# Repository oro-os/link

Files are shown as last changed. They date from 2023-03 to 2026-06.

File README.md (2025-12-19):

<div align="center">
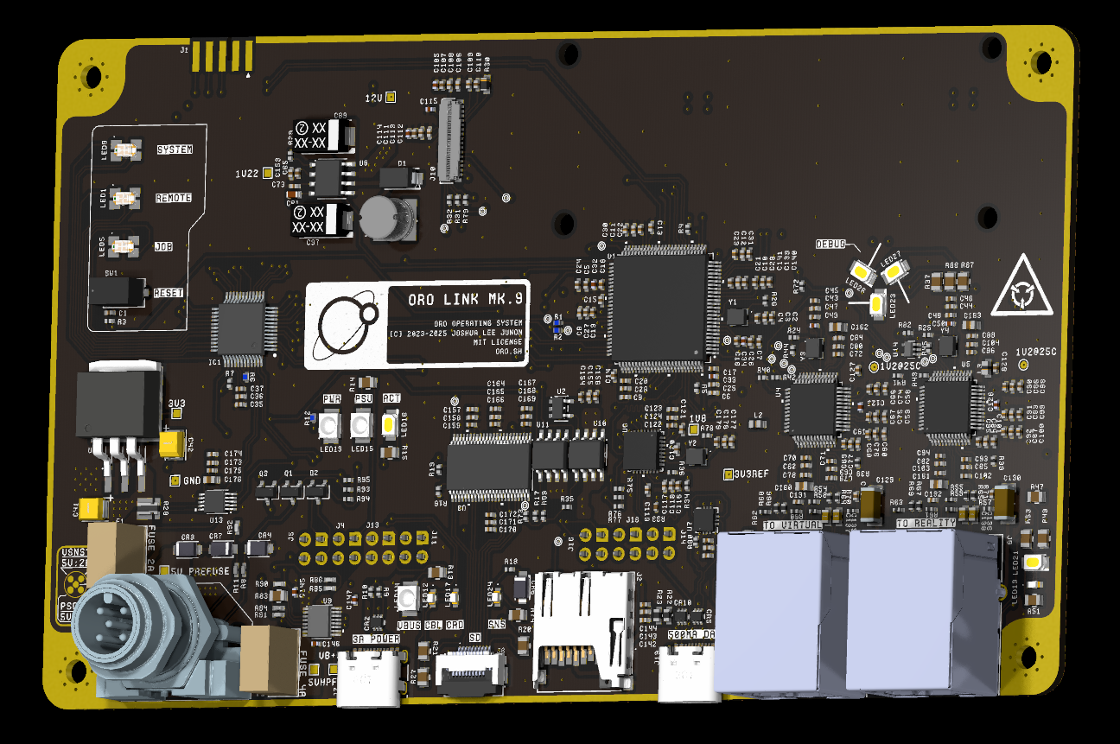
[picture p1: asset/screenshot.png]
	
</div>

# Oro Link

This is the Oro Link project, a set of custom PCBs, firmware, and server
infrastructure for the testing of the Oro Operating System via CI/CD pipelines.

The link is a physical board that interfaces with the ports and headers
of supported computers, devices, and boards, and runs firmware to obtain builds of
the Oro kernel and associated modules to send to the System Under Test (SUT)
for automated testing and reporting.

The Oro Link allows contributors to the Oro project direct access - via
pull requests - to test changes directly on real hardware
alongside emulated environments, allowing for changes to be tested
against niche or problematic hardware configurations.

## Project Layout

All PCBs are located in `pcb/`, where all of the server infrastructure and firmware for the PCBs
is located in `firmware/` since it's a workspace with some local dependencies (e.g. the protocol
spoken between the boards and the CI/CD daemon).

# License

<div align="center">
	
</div>

Part of the Oro Operating System project.

The Oro Link is released to the public, WARRANTY FREE
and provided AS IS. The Oro project and its contributors are NOT
responsible for any damages caused by the purchase, assembly, or operation
of the device, under any circumstances.

The Oro Link's PCB and associated custom footprints are released
under the [MIT License](LICENSE).

Unless otherwise specified, all Oro Link firmware (software code)
and all other materials are licensed under the same license.

Firmware dependencies are under their respective licenses.

The _Enter Command_ font used in part for text display is released CC-BY-4.0
by [Font End Dev (jeti)](https://fontenddev.com).

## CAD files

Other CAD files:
ProgrammerHousing.blend

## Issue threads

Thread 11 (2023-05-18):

Re-enable WWDG

Qix-, 2023-05-18:
The WWDG subsystem is not being initialized properly by the generated cubemx code, so the chip is going directly into reset after booting. Disable it for now and re-enable it later.

Qix-, 2023-05-18:
This is because the initialization circuit isn't waiting until the watchdog counter is within the window, thus immediately triggering a reset interrupt.

Qix-, 2023-11-23:
Going to close this. It's not been necessary, we're not operating these in realtime, and right now there's a strange bug somewhere in the netcode libs in the firmware that causes TFTP over UDP to lag the entire CPU, which would trigger the watchdog timer anyway.

Closed 2023-11-23.

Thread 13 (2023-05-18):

Fix power switch footprints

Qix-, 2023-05-18:
The power switch THT footprints (on the back top-right side of the link) are wrong; the pin columns are too close together.

Might also need to notify componentsearchengine of a flaw.

Qix-, 2023-05-30:
Nope, they were custom. My fault.

Qix-, 2023-05-30:
Welp that's frustrating. The datasheet is _very_ confusing.

The datasheet shows this:

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

We're using the 25146NAH model, which is listed as having 2.54mm pin centers. The diagram on the right clearly states "shown with 5.08mm centers", which is for the other column of models.

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

So, one might assume to make all centers 2.54mm for this particular model. That's the error on my part - the centers are indeed 2.54 between the pins in the same column, **but are always 5.08mm centered _between_ the columns**. This is only made evident by looking at the previous diagram for an unrelated model which is labelled "shown with 2.54mm spacing". Note that, again, the columnar spacing is still 5.08mm.

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

Very frustrating indeed. I've confirmed this is indeed the case with a caliper, and it's not a problem to have caught it in this revision - better than a later revision.

The next issue is that the parts aren't stocked until october, and I only have two of them. So I might just switch them out entirely and avoid APEM in the future. The programmer already has some nice switches that I believe would work from Werth, so I might just bring those over instead.

Closed 2023-05-31.

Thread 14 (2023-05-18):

Research USB D+/- resistors

Qix-, 2023-05-18:
Some designs I've seen use resistors on the D+/- lines of the USB. I'm not sure if they're necessary for this particular MCU but I should check. Right now they're direct-wired. The datasheet probably mentions them but I missed them, and no testing of the USB has been done yet to know.

Qix-, 2023-05-21:
It doesn't appear to be the case. Might be worthwhile to add R0 resistors inline though.

Qix-, 2023-05-30:
I can't find anything in the datasheet that would suggest this (although the datasheet is massive, so maybe I'm missing it). No sections regarding external components mentions them.

Closed 2023-05-30.

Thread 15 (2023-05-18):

Put pulldowns on MOSFET gate lines

Qix-, 2023-05-18:
While the MCU has built-in resistors, if the MCU is not on the board (during dev) or isn't functioning correctly, the default state should be low. Since the MOSFETS latch, we need to pull down the gate lines and drain out their current.

Closed 2023-05-21.

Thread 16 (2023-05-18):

Add debug pins on signal lines

Qix-, 2023-05-18:
At least for the next few revisions, debug pins should be put on the signal lines for various parts of the board. While soldering on the MCU pin lead wires is kind of fun and looks cool, really slows down the process and introduces a ton of surface area for error. Remove them once the board is ready for a full test.

Qix-, 2023-06-02:
I've gone back and forth on this about ten times now and decided it's not worth it given they'll only add signal integrity issues.

1. The ethernet SPI lines work, those are already tested.
2. The i2c lines for the indicator lights already work, those are already tested.
3. The SWD lines "work" (ST did not do a _great_ job implementing them) and a programmer is already designed and will be assembled at the same time as the link board. Plus, worst case, I can always solder to the Oro pad as it gives enough space.
4. The only debug lines left are the OLED SPI signals, which are NOT rated for 5v line the arduino pumps out, and I don't have any signal translators on hand (I could get some but.. why) but ARE rated for the MCU's voltages (as far as I can understand the very, very poor documentation). If this doesn't work, I'm going to resort to i2c and just... eat the framerate drop, I guess.
5. All of the power lines and signal lines have THTs associated with them already between the button and the power jack, and the power converter has been tested oodles of times at this point and is known to work.

Other than that, there are no other debug THTs that were marked for population, thus they have all been removed.

weiliddat, 2023-06-07:
> 3. The SWD lines "work" (ST did not do a _great_ job implementing them) and a programmer is already designed and will be assembled at the same time as the link board. Plus, worst case, I can always solder to the Oro pad as it gives enough space.

What’s the difference between using SWD line and using the programmer?

Closed 2023-05-30.

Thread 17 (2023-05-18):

Re-create footprint for schottky diode on 12v OLED step-up circuit

Qix-, 2023-05-18:
On the OLED's 12v step-up circuit, the schottkey footprint is really ambiguous as to where the polarity band should go when populating. I've soldered it wrong twice now, causing overcurrent in the step up IC and almost starting a small lab fire 🙃 Need to modify the silkscreen so it's clear which side the polarity band needs to go.

Closed 2023-05-31.

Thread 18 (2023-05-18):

Consider another OLED screen

Qix-, 2023-05-18:
These OLED screens are either faulty or their docs are wrong. Two tests in a row have garnered absolutely nothing - no backlighting, no response, nothing from any test, and turning on the power leads to the cable getting hot (still researching if that's normal).

Qix-, 2023-05-21:
I honestly thing it's our best bet. It's in supply, it's high resolution, it's a good shape, and it's cheap. It's white, which fits Oro's branding, and has decent documentation (for the actual display chip - the OLED itself has rather poor documentation).

Going to give it another go, but keep this open for now.

Qix-, 2023-07-02:
Just tried this with a Nucleo development board whereby the data signals are indeed the correct voltage. Nada. The ribbon is still getting insanely hot.

I think I'm going to make a breakout board for this and try to get to the bottom of whatever is causing this issue.

Qix-, 2023-07-13:
Finally found the problem with OLEDs.

Made a breakout board for the OLED port and just got it in yesterday. Soldered it all together today, hooked up one of the units and did some basic "same net" testing (idk what the real term is).

Turns out, not much connects, but a few pins - 1, 24, 26, and 30 - did. On the existing schematic, 1 and 30 were NC, and 24 and 26 were two of the bits of the data bus, which made _absolutely no sense_.

But it did. If you flip the pins upside-down, they correspond to (existing pins) 2, 6, 8 and 31. If you check the datasheet for the OLED screen, those are all of the 12v pins exactly.

So I went back and checked the datasheet for the connector itself. Port numbering looks correct. Then I check the datasheet for the OLEDs and notice something a little annoying.

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

Yep. That's the _bottom_ of the connector. I suppose it makes sense, it's just highly confusing. The ports are indeed flipped, and the two datasheets do not agree with the port numbering. I suppose lesson learned.

Will wire up the breakout board to a development Nucleo board soon just to make sure _something_ is working but as it stands this has solved the elusive OLED screen problem.

Going to close.

Closed 2023-07-13.

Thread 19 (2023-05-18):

Step down OLED logic lines to acceptable levels

Qix-, 2023-05-18:
Pending #18 as well as a MM test, step down the data lines from TTL to 2.8 or 2.4 (can't remember). Right now I _think_ they're 3v3 (again, need to test) so that might be frying the OLED data circuits.

Qix-, 2023-05-21:
This actually isn't needed. The Nano is doing SPI at 5v (or, at least, I bit-banged it at 5v at one point). Further I think there was a current leak as the ribbon was getting hot, so might be a power thing. I've tried to remedy this in b8ee6cae316a341383993e59f98217af3e48cfd9 with pulldowns in some cases instead of direct ties. We'll see if that fixes the issue.

The downside is I'll have to test using an entire board.

Closed 2023-05-21.

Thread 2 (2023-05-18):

Replace small 0.1u caps

Qix-, 2023-05-18:
They're too small and hand-solder correctly only about 60% of the time.

Qix-, 2023-05-21:
Make sure they're at lease 10v rated.

Closed 2023-05-30.

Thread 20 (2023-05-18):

Replace inline ETH resistors

Qix-, 2023-05-18:
The inline resistors between the transformer and the ethernet controller IC are also too small to reliably hand solder (perhaps successful 80% of the time). Replace them for slightly bigger packages. The packages of the resistors in the bottom right of the board (as of rev 4, 072a0d0983c60869b018b50924e15593dac61d36) by the GNDPWR mounting hole solder perfectly and are probably as small as I'm willing to work with.

Closed 2023-05-30.

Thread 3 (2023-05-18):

Replace Oro 6p VCC line with T_VCC input

Qix-, 2023-05-18:
The current VCC line on the Oro test pad is used for powering the board but

1. it's unnecessary as the board will always be in an environment where it has power, and
2. the V3MODS doesn't have enough current rating to power everything on the board anyway

So instead, we need to give back the reference voltage via the link's T_VCC line. This also reduces the BOM, which is nice.

Closed 2023-05-21.

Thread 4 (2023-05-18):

Tie programmer NRST to GND

Qix-, 2023-05-18:
The programmer will be used in Under Reset mode, thus the NRST on the link needs to be tied to GND. I don't know why, this was just the findings during test.

Closed 2023-05-19.

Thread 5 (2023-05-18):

Remove "power from link" switch on programmer module

Qix-, 2023-05-18:
Title. Given #3 the extra switch is no longer necessary.

Closed 2023-05-21.

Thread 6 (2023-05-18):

Change Oro 6p GND pin to PB2/BOOT1 pin

Qix-, 2023-05-18:
... and tie it to 3v3 on the programmer module when the flash switch is on. **Use T_VCC line instead of 5v to tie it high** and also use this to power the flash warning LED circuit instead (or, perhaps, use it to power a MOSFET and tie the whole thing low with a pull-down).

Closed 2023-05-21.

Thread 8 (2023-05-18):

Add debug pins to programmer

Qix-, 2023-05-18:
so that we can solder on a single v3mods to a programmer board and use it over and over again instead of having to rely on shoddily soldered lead wires.

Closed 2023-05-21.

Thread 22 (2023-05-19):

Reverse polarity of cyan LED

Qix-, 2023-05-19:
Right now the cyan LED is being used as link status, which is high when there is _no_ link, and low when there _is_ a link. We should invert it using a single gate inverter.

Qix-, 2023-05-19:
Actually the link LED might just be a case of needing to reverse it and connect to VCC instead of GND.  Need to re-read the datasheet to make sure that's the case. Not sure if it's current sinking it when low.

Qix-, 2023-05-19:
Yes, correct. Reversing polarity and hooking it up to VCC instead of GND will work.

Closed 2023-05-19.

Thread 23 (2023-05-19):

Move ETH line ESD IC's before transformer

Qix-, 2023-05-19:
Woops. Their breakdown voltage is 4.5v, but the lines are at 28+v. That might be why the chip itself is working fine but nothing is being transmitted. I also measured the voltage between GNDPWR and GND and indeed there were 28v. I misread the diagram...

Will test desoldering them to see if, at least, the lines work.

Qix-, 2023-05-19:
In fact, maybe it's worth simply removing them entirely. The ENC28J60 already has ESD protection built in, up to 2kv.

Closed 2023-05-19.

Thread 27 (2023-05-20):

Combine three posts on programmer

Qix-, 2023-05-20:
Right now the programmer has 6 posts - three in the oro 6p landing mount pattern, and three in an inverse configuration to mount the middle piece to the programmer. This is actually unnecessary and only removes room for the brace mounting holes, which were a bit painful to get in. The nylon m3's can instead just be daisy-chained together in the same configuration as the 6p landing mount holes to save space for the brace mounts.

Closed 2023-05-21.

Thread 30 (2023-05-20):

Re-layout power caps

Qix-, 2023-05-20:
The power caps on the voltage regulator make no sense where they're currently placed. They need to be much closer to the pins.

Closed 2023-06-02.

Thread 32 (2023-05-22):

Replace 10k resistors with smaller package

Qix-, 2023-05-22:
The current 10k's are ridiculously huge. They really need to be a bit smaller.

Closed 2023-05-30.

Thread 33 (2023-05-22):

Replace GNDPWR capacitors with smaller package

Qix-, 2023-05-22:
... if possible. They're one of the largest auxiliary components on the board at this point.

Closed 2023-05-30.

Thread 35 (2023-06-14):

Replace crimp probe receptacles with solder cup

Qix-, 2023-06-14:
On the programmer, the crimp receptacles look nice but are functionally very hard to CAD for, as after disassembly and re-assembly the metal has fatigued just enough not to have any grip anymore. Now they're sliding everywhere.

I'll trade _functionally solid_ for _I might need to get more solder cup parts_ any day.

Qix-, 2023-06-30:
Closing in lieu of a non-fancy programmer.

Closed 2023-06-30.

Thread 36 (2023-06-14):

Replace 7oz spring force probes with 4oz

Qix-, 2023-06-14:
The 7oz spring force is way too much for what is needed.

Qix-, 2023-06-30:
Closing in lieu of a non-fancy programmer.

Closed 2023-06-30.

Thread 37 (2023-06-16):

Make power terminals on VGA mount 2.54mm 2p slots

Qix-, 2023-06-16:
Right now the VGA mount's power holes were meant for just some wires but I realize now that makes no sense. Further, they're about 3mm apart which means I can't soldier on a 2p post directly. The holes are also too small, and the rings are too narrow for a good solder joint.

Better to import one of the 2p footprints and use that instead.

Closed 2023-07-02.

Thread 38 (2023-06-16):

Switch out power switch for another one

Qix-, 2023-06-16:
The mounting pads on the power switch are now correctly positioned but the copper surrounding the hole is too narrow to make a good solder joint.

Qix-, 2023-06-30:
I think I just need to replace it entirely. The switch is out of stock on Mouser and will be for a while, and I have one left.

Qix-, 2023-07-01:
This power switch is a continual pain in my ass. Further, it's not really useful given that the PSU always has a switch of its own.

Going to simply remove it.

Closed 2023-07-01.

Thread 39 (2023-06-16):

Put all component voltage sources behind MOSFETs

Qix-, 2023-06-16:
Debugging some voltage stuff is causing issues when they are all eating power at boot. Being able to programmatically turn on and off their power is going to prove useful.

Qix-, 2023-07-27:
For anyone coming across this issue in the future, this was a major mistake and the sole reason why there will be a revision 7.

Closed 2023-07-01.

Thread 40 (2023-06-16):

Get rid of programmer and landing pad, integrate V3MODS directly onto link

Qix-, 2023-06-16:
Title. The programmer is a cool idea aesthetically but isn't really helping me debug this thing. Plus, the leads between the two are so touchy that the SWD lines aren't really working well at all currently.

I also need to get *ANY* programmer + MCU working to understand how this thing needs to be wired up, because I just can't get the STM32 working with the programmer.

Bummer.

Qix-, 2023-06-30:
Update: I made a second board with just the MCU. It worked first try **at 8000KHz**, no less. The connection has been dropped **ONCE** since I started. Firmware flashes instantly. Debug LED and the PSU_ON MOSFET both worked first try.

So there was clearly an issue with the first board, either with the chip or with the programmer setup (I'm leaning toward the second).

The V3MODS are cheap. They're in stock pretty much all the time. Having them directly on the boards would be great.

Closed 2023-07-02.

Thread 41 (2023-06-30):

BOOT0 / BOOT1 pullup/pulldown are backwards

Qix-, 2023-06-30:
BOOT0 is currently pulled up and BOOT1 pulled down, which is backwards. Oops. As it stands, a standalone board would immediately and irreversibly boot into programmer mode. This is of course remedied with lead wires shorted to GND/3V3 respectively but that of course doesn't 'solve' the issue.

Closed 2023-07-01.

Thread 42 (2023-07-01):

Add flash switch

Qix-, 2023-07-01:
The flash switch will switch BOOT pins on the back to accompany the programmer. In _theory_ I could flash my own programmer to use the GPIO pins but the switches are cheap and SMT and I don't want to bit off more than I can chew with the already sort of stingy programmers.

Qix-, 2023-07-02:
Ended up just going with a few MOSFETs and a short 2p configuration

Closed 2023-07-02.

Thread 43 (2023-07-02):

Replace 3v3 regulator with one with higher amperage ratings

Qix-, 2023-07-02:
Pretty sure we're going to be bumping up against that 1A point on the voltage regulator. In fact I'm pretty sure that's why I've seen a few weird voltage characteristics during testing.

Closed 2023-07-02.

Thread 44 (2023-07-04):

Make RJ45 inverter board

Qix-, 2023-07-04:
Finally found a board-mounted RJ45 connector (not receptacle) and ordered 10 of them. Just need to build the RJ45 back panel reverse card using the existing non-magnetic jacks I have.

Qix-, 2023-07-05:
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
certainly one of the weirder parts I've made.

Closed 2023-07-05.

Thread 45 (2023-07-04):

Find heatsinks for MCU

Qix-, 2023-07-04:
Title. This thing needs a sink.

Qix-, 2024-06-02:
Not necessary anymore after switching to Embassy. Current draw is significantly lower due to clever usage of async, and thus temps have remained quite low - chip remains only slightly warm to the touch.

Closed 2024-06-02.

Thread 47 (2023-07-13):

Re-wire OLED port to match corrected numbering

Qix-, 2023-07-13:
After #18 was finally solved, I need to do some testing and - assuming the tests go OK - re-wire the OLED port to have the flipped numbering sequence.

Closed 2023-07-14.

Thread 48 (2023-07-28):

Remove MOSFETs in lieu of reset pins

Qix-, 2023-07-28:
Learned my lesson. #39 was a mistake.

Qix-, 2023-08-02:
Just the eth, oled and indicator subcircuits.

Closed 2024-06-08.

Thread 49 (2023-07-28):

Switch to W5100

Qix-, 2023-07-28:
The ENC28J60's read/write rising/falling edge mechanism is inherently incompatible with STM32s.

From [this comment](https://community.st.com/t5/stm32-mcu-products/hi-everyone-i-m-trying-to-connect-my-stm32f429i-disc1-to-lan/m-p/282696/highlight/true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):

> The ENC28J60 is an older ethernet MAC/PHY and has some issues when used with an STM32. Microchip has a newer ENC424J600 10/100 ethernet controller with a much better SPI interface. I used both many years ago. The older ENC28J60 is not easy to use and I would not recommend going forward with it since there is a far better alternative.

> One issue is read/write clock edge for the SPI clock. Writes to the ENC28J60 are on the rising edge, but read are clocked on the falling edge. You need to reconfigure the SPI clock polarity depending on transfer direction. STM32 SPI ports only read/write on the same edge. Check the timing diagrams on the ENC28J60 to see how data is read and written. If you use the wrong edge you get invalid data, as you see with 0xFF.

> Also, make sure the chip select remains on past the last bit clocked in/out. The SPI port has a flag to inform when shifting is complete. Otherwise data is lost.

Would have never guessed, to be honest. This is a huge bummer, and renders the rev6 effectively. Switching clock polarity doesn't seem to work anyway as the comment suggests.

Going to do some more research tomorrow with the standalone ENC28J60 modules + the nucleo boards just to see if that's really the case. The external ethernet jack is correctly killing the link LEDs when hard-reset but the system ethernet jack is not. This also indicates a problem with the circuit on the system ethernet, although both have been tested standalone.

Further, it's probably worth upgrading to 100 instead of staying on 10, anyway.

Qix-, 2023-07-31:
The assertion made in the comment doesn't seem to be true. Using a logic analyzer on this shows that the chip is actually sending/receiving correctly (figured out the ethernet chip clock wasn't soldered on all the way for the external ethernet, hence why I was getting garbage back from it). It appears to be reading/writing just fine.

Another lesson learned is that MCU pins pulled high via an external resistor (as is the case with many signal lines on the board) need to be configured as open drain outputs rather than push pull. I knew this conceptually but hadn't actually bothered to check the IOC config for them. This is why the chip select line wasn't doing anything, thus the ethernet chips seemed bricked.

I will put this on the backburner for now as I think 10base-t will be sufficient.

Qix-, 2023-08-05:
Upon discussing with the lead Embassy dev over Matrix it was suggested to switch to the W5500 instead. Further, it already has a fully featured driver for Embassy which will save considerable time.

Closed 2024-06-08.

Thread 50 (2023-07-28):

Investigate STLINK serial debugging

Qix-, 2023-07-28:
I can't seem to get the STLINK to pick up any sort of serial output, which is making debugging quite difficult. Need to investigate why this is the case.

Qix-, 2023-07-28:
Already on serial 7 via the VCP. Just need to use arduino's COM port viewer to see the output, weirdly enough the IDE doesn't include this functionality.

Closed 2023-07-28.

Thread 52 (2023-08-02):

Put 5VSB, RST and PWR onto photocouplers instead of MOSFET

Qix-, 2023-08-02:
Title. The 5VSB is hitting some caps on the mobo and is not properly reading Vgs on the FET. Switching to a photocoupler will probably help.

For now, bridging unconditionally is the best workaround. In theory we could also replace the N-Channel with a P-Channel assuming the G/D/S pins match up and switch the gate line to an output open drain.

Qix-, 2023-08-04:
Also, need to put the power switches on them as well. At least on this board, the RST is working but PWR is not. I just need to use proper photocouplers for those.

Further, the ATX24's PS_OK line has been replaced with a line to the SUT's PS_ON line.

Qix-, 2024-06-08:
None of this was necessary.

Closed 2024-06-08.

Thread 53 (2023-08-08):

Rev6 errata tracking

Qix-, 2023-08-08:
- [x] pins 4 and 5 of power connector (J2) must be shorted
- [ ] pin 2 of power connector (J2) must go to to SUT's PSU_ON pin (green line); PS_OK is no longer used and MCU pin must be configured as pullup input
- [x] ethernet controller chip enable MOSFETs (IC6 / IC9) omitted;  pins 2 and 3 must be shorted
- [x] indicator lights enable MOSFET (IC16) omitted; pins 2 and 3 must be shorted
- [x] OLED charge pump enable pull-up resistor (R24) omitted
- [x] OLED VCC MOSFET (IC5) omitted; pins 2 and 3 must be shorted, and pin 1 needs lead wire to pin 1 of OLED charge pump (IC4)
- [x] OLED enable MOSFET (IC3) omitted; pins 2 and 3 must be shorted
- [x] SUT power and reset MOSFETs (Q2 / Q3) must be held high for >=100ms to trigger
- [x] indicator lights current limiting resistor (R58) _should_ be replaced with 10k resistor
  - future fix should use 12-13k
- [x] USB VBUS line (PA9) needs to have a port for it to connect to the VBUS line on the MB. Might also need a common ground (even though... probably not, but can't hurt).

Qix-, 2024-06-08:
> pin 2 of power connector (J2) must go to to SUT's PSU_ON pin (green line); PS_OK is no longer used and MCU pin must be configured as pullup input

I'm not entirely sure this makes sense to me. I don't know what I was trying to convey here. Going to ignore it for now because I can't see any corresponding changes on the board itself.

Closed 2024-06-08.

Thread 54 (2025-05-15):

Link MK.8 Errata

Qix-, 2025-05-15:
## Test Progress

The subsystems I've tested so far are:

- [x] Power delivery - 5V
- [x] Power delivery - 3V3
- [x] Power delivery - 12V
- [x] Power delivery - USB VBUS (power only, left port)
- [x] Power delivery - USB VBUS (data, right port) &dagger; (**UPDATE:** Tentatively correct; will double check tomorrow)
- [x] Power monitor (I<sup>2</sup>C)
- [x] LED controller (I<sup>2</sup>C)
- [x] MicroSD card slot - uC to card
- [x] MicroSD card slot - card to peripheral
- [x] System ethernet
- [x] External ethernet ~~Will not test; problems found and are assumedly the same. Chip responds to both.~~ Will test. ~~@grouvie had the idea in discord to instead rewire an ethernet cable instead of resoldering the port. That'll let me test the external ethernet, too. Was just a sunday when I tested the system ethernet and thus couldn't buy a new cable and didn't want to destroy the few I already have.~~ That won't work; the port is mis-wired pre-magnetics, so a keystone will do nothing.
- [x] External ethernet wake on LAN &dagger;&dagger; -- **UPDATE:** Not feasibly testable given 1) incorrect logic gate and 2) missing embassy support. I believe the schematic to be correct and the normal interrupts work correctly. Will go out on a limb and say this will work with firmware updates.
- [x] USB HS via ULPI &dagger;&dagger;&dagger; -- **UPDATE:** Does not work; I think I know why. **UPDATE2:** Confirmed. Performed a hack, got it to work. See https://github.com/oro-os/link/issues/54#issuecomment-2898650823.
- [x] OLED comms (SPI) - **UPDATE:** Won't work; UltraLibrarian footprints differed from the ComponentSearchEngine footprints and I didn't catch it.
- [x] RS-232 USART comms
- [x] Auxilliary GPIO / Power pins
- [x] Microcontroller programming and debug via ST-LINK edge connector

&dagger; Requires the ULPI testing to be successful, since the MOSFET controlling power delivery is controlled by the ULPI PHY.

&dagger;&dagger; Will only be able to test the wakeup handler, as 1) ~~external ethernet will not be functional~~, and 2) the logic gate is incorrect. **UPDATE:** Will be able to test the WOL signal at least.

&dagger;&dagger;&dagger; The USB-C port used right now is poorly chosen for the board. A new one will need to be picked that is easier to work with. Therefore it's likely that just the headers will be tested.

## Major Issues

> **NOTE:** Major issues have been turned into sub-issues. See the list below this top level post.

## Minor Issues
Issues that don't require fixes or workarounds to test the board.

> **NOTE:** Minor issues have been turned into sub-issues. See the list below this top level post.

## Polish Issues
Issues involving the board's presentation, ease-of-testability, etc.

> **NOTE:** Polish issues have been turned into sub-issues. See the list below this top level post.

## Prototype Board Issues & Modifications

These are problems with the assembly of the first MK.8 board, not issues with the board itself. More for keeping track of issues when testing the board.

- SDCard sense is tied to ground due to soldering issue. Might want to investigate a less error-prone microSD slot, as that pin is very close to the grounded housing. Alternatively, do not ground chassis (though that's not really a solution). Pull-up resistor on pin 9 was removed to avoid current leak.
- "to virtual" ETH will need some replacement passives as they soldered together and broke during adjust; were removed entirely. Will not work correctly until then.
- LDO input pins had to be swapped (UltraLibrarian has the incorrect footprints)
- Ethernet jacks were both desoldered and re-wired.
- ULPI system was rigged up entirely with an external clock to test USB functionality.
- External ethernet now has a lead wire to pull reset high instead of low.
- Incorrect OLED SS resistor was removed for testing. No effect on OLED functionality.

## Checks

- [x] Make sure external Ethernet is enabled even when MCU is off for WOL (not at machine to check right now but it crossed my mind?
- [ ] Triple check the USB port power indication resistor values.

Qix-, 2025-05-21:
# USB Post-Mortem (or... Post-Op Report)

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

Right so the PHY was miswired. The documentation is super unclear. **If you're ever trying to figure out how to wire up a USB3340-EZK to an STM32 (or similar uC)** here are my findings as a first-time ULPI PHY implementer:

- `CLK` is an **input** to the MCU, always. It is a 60MHz clock.
- Typically, it's also an input to PHYs unless the PHY can generate it itself (the USB3340 can).
- The USB3340 has two options (I'll restate them here in less ambiguous terms, because the datasheet is terrible at communicating this):
  - The Pin 1 (CLKOUT) pull-up mode, which is sampled once at boot, and tells the chip that the REFCLK signal is going to receive _the same_ 60 MHz clock that the CLK line receives (and that is also routed to the MCU).
  - The REFCLK/REFSEL[2:0 pin mode, whereby REFSEL lines indicate which frequency an external clock (as in, another BOM item) will feed a signal into REFCLK. The chip uses the hard-wired frequency setting to perform clock multiplication to produce its own 60MHz output on CLKOUT (as well as using it internally) in order to be sent to the MCU.

**When in doubt, choose the REFCLK/REFSEL option** (second mode) and length match ALL ULPI lines to the MCU such that clock signal propagation delay is not a factor (all signals reach the MCU at the same time, including the clock and data lines, etc.)

My problem is that I erroneously assumed the MCU was the "clock master" since it has an elaborate system of PLL clock circuitry and that CLK was an MCU output, not an input, and wired it to REFCLK. I then pulled CLKOUT up (correctly) thinking that would tell the chip to use REFCLK as a 60MHz clock.

## The Surgery Process

I had to desolder the USB3340 from the board, sever the ground lines pulling the REFSEL pins down, as well as the CLKOUT line. I also had to sever REFCLK further down the line and expose the remaining trace that was connected to the REFCLK pin. I then re-soldered the PHY back on using a heat gun and used a few 0201 49R9 resistors to create "standoff" leads for the REFSEL lines.

A length of flexible wire was cut and one of the strands was removed to act as a bus bar, soldered across the outermost resistor terminals of the REFSEL resistors, and bent upward, and then soldered to a larger, rigid wire floating in the air and connected to a 10K resistor, which itself was soldered to a length of stripped rigid wire that acted as the 3V3 bus.

The 3V3 bus was terminated at a 3V3 test point on the other side of the board, as well as the Vin pin of an extra 24MHz clock I had (which I use to clock the MCU itself, coincidentally) - which is perfect, because 24MHz is one of the 8 different clock speeds the PHY supports, and corresponds to REFSEL[2:0] == `0b111` (hence why they all got pulled up). Otherwise I'd have needed to order a new clock just to test this. I got lucky.

The ground was soldered via a flexible wire to one of the larger analog<->digital bypass capacitors on one of the ethernet circuits in the bottom right of the board, just because it was easier than leading it back to a test point across the board and provided a bit more support for the clock to hover in mid-air.

The clock line itself was then soldered via a rigid wire bent in a sort of right-angle 'S' shape from in the air and down to the exposed REFCLK trace on the board.

I then took another strand of flexible wire and soldered it directly between pin 1 of the USB3340 (CLKOUT) and pin 26 of the STM32 (ULPI_CLK).

Finally, I sacrificed a USB 2 cable, stuck some single-pin 2.54 male headers on it, and threaded them into the THT holes for the eventual pin headers for the x86 installations (since the USB port has since been desoldered and it's a terrible model and I didn't want to flip the board _back_ over to re-solder it with all the delicate test lines basically holding on with mostly flux, a hope and a dream).

After a little bit of continuity testing to make sure nothing was shorted, I was ready to test.

I confirmed the 24MHz line was producing a reasonably stable signal via a Saleae, and then similarly confirmed the ULPI CK line was producing a 60MHz signal. They were. I booted up the firmware, and a new log messaged popped up - "USB in standby". I then plugged the makeshift USB cable into my machine and got a welcome surprise in USBDeview:

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

Highly polished MS Paint diagram of the test setup:

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

(Missing in diagram: line between CLKOUT and MCU's ULPI CLK pin 26 on the STM32F479VGT6)

More images (last three do not show the CLKOUT -> ULPI_CLK lead wire, that was done the next day):

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

Thank you for coming to my TED talk.

Closed 2025-06-12.

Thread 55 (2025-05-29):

LDO input/ground pins are backwards

Qix-, 2025-05-29:
LDO (5V->3V3) pins 1 and 3 (input and ground) are reversed. UltraLibrarian should be notified as that's where the footprint came from.

Qix-, 2025-05-29:
Fixed the schematic in 636e4ea77d1af672f0766a501f20314f9975c11c.

Closed 2025-06-02.

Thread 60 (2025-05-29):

Replace ethernet pulldowns from 82R to 49R9

Qix-, 2025-05-29:
The RX pair pulldowns in the schematic are 82R but those were from the reference schematic with the external transformer. The one with the integrated transformer still shows them as 49R9. I wouldn't think that'd make that much of a difference but it could be it.

**UPDATE:** Replaced with 49R9's. ~~Didn't help.~~ Might have helped. Will replace them anyway as they worked with the rewire and are one less BOM entry anyway.

Closed 2025-05-29.

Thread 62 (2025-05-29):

ULPI Clock lines are improperly wired

Qix-, 2025-05-29:
> **NOTE:** This was converted to an issue from the greater #54 issue, hence the strange format. See https://github.com/oro-os/link/issues/54#issuecomment-2898650823 for more information.

ULPI PHY is not wired correctly. It needs a clock with a frequency specified by the `REFSEL[2:0]` pins into the `REFCLK` line; The ULPI `CLK` line is currently wired into `REFCLK` which is nonsensical as it's an MCU input (the Stm32 docs are very confusing about this - see <https://www.st.com/resource/en/application_note/an4879-introduction-to-usb-hardware-and-pcb-guidelines-using-stm32-mcus-stmicroelectronics.pdf> page 19). `CLKOUT` is currently tied to VCC as that's what the USB3340 shows is a valid configuration but that means that the clock would have had to have come from the STM32's MCO line and a special 60MHz signal would have had to be configured - neither of which are happening currently and cannot be done as that requires a re-fab (and has downsides since that means you have to worry about trace length and signal propagation delays). The CLKOUT should instead be the ULPI `CLK` line into the stm32 and should also be length matched. I also saw a suggestion of adding 100R line resistors to the non-`CLK` lines in the event of USB failure but to be honest I'll omit those for now (maybe 0R's to start, in order to have the footprints there, if I really want to be robust).

Closed 2025-06-02.

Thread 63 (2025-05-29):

OLED connector is mirrored

Qix-, 2025-05-29:
OLED connector wiring is upside-down (well, mirrored) again. The first time it was from reading the docs wrong. This time it's because I switched out the footprint for an UltraLibrarian one that has the pins backwards. Will need to re-wire and _triple_ check the footprint this time to make sure it matches the wiring of the previous MK.7 working board. Now I understand why I made the (still stupid, but now slightly less stupid) mistake of getting the OLED connector backwards. I've learned my lesson now not to trust UltraLibrarian footprints.

Closed 2025-06-02.

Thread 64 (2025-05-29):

Test points under SD switch IC (oops, rookie mistake) - need a courtyard on the TP footprint before re-placing them.

Qix-, 2025-05-29:

Closed 2025-06-02.

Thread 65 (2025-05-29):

External ethernet wakeup interrupt polarity gate is AND. It should be XOR. Yet another rookie mistake.

Qix-, 2025-05-29:

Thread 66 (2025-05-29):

`EXTETH_~{INT}_OR_WKUP` needs a pull-up.

Qix-, 2025-05-29:

Qix-, 2025-05-30:
Just realized maybe pulling it up isn't the right approach in the RST state since I'm not sure if the XOR gate will pull it low, but at least the pad will be there and I can desolder the resistor if it doesn't work.

Closed 2025-06-02.

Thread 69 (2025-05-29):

USB impedance matching is wrong since kicad has two columns for netclasses - one for single-trace width and another for "DP width", which is for diff pairs. The impedance matched width/spacing were only populated in the single trace width column, not the DP columns, so they didn't take effect when making the USB lines.

Qix-, 2025-05-29:

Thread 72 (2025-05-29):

Ethernet clock modules fail when reflow soldered

Qix-, 2025-05-29:
Ethernet clock modules are cheap, and don't seem to indicate a solder profile. It's unconfirmed but I don't think they're rated to withstand the ~200C soldering temps. I've confirmed they're wired correctly but they have 1) confusing docs and 2) don't actually generate a clock signal, which leads me to believe they got grilled alive when I put them through the oven. Might want to switch them out with a slightly higher-end clock that has an actual solder profile in the documentation (just like the one for the microcontroller). UPDATE: I can confirm that replacing the clocks works. It's almost definitely an assembly/heat issue with the KC2520Z25.0000C1KX00. If I am to continue using them, I'll need to omit them from the initial bake and manually solder them after the fact.

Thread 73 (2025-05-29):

Find new USB-C receptacles

Qix-, 2025-05-29:
The USB-C port THT leads are not long enough to actually reach through the board, and are a huge painpoint when soldering. Might invest some time into a better port because I have no idea if these are being soldered correctly (hard to test).
- https://www.mouser.de/ProductDetail/GCT/USB4105-GF-A?qs=KUoIvG%2F9IlY%2FMLlBMpStpA%3D%3D
- https://www.mouser.de/ProductDetail/Molex/221610-0001?qs=rQFj71Wb1eUJvn%2Fa5QnTUA%3D%3D

Closed 2025-06-02.

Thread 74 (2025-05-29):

External ethernet RST line needs to be pulled up

Qix-, 2025-05-29:
Ethernet RST is pulled low, which means WoL won't work. External ethernet needs to be pulled high, system ethernet should be pulled low. The resistors will have to be moved to the main block sheet instead of the ethernet sheet. Make a note in the ethernet sheets that the "downstream" consumer of the sheet needs to include a pull up/down resistor.

Closed 2025-06-02.

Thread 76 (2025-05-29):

Text is a hair too small, silkscreen process from JLC had a hard time with it

Qix-, 2025-05-29:

Qix-, 2025-06-06:
One of the things I'm going to do differently this time is use the higher precision silkscreen process when printing.

Closed 2025-06-08.

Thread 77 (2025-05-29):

Solder mask on edges must be manually subtracted in designs

Qix-, 2025-05-29:
JLCPCB does not add a "border" to top/bottom faces when edge plating (might also be a good idea to add a keepout zone for the sides of the non-GND layers, too, just in case there's a short or something - short-testing showed they were isolated correctly though)

Closed 2025-06-07.

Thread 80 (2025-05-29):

Power pins have thermal reliefs

Qix-, 2025-05-29:
Probably fine, but I'll remove them. A little harder to solder, yes, but should be OK for just the few that are necessary.

Qix-, 2025-06-06:
This was fixed a while back.

Closed 2025-06-06.

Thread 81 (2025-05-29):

Missing labels on LEDs near power-only USB-C port.

Qix-, 2025-05-29:

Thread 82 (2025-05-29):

Power monitor alert pin should be wired to interrupt

Qix-, 2025-05-29:
We could have wired up the alert pin from the power monitor. I don't know why I didn't. There are definitely extra interrupt pins available.

Closed 2025-06-02.

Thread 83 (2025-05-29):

Maybe swap one of the back RGB lights with a few white LEDs to allow for a better "white balance" control.

Qix-, 2025-05-29:

Closed 2025-06-02.

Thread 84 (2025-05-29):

Replace power system connectors

Qix-, 2025-05-29:
Really not in love with the 60's-era green power plug. They're definitely nicer than anything I've had before, but black would be a lot nicer. Plus the cable plugs don't have a nice way either attaching a cable nor securing the cable to the board with screws (they have screws but they're seemingly not actually for securing the cable to the board) so I'm not entirely sure what the thought process there was. Plus, they're expensive for how non-practical they are. I'd love to have a proper 2p power / 2p data connector that is black, if possible.

Qix-, 2025-05-29:
[Basket_May29_1027AM.pdf](https://github.com/user-attachments/files/20512196/Basket_May29_1027AM.pdf)

Qix-, 2025-06-02:
They've been placed!

Closed 2025-06-02.

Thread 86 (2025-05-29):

Status LED labels on top left should have the same knockout width, even if the text is shorter.

Qix-, 2025-05-29:

Qix-, 2025-06-02:
Kicad can't do this, it seems, without creating manual graphics. Not going to bother.

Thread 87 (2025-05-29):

Power-only USB port should state 1.5A (since it's the 2023 model [not a year]), or the power supply switch should be switched to a 2022 (probably better, as the board is only rated for 2A and 1.5A going to the USB side of things is probably not great). The USB-C power negotiation resistors will need to be checked.

Qix-, 2025-05-29:

Qix-, 2025-06-02:
Final ratings:

- PWR+Data USB = 500mA
- PWR Only via Bus Power = 500mA (reports 3A via CC resistors but power switch will OC interrupt after 500mA)
- PWR Only via Aux +5VP line = 3A

Qix-, 2025-06-02:
Just need adequate labeling of ratings etc. now.

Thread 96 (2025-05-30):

Expose supplementary 5V lines in power cable for external VBUS powering

Qix-, 2025-05-30:
For the USB VBUS power rails on the PWR only side (that is controlled by the VBUS mosfet), in the event the current rating of the board is too low, allow for the power cable to include extra lines that can be switched on to provide a higher current +5V line.

- Requires the switch has a higher current rating
- Need to check that mixing the two won't cause problems, else I'll need two switches
- Need to use diodes to enforce the power only flows in the direction of the port, not back downstream to the power cable or the main board 5V rail.
- Might want to have jumpers for the CC resistors to indicate a higher current rating.

Should probably wait on #87 beforehand.

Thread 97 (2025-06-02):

MicroSD card slot does not have high enough current rating

Qix-, 2025-06-02:
GPIO pin currently drives Vdd but there could be currents up to 150mA under max SPI writes bursts, and the STM32 GPIO pins are rated at 25mA sourced max. Minimum is technically 20mA for microsd but that's really not enough. Need a power switch.

Closed 2025-06-02.

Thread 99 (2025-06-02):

PS_ON needs an N-FET

Qix-, 2025-06-02:
PS_ON is 5V rated. AbsMax GPIO pin voltage is Vss+4V.

Sigh. At least it can be N-FET. It's also marked as an open drain (active low) but that'll make it active high, just as a note.

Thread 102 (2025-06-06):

Reduce pin header count surrounding the RS232/TTL voltage UART

Qix-, 2025-06-06:
So I just noticed I put two pin headers for the RS232/TTL voltage UARTs which I really don't like. Only one should be connected and it should default to being off until I know which one is which and it's been explicitly configured in the firmware. Otherwise it risks either zapping the MCU or the SUT due to RS232 voltages being too high on either side.

Even worse is if someone connects the wrong one, or both at the same time. Should really invest in a proper switch there.

Qix-, 2025-06-06:
Actually, I think I might take an entirely different approach and remove the charge pump altogether, and only talk to TTL voltages.

Then I'll make a smaller adapter board that hooks directly onto the 9 pin adapter on ATX, is powered by the board via a 3V3 and GND line and then only use TX/RX. No CTS/RTS.

That'll cover the x86 case as well as the ARM/RISC cases. I just need a silkscreen on the back for the UART connections with the lightning symbol that states "NOT RS-232 COMPATIBLE".

Qix-, 2025-06-06:
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

Then here I can change these to an 8x2 and a 6x2 and place the 6.2 over the SMT parts so the pins don't overlap with the througholes/mounts as much. That's a better approach.

Closed 2025-06-06.

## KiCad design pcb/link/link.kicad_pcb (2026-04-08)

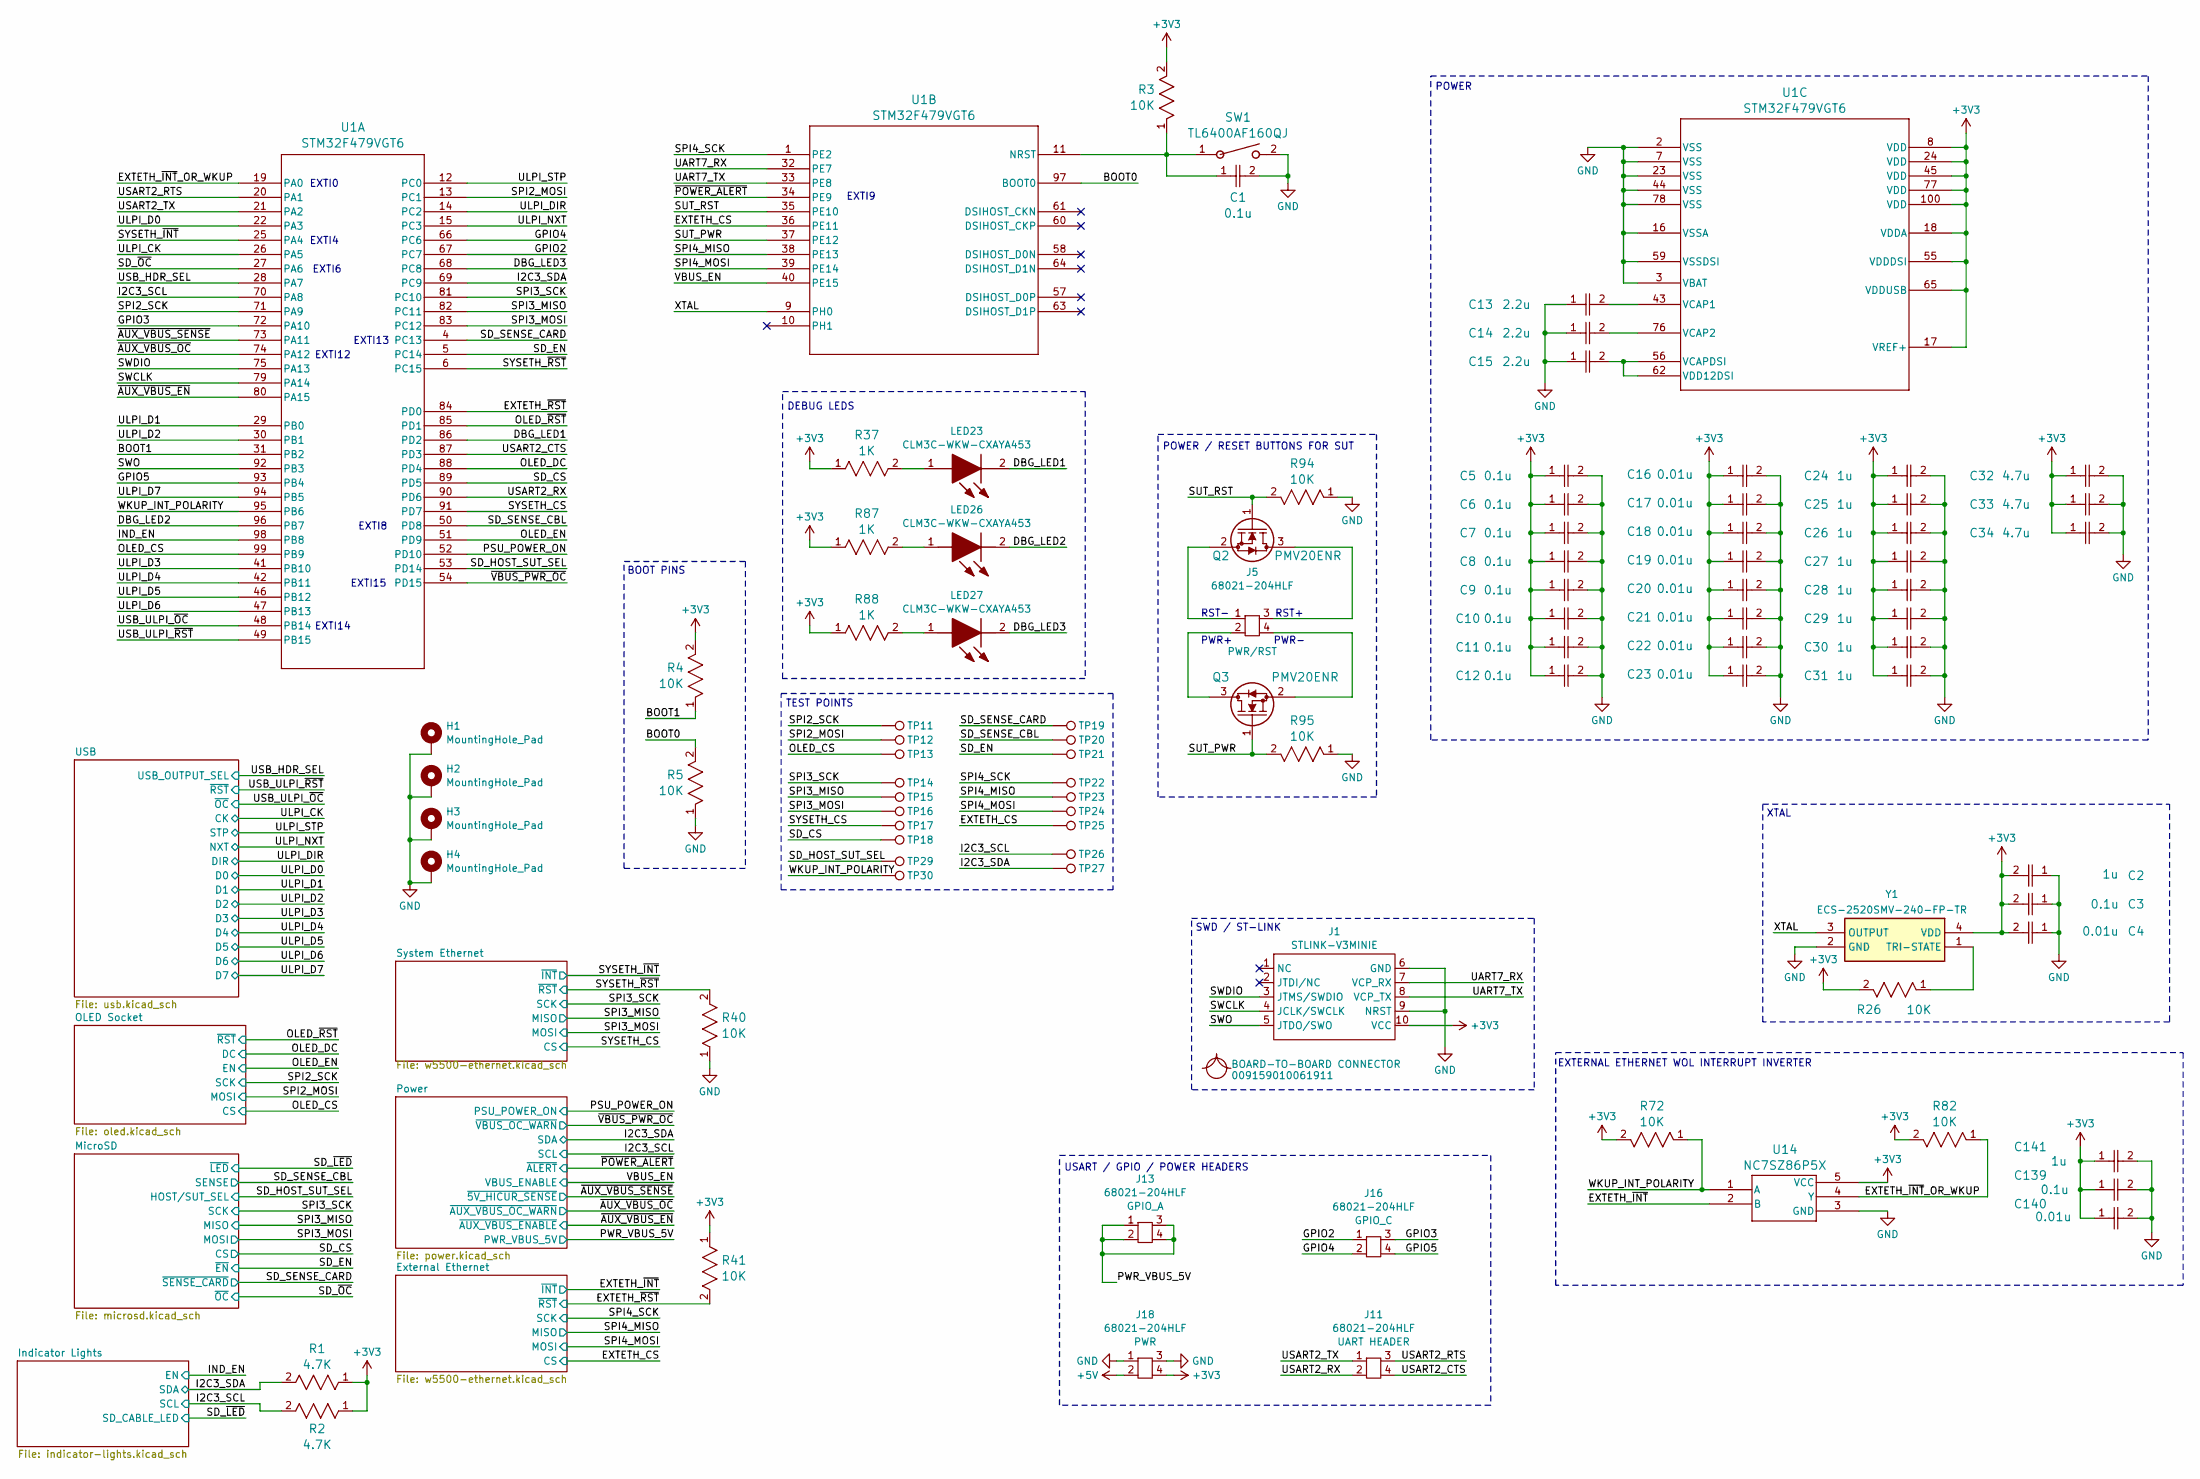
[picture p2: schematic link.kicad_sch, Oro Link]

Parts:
B1: 009159010061911; Manufacturer_Part_Number 009159010061911; Mouser Part Number 581-009159010061911
C1, C3, C5, C6, C7, C8, C9, C10, C11, C12, C139: 0.1u; CAP_MSAS1L-3_TAY; DigiKey ID 587-MSAST1L3YB5104KFNA01CT-ND
C2, C24, C25, C26, C27, C28, C29, C30, C31, C141: 1u; cap_UMK105 CG080CV-F_TAY; DigiKey ID 587-3766-1-ND
C4, C16, C17, C18, C19, C20, C21, C22, C23, C140: 0.01u; CAP_0402_N_WAL; Mouser ID 791-0402B103J160CT
C13, C14, C15: 2.2u; CAP_MK105_V_TAY; Mouser ID 963-EMK105CC6225KV-F
C32, C33, C34: 4.7u; GRM15x; Manufacturer_Part_Number GRM155C61E475ME15J; DigiKey ID 1276-1480-6-ND
H1, H2, H3, H4: MountingHole_Pad; MountingHole_3.2mm_M3_Pad_Via
J1: STLINK-V3MINIE; 009159010061911; Manufacturer_Part_Number STLINK-V3MINIE; Mouser Part Number 511-STLINK-V3MINIE
J5, J11, J13, J16, J18: 68021-204HLF; 2x2 4p 2.54 pitch; Mouser ID Number 649-68021-204HLF
LED23, LED26, LED27: CLM3C-WKW-CXAYA453; CLM3CWKWCXAYA453; Manufacturer_Part_Number CLM3C-WKW-CXAYA453; Mouser Part Number 941-CLM3CWKWCXAYA453
Q2, Q3: PMV20ENR; QNMOS1G2S3D_TO-236AB_SOT23_NEX; DigiKey ID 1727-2301-1-ND
R1, R2: 4.7K; RES_CRCW_0402_VIS-L; Mouser ID 71-CRCW04024K70FKEDH
R3, R4, R5, R26, R40, R41, R72, R82, R94, R95: 10K; STA_RMCF0402_STP; DigiKey ID RMCF0402FT10K0CT-ND
R37, R87, R88: 1K; RES_SG73P_2A_KOA; Mouser URL null
SW1: TL6400AF160QJ; SW_TL6400AF260QJ_EWI; DigiKey ID 141-TL6400AF260QJCT-ND
TP11, TP12: TestPoint_Pad_0.25mm
TP13, TP14, TP15, TP16, TP17, TP18, TP19, TP20, TP21, TP22, TP23, TP24, TP25, TP26, TP27, TP29, TP30: OLED_CS; TestPoint_Pad_0.25mm
U1: STM32F479VGT6; LQFP100_STM; Mouser ID 511-STM32F479VGT6
U14: NC7SZ86P5X; SC-88A-5_1P35X2P2_ONS; Mouser ID 512-NC7SZ86P5X
Y1: ECS-2520SMV-240-FP-TR; ECS2520SMV240FPTR; Manufacturer_Part_Number ECS-2520SMV-240-FP-TR; Mouser Part Number 520-2520SMV-240-FP-T

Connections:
+3V3: C2.2, C3.2, C4.2, C5.1, C6.1, C7.1, C8.1, C9.1, C10.1, C11.1, C12.1, C16.1, C17.1, C18.1, C19.1, C20.1, C21.1, C22.1, C23.1, C24.1, C25.1, C26.1, C27.1, C28.1, C29.1, C30.1, C31.1, C32.1, C33.1, C34.1, C139.1, C140.1, C141.1, J1.10 (VCC), J18.4, R1.1, R2.1, R3.2, R4.2, R26.2, R37.1, R41.1, R72.2, R82.2, R87.1, R88.1, U1.8 (VDD), U1.17 (VREF+), U1.18 (VDDA), U1.24 (VDD), U1.45 (VDD), U1.55 (VDDDSI), U1.65 (VDDUSB), U1.77 (VDD), U1.100 (VDD), U14.5 (VCC), Y1.4 (VDD); also elsewhere on the board
+5V: J18.2; also elsewhere on the board
/BOOT0: R5.2, U1.97 (BOOT0)
/BOOT1: R4.1, U1.31 (PB2)
/DBG_LED1: LED23.2 (K), U1.86 (PD2)
/DBG_LED2: LED26.2 (K), U1.96 (PB7)
/DBG_LED3: LED27.2 (K), U1.68 (PC8)
/EXTETH_CS: TP25.1, U1.36 (PE11); also elsewhere on the board
/EXTETH_~INT: U14.2 (B); also elsewhere on the board
/EXTETH_~INT_OR_WKUP: R82.1, U1.19 (PA0), U14.4 (Y)
/EXTETH_~RST: R41.2, U1.84 (PD0); also elsewhere on the board
/GPIO2: J16.1, U1.67 (PC7)
/GPIO3: J16.3, U1.72 (PA10)
/GPIO4: J16.2, U1.66 (PC6)
/GPIO5: J16.4, U1.93 (PB4)
/I2C3_SCL: R2.2, TP26.1, U1.70 (PA8); also elsewhere on the board
/I2C3_SDA: R1.2, TP27.1, U1.69 (PC9); also elsewhere on the board
/IND_EN: U1.98 (PB8); also elsewhere on the board
/OLED_CS: TP13.1, U1.99 (PB9); also elsewhere on the board
/OLED_DC: U1.88 (PD4); also elsewhere on the board
/OLED_EN: U1.51 (PD9); also elsewhere on the board
/OLED_~RST: U1.85 (PD1); also elsewhere on the board
/PSU_POWER_ON: U1.52 (PD10); also elsewhere on the board
/PWR_VBUS_5V: J13.1, J13.2, J13.3, J13.4; also elsewhere on the board
/SD_CS: TP18.1, U1.89 (PD5); also elsewhere on the board
/SD_EN: TP21.1, U1.5 (PC14); also elsewhere on the board
/SD_HOST_SUT_SEL: TP29.1, U1.53 (PD14); also elsewhere on the board
/SD_SENSE_CARD: TP19.1, U1.4 (PC13); also elsewhere on the board
/SD_SENSE_CBL: TP20.1, U1.50 (PD8); also elsewhere on the board
/SD_~OC: U1.27 (PA6); also elsewhere on the board
/SPI2_MOSI: TP12.1, U1.13 (PC1); also elsewhere on the board
/SPI2_SCK: TP11.1, U1.71 (PA9); also elsewhere on the board
/SPI3_MISO: TP15.1, U1.82 (PC11); also elsewhere on the board
/SPI3_MOSI: TP16.1, U1.83 (PC12); also elsewhere on the board
/SPI3_SCK: TP14.1, U1.81 (PC10); also elsewhere on the board
/SPI4_MISO: TP23.1, U1.38 (PE13); also elsewhere on the board
/SPI4_MOSI: TP24.1, U1.39 (PE14); also elsewhere on the board
/SPI4_SCK: TP22.1, U1.1 (PE2); also elsewhere on the board
/SUT_PWR: Q3.1 (G), R95.2, U1.37 (PE12)
/SUT_RST: Q2.1 (G), R94.2, U1.35 (PE10)
/SWCLK: J1.4 (JCLK/SWCLK), U1.79 (PA14)
/SWDIO: J1.3 (JTMS/SWDIO), U1.75 (PA13)
/SWO: J1.5 (JTDO/SWO), U1.92 (PB3)
/SYSETH_CS: TP17.1, U1.91 (PD7); also elsewhere on the board
/SYSETH_~INT: U1.25 (PA4); also elsewhere on the board
/SYSETH_~RST: R40.2, U1.6 (PC15); also elsewhere on the board
/UART7_RX: J1.7 (VCP_RX), U1.32 (PE7)
/UART7_TX: J1.8 (VCP_TX), U1.33 (PE8)
/ULPI_CK: U1.26 (PA5); also elsewhere on the board
/ULPI_D0: U1.22 (PA3); also elsewhere on the board
/ULPI_D1: U1.29 (PB0); also elsewhere on the board
/ULPI_D2: U1.30 (PB1); also elsewhere on the board
/ULPI_D3: U1.41 (PB10); also elsewhere on the board
/ULPI_D4: U1.42 (PB11); also elsewhere on the board
/ULPI_D5: U1.46 (PB12); also elsewhere on the board
/ULPI_D6: U1.47 (PB13); also elsewhere on the board
/ULPI_D7: U1.94 (PB5); also elsewhere on the board
/ULPI_DIR: U1.14 (PC2); also elsewhere on the board
/ULPI_NXT: U1.15 (PC3); also elsewhere on the board
/ULPI_STP: U1.12 (PC0); also elsewhere on the board
/USART2_CTS: J11.4, U1.87 (PD3)
/USART2_RTS: J11.3, U1.20 (PA1)
/USART2_RX: J11.2, U1.90 (PD6)
/USART2_TX: J11.1, U1.21 (PA2)
/USB_HDR_SEL: U1.28 (PA7); also elsewhere on the board
/USB_ULPI_~OC: U1.48 (PB14); also elsewhere on the board
/USB_ULPI_~RST: U1.49 (PB15); also elsewhere on the board
/VBUS_EN: U1.40 (PE15); also elsewhere on the board
/WKUP_INT_POLARITY: R72.1, TP30.1, U1.95 (PB6), U14.1 (A)
/XTAL: U1.9 (PH0), Y1.3 (OUTPUT)
/~AUX_VBUS_EN: U1.80 (PA15); also elsewhere on the board
/~AUX_VBUS_OC: U1.74 (PA12); also elsewhere on the board
/~AUX_VBUS_SENSE: U1.73 (PA11); also elsewhere on the board
/~POWER_ALERT: U1.34 (PE9); also elsewhere on the board
/~VBUS_PWR_OC: U1.54 (PD15); also elsewhere on the board
GND: C1.2, C2.1, C3.1, C4.1, C5.2, C6.2, C7.2, C8.2, C9.2, C10.2, C11.2, C12.2, C13.1, C14.1, C15.1, C16.2, C17.2, C18.2, C19.2, C20.2, C21.2, C22.2, C23.2, C24.2, C25.2, C26.2, C27.2, C28.2, C29.2, C30.2, C31.2, C32.2, C33.2, C34.2, C139.2, C140.2, C141.2, H1.1, H2.1, H3.1, H4.1, J1.6 (GND), J1.9 (NRST), J18.1, J18.3, R5.1, R40.1, R94.1, R95.1, SW1.2, U1.2 (VSS), U1.3 (VBAT), U1.7 (VSS), U1.16 (VSSA), U1.23 (VSS), U1.44 (VSS), U1.59 (VSSDSI), U1.78 (VSS), U14.3 (GND), Y1.2 (GND); also elsewhere on the board
unnamed: LED23.1 (A), R37.2
unnamed: LED26.1 (A), R87.2
unnamed: LED27.1 (A), R88.2
unnamed: J5.3, Q2.3 (D)
unnamed: J5.1, Q2.2 (S)
unnamed: J5.2, Q3.3 (D)
unnamed: J5.4, Q3.2 (S)
unnamed: C1.1, R3.1, SW1.1, U1.11 (NRST)
unnamed: C13.2, U1.43 (VCAP1)
unnamed: C14.2, U1.76 (VCAP2)
unnamed: C15.2, U1.56 (VCAPDSI), U1.62 (VDD12DSI)
unnamed: R26.1, Y1.1 (TRI-STATE)

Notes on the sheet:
BOOT PINS
PWR-
POWER
EXTI12
EXTI15
EXTERNAL ETHERNET WOL INTERRUPT INVERTER
USART / GPIO / POWER HEADERS
RST-
EXTI8
TEST POINTS
EXTI4
XTAL
EXTI13
DEBUG LEDS
EXTI14
POWER / RESET BUTTONS FOR SUT
PWR+
RST+
EXTI9
EXTI6
SWD / ST-LINK
EXTI0

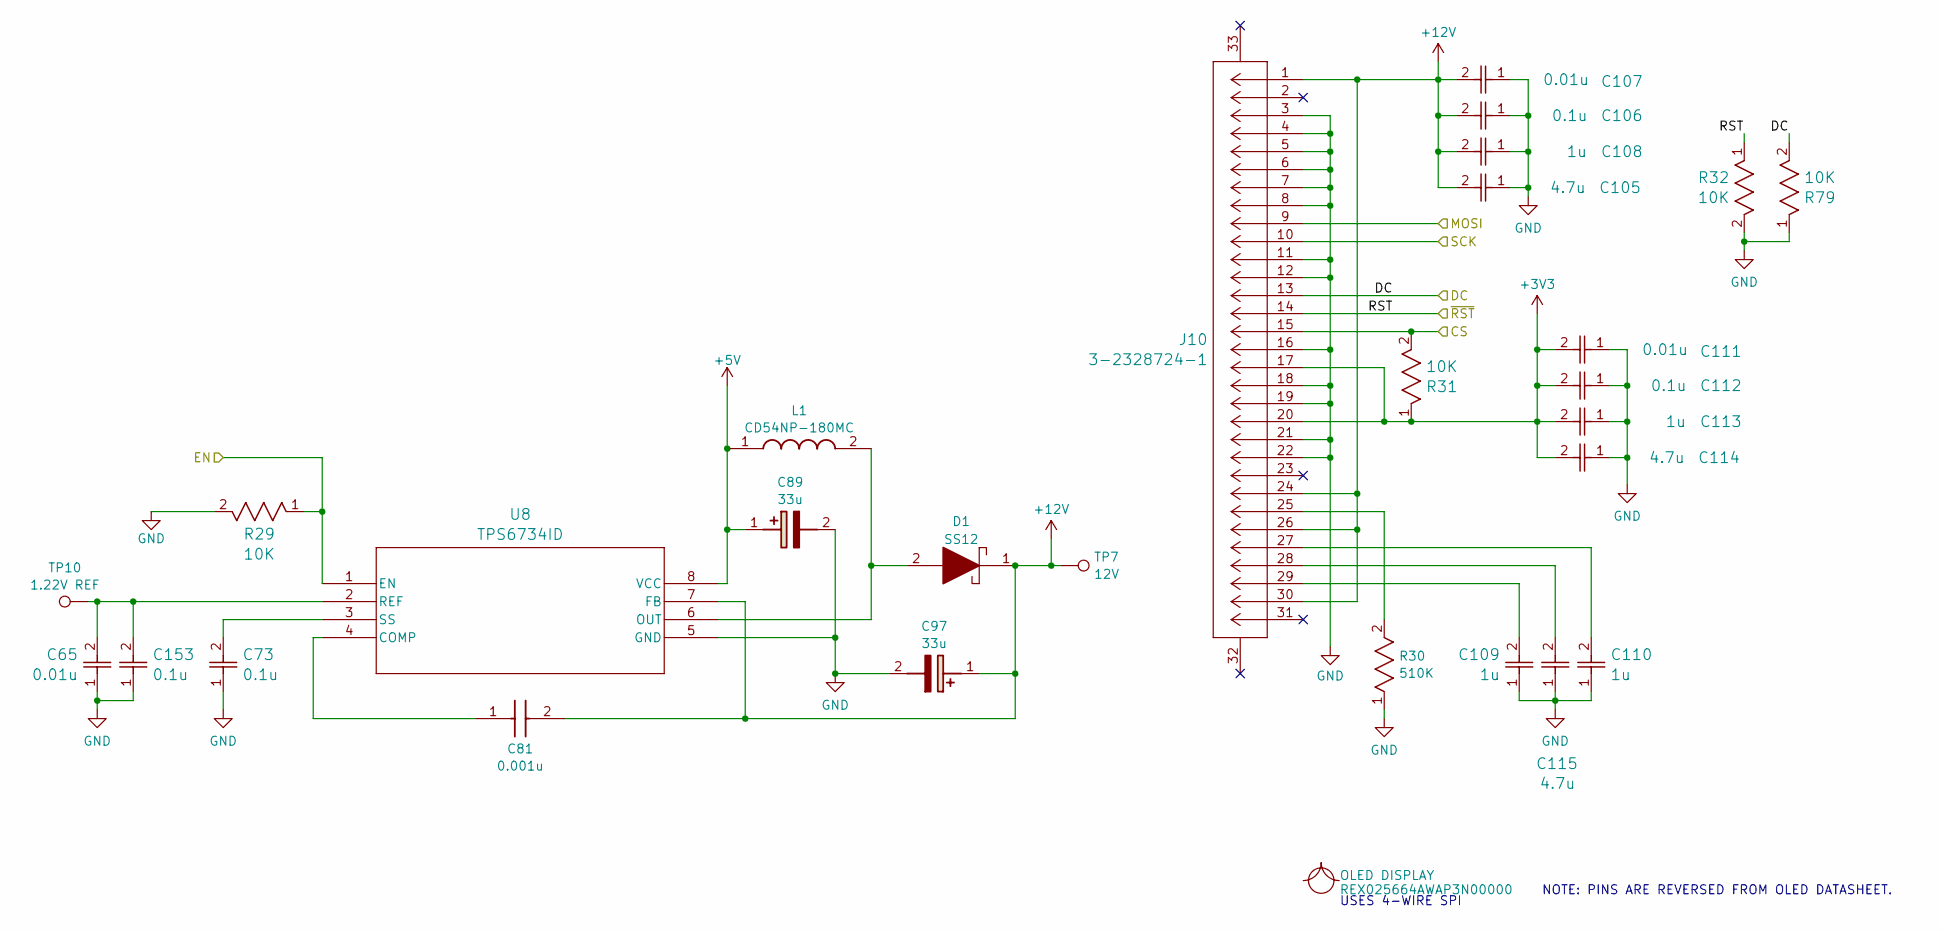
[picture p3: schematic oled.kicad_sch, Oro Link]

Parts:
B3: REX025664AWAP3N00000; Manufacturer_Part_Number REX025664AWAP3N00000; Mouser Part Number 668-REX025664AWAP3N
C65, C107, C111: 0.01u; CAP_0402_N_WAL; Mouser ID 791-0402B103J160CT
C73, C106, C112, C153: 0.1u; CAP_MSAS1L-3_TAY; DigiKey ID 587-MSAST1L3YB5104KFNA01CT-ND
C81: 0.001u; CAPC1608X80N; Manufacturer_Part_Number C1608X5R1H102K080AA; Mouser Part Number 810-C1608X5R1H102K08
C89, C97: 33u; CAPPM7343X310N; Manufacturer_Part_Number 293D336X0020D2TE3; Mouser Part Number 74-293D336X0020D2TE3
C105, C114, C115: 4.7u; GRM15x; Manufacturer_Part_Number GRM155C61E475ME15J; DigiKey ID 1276-1480-6-ND
C108, C109, C110, C113: 1u; cap_UMK105 CG080CV-F_TAY; DigiKey ID 587-3766-1-ND
D1: SS12; DIOM5027X244N; Manufacturer_Part_Number 821-SS12; Mouser Part Number 821-SS12
J10: 3-2328724-1; CONN_3-2328724-1_TEC; Mouser ID 571-3-2328724-1
L1: CD54NP-180MC; CD54NP180MC; Manufacturer_Part_Number CD54NP-180MC; Mouser Part Number 851-CD54NP-180MC
R29, R31, R32, R79: 10K; STA_RMCF0402_STP; DigiKey ID RMCF0402FT10K0CT-ND
R30: 510K; RESC1608X55N; Manufacturer_Part_Number CR0603-JW-514ELF; Mouser Part Number 652-CR0603JW-514ELF
TP7: 12V; TestPoint_Pad_1.0x1.0mm
TP10: 1.22V REF; TestPoint_Pad_1.0x1.0mm
U8: TPS6734ID; D8_TEX; Mouser ID 595-TPS6734ID

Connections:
+3V3: C111.2, C112.2, C113.2, C114.2, J10.17, J10.20, R31.1; also elsewhere on the board
+5V: C89.1 (+), L1.1, U8.8 (VCC); also elsewhere on the board
+12V: C81.2, C97.1 (+), C105.2, C106.2, C107.2, C108.2, D1.1, J10.1, J10.24, J10.26, J10.30, TP7.1, U8.7 (FB)
/OLED_CS: J10.15, R31.2; also elsewhere on the board
/OLED_DC: J10.13, R79.2; also elsewhere on the board
/OLED_EN: R29.1, U8.1 (EN); also elsewhere on the board
/OLED_~RST: J10.14, R32.1; also elsewhere on the board
/SPI2_MOSI: J10.9; also elsewhere on the board
/SPI2_SCK: J10.10; also elsewhere on the board
GND: C65.1, C73.1, C89.2 (-), C97.2 (-), C105.1, C106.1, C107.1, C108.1, C109.1, C110.1, C111.1, C112.1, C113.1, C114.1, C115.1, C153.1, J10.3, J10.4, J10.5, J10.6, J10.7, J10.8, J10.11, J10.12, J10.16, J10.18, J10.19, J10.21, J10.22, R29.2, R30.1, R32.2, R79.1, U8.5 (GND); also elsewhere on the board
unnamed: C109.2, J10.29
unnamed: C110.2, J10.27
unnamed: C115.2, J10.28
unnamed: J10.25, R30.2
unnamed: C81.1, U8.4 (COMP)
unnamed: D1.2, L1.2, U8.6 (OUT)
unnamed: C65.2, C153.2, TP10.1, U8.2 (REF)
unnamed: C73.2, U8.3 (SS)

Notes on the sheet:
NOTE: PINS ARE REVERSED FROM OLED DATASHEET.
USES 4-WIRE SPI

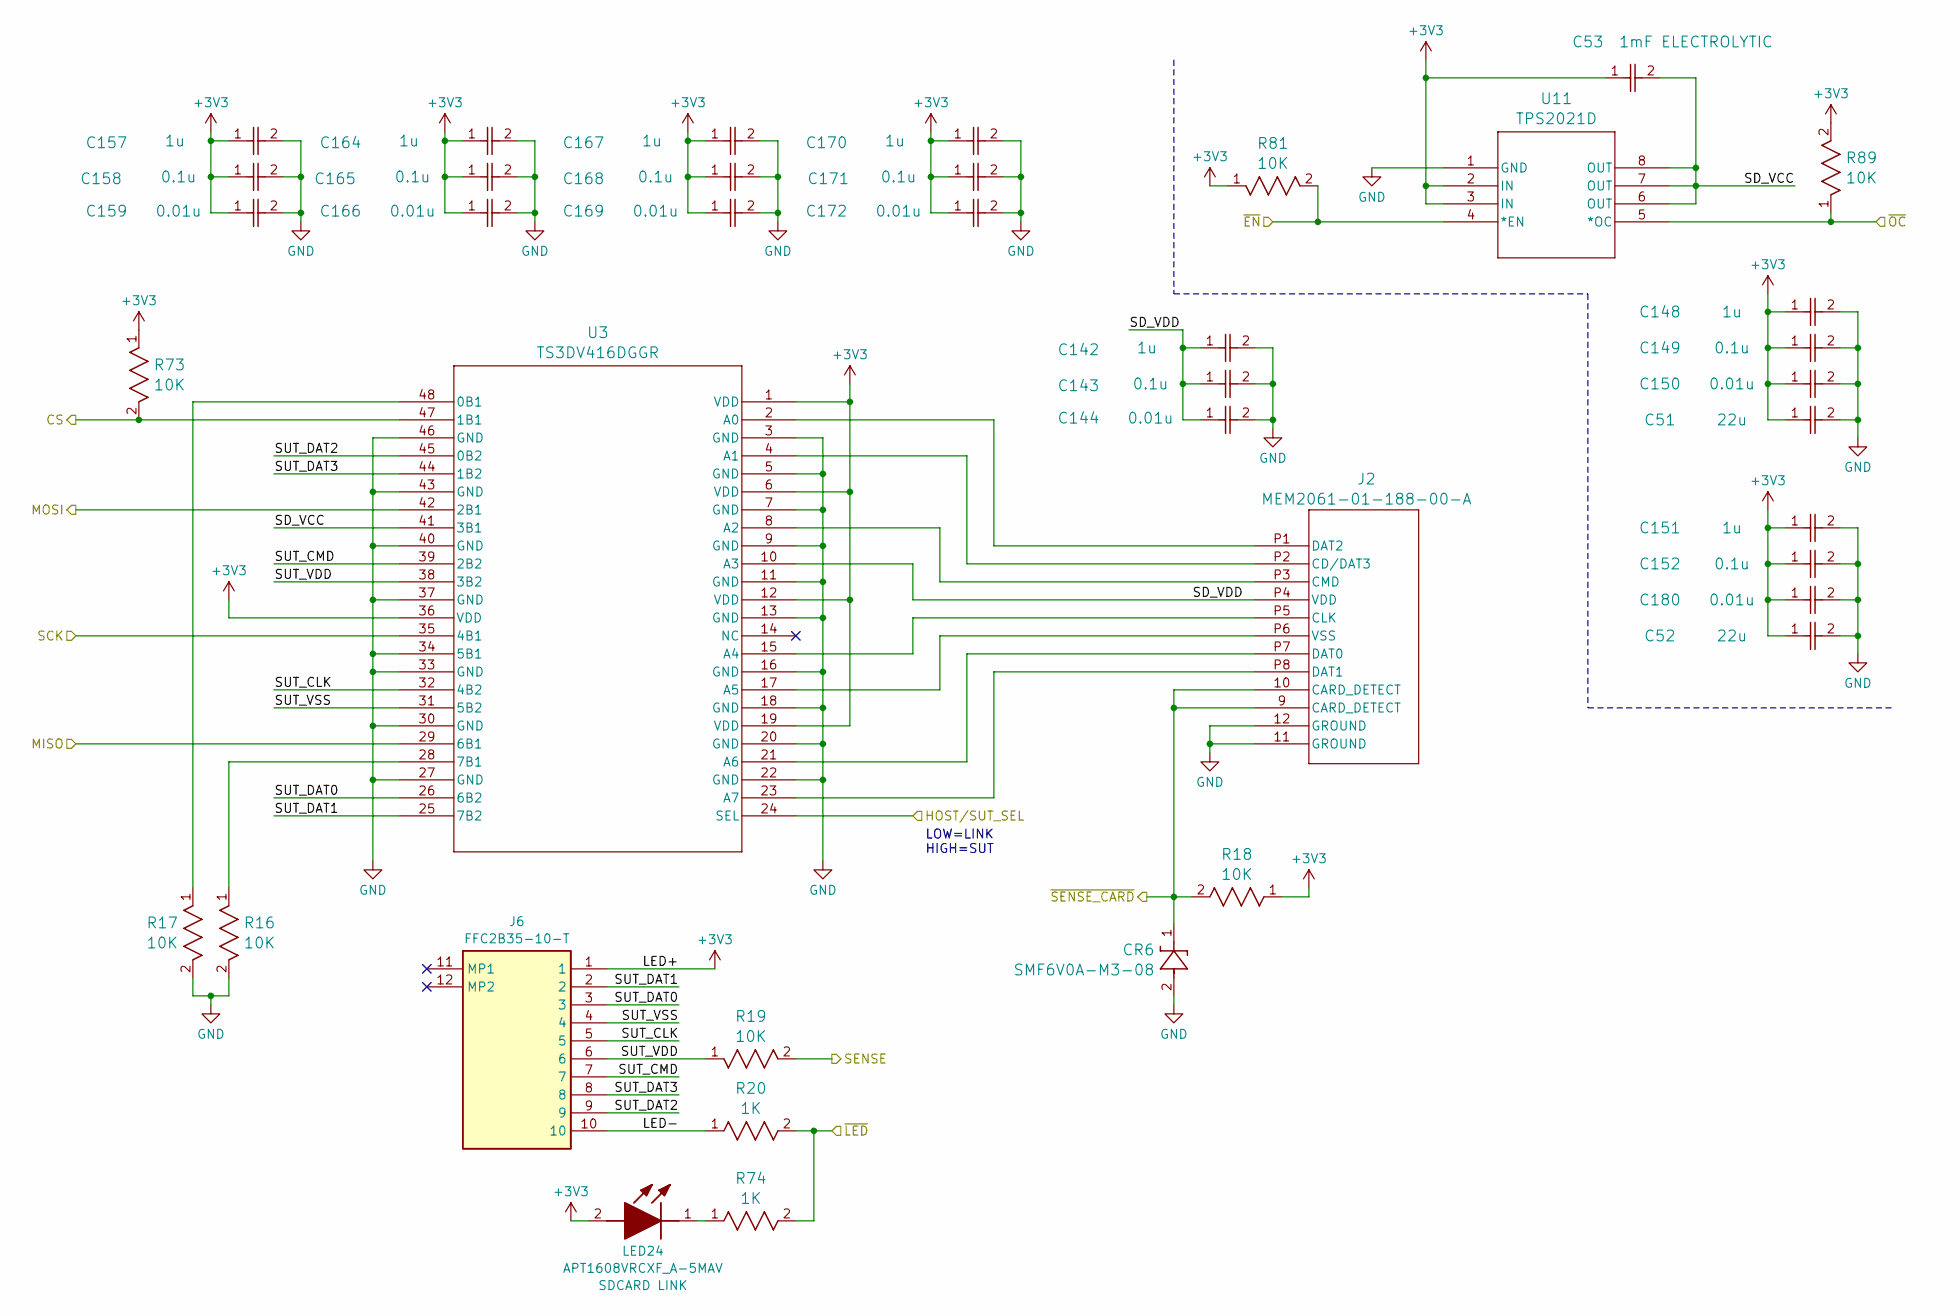
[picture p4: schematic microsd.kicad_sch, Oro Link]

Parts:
C51, C52: 22u; CAP_CM05_K_KAV; Mouser URL null
C53: 1mF ELECTROLYTIC; CAP_99614E3_VIS; Mouser ID 594-MAL215099614E3
C142, C148, C151, C157, C164, C167, C170: 1u; cap_UMK105 CG080CV-F_TAY; DigiKey ID 587-3766-1-ND
C143, C149, C152, C158, C165, C168, C171: 0.1u; CAP_MSAS1L-3_TAY; DigiKey ID 587-MSAST1L3YB5104KFNA01CT-ND
C144, C150, C159, C166, C169, C172, C180: 0.01u; CAP_0402_N_WAL; Mouser ID 791-0402B103J160CT
CR6: SMF6V0A-M3-08; ZDO_SMF_DO-219AB_VIS; Mouser ID 78-SMF6V0A-M3-08
J2: MEM2061-01-188-00-A; MEM2061-01-188-00-A_GCT; Mouser ID 640-MEM20610118800A
J6: FFC2B35-10-T; FFC2B3510T; Manufacturer_Part_Number FFC2B35-10-T; Mouser Part Number 640-FFC2B35-10-T
LED24: APT1608VRCXF_A-5MAV; APT1608VRCXFA5MAV; Manufacturer_Part_Number APT1608VRCXF/A-5MAV; Mouser Part Number 604-APT1608VRCXF5MAV
R16, R17, R18, R19, R73, R81, R89: 10K; STA_RMCF0402_STP; DigiKey ID RMCF0402FT10K0CT-ND
R20, R74: 1K; RES_SG73P_2A_KOA; Mouser URL null
U3: TS3DV416DGGR; DGG48; DigiKey ID 296-21175-1-ND
U11: TPS2021D; D8; Mouser ID 595-TPS2021D

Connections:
+3V3: C51.1, C52.1, C53.1, C148.1, C149.1, C150.1, C151.1, C152.1, C157.1, C158.1, C159.1, C164.1, C165.1, C166.1, C167.1, C168.1, C169.1, C170.1, C171.1, C172.1, C180.1, J6.1, LED24.2 (A), R18.1, R73.1, R81.1, R89.2, U3.1 (VDD), U3.6 (VDD), U3.12 (VDD), U3.19 (VDD), U3.36 (VDD), U11.2 (IN), U11.3 (IN); also elsewhere on the board
/MicroSD/LED-: J6.10, R20.1
/MicroSD/SD_VCC: C53.2, U3.41 (3B1), U11.6 (OUT), U11.7 (OUT), U11.8 (OUT)
/MicroSD/SD_VDD: C142.1, C143.1, C144.1, J2.P4 (VDD), U3.10 (A3)
/MicroSD/SUT_CLK: J6.5, U3.32 (4B2)
/MicroSD/SUT_CMD: J6.7, U3.39 (2B2)
/MicroSD/SUT_DAT0: J6.3, U3.26 (6B2)
/MicroSD/SUT_DAT1: J6.2, U3.25 (7B2)
/MicroSD/SUT_DAT2: J6.9, U3.45 (0B2)
/MicroSD/SUT_DAT3: J6.8, U3.44 (1B2)
/MicroSD/SUT_VDD: J6.6, R19.1, U3.38 (3B2)
/MicroSD/SUT_VSS: J6.4, U3.31 (5B2)
/SD_CS: R73.2, U3.47 (1B1); also elsewhere on the board
/SD_EN: R81.2, U11.4 (*EN); also elsewhere on the board
/SD_HOST_SUT_SEL: U3.24 (SEL); also elsewhere on the board
/SD_SENSE_CARD: CR6.1, J2.9 (CARD_DETECT), J2.10 (CARD_DETECT), R18.2; also elsewhere on the board
/SD_SENSE_CBL: R19.2; also elsewhere on the board
/SD_~LED: R20.2, R74.2; also elsewhere on the board
/SD_~OC: R89.1, U11.5 (*OC); also elsewhere on the board
/SPI3_MISO: U3.29 (6B1); also elsewhere on the board
/SPI3_MOSI: U3.42 (2B1); also elsewhere on the board
/SPI3_SCK: U3.35 (4B1); also elsewhere on the board
GND: C51.2, C52.2, C142.2, C143.2, C144.2, C148.2, C149.2, C150.2, C151.2, C152.2, C157.2, C158.2, C159.2, C164.2, C165.2, C166.2, C167.2, C168.2, C169.2, C170.2, C171.2, C172.2, C180.2, CR6.2, J2.11 (GROUND), J2.12 (GROUND), R16.2, R17.2, U3.3 (GND), U3.5 (GND), U3.7 (GND), U3.9 (GND), U3.11 (GND), U3.13 (GND), U3.16 (GND), U3.18 (GND), U3.20 (GND), U3.22 (GND), U3.27 (GND), U3.30 (GND), U3.33 (GND), U3.34 (5B1), U3.37 (GND), U3.40 (GND), U3.43 (GND), U3.46 (GND), U11.1 (GND); also elsewhere on the board
unnamed: J2.P2 (CD/DAT3), U3.4 (A1)
unnamed: J2.P5 (CLK), U3.15 (A4)
unnamed: J2.P3 (CMD), U3.8 (A2)
unnamed: J2.P7 (DAT0), U3.21 (A6)
unnamed: J2.P8 (DAT1), U3.23 (A7)
unnamed: J2.P1 (DAT2), U3.2 (A0)
unnamed: J2.P6 (VSS), U3.17 (A5)
unnamed: LED24.1 (K), R74.1
unnamed: R17.1, U3.48 (0B1)
unnamed: R16.1, U3.28 (7B1)

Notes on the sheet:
LOW=LINK HIGH=SUT

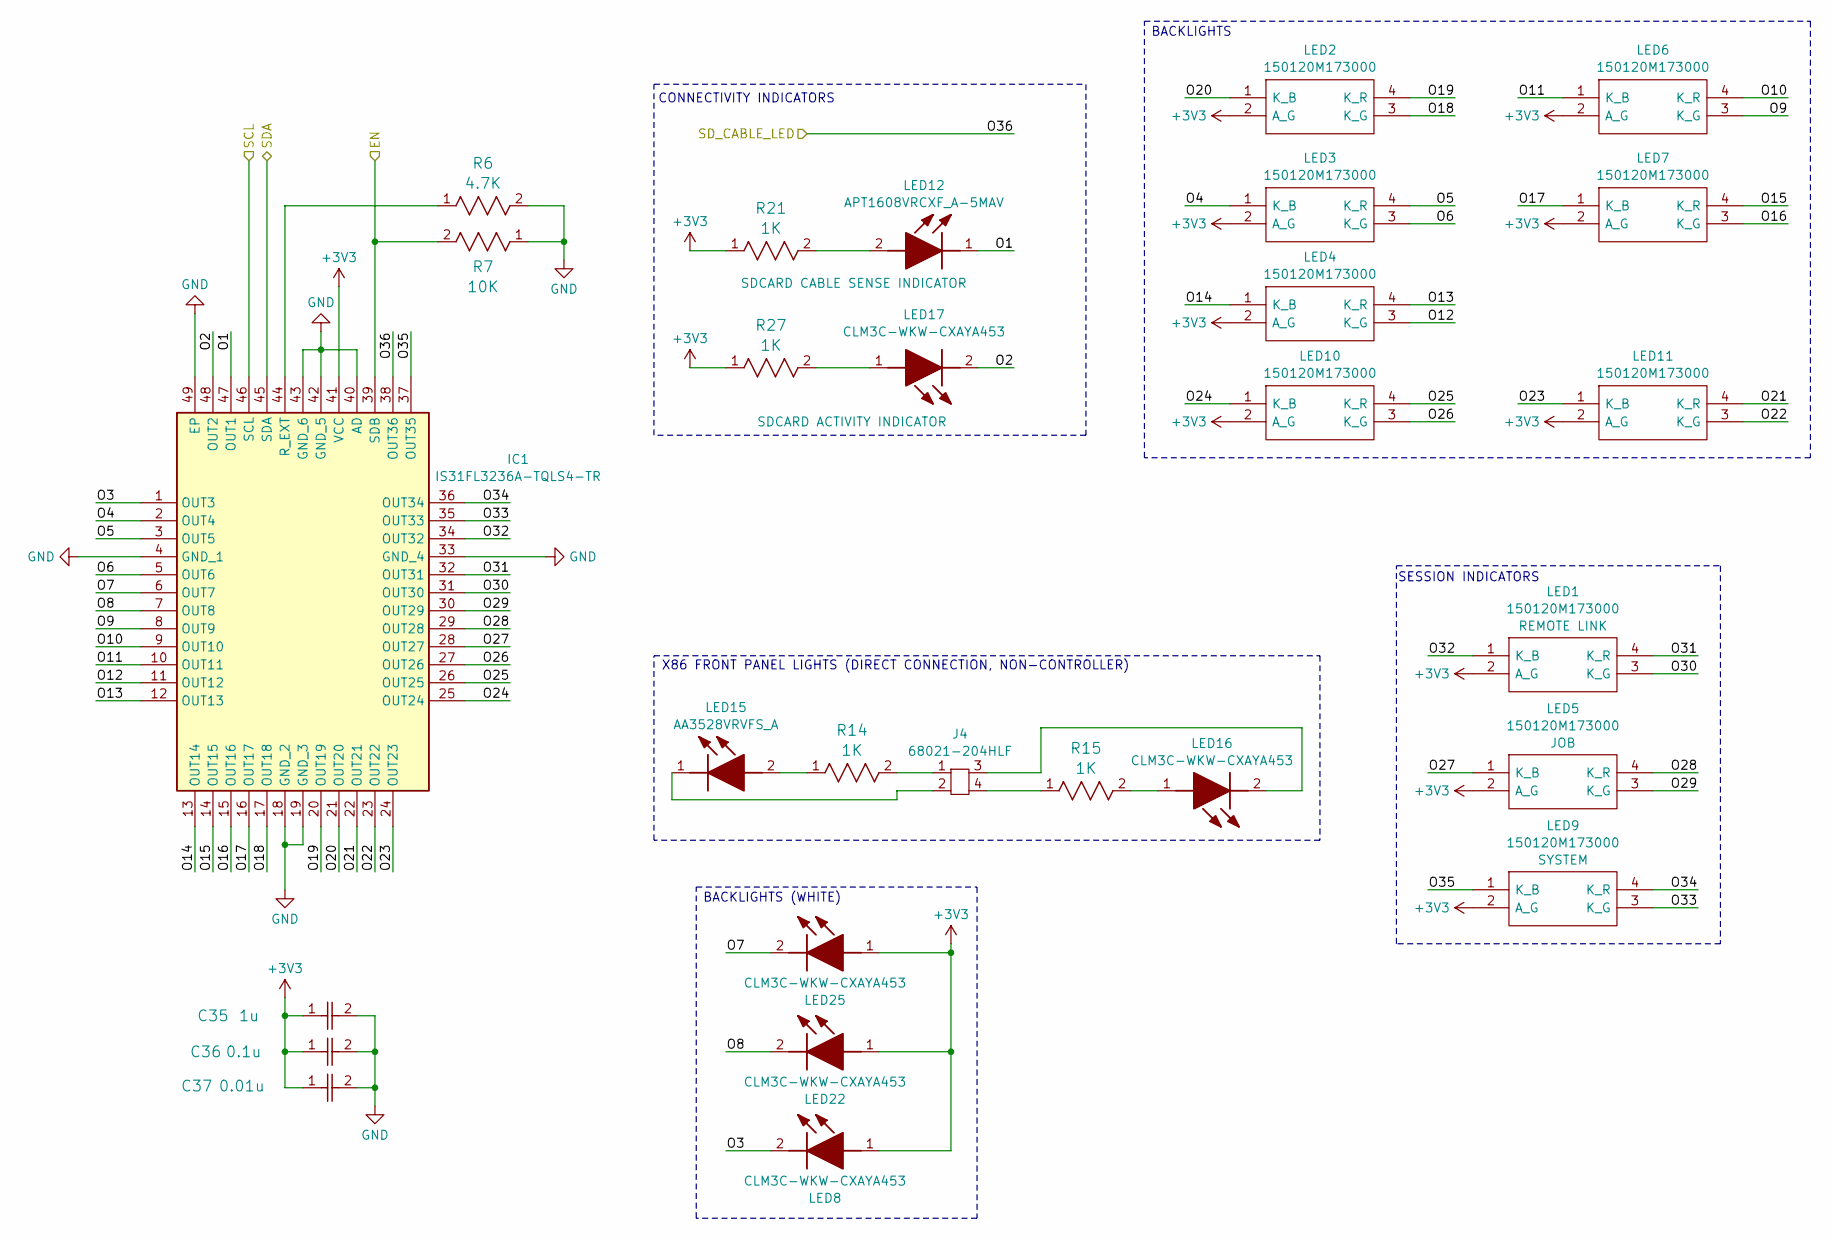
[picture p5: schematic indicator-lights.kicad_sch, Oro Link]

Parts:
C35: 1u; cap_UMK105 CG080CV-F_TAY; DigiKey ID 587-3766-1-ND
C36: 0.1u; CAP_MSAS1L-3_TAY; DigiKey ID 587-MSAST1L3YB5104KFNA01CT-ND
C37: 0.01u; CAP_0402_N_WAL; Mouser ID 791-0402B103J160CT
IC1: IS31FL3236A-TQLS4-TR; QFP50P900X900X120-49N; Manufacturer_Part_Number IS31FL3236A-TQLS4-TR; Mouser Part Number 870-I31FL3236ATQLS4T
J4: 68021-204HLF; 2x2 4p 2.54 pitch; Mouser ID Number 649-68021-204HLF
LED1, LED2, LED3, LED4, LED5, LED6, LED7, LED9, LED10, LED11: 150120M173000; Manufacturer_Part_Number 150120M173000; Mouser Part Number 710-150120M173000
LED8, LED16, LED17, LED22, LED25: CLM3C-WKW-CXAYA453; CLM3CWKWCXAYA453; Manufacturer_Part_Number CLM3C-WKW-CXAYA453; Mouser Part Number 941-CLM3CWKWCXAYA453
LED12: APT1608VRCXF_A-5MAV; APT1608VRCXFA5MAV; Manufacturer_Part_Number APT1608VRCXF/A-5MAV; Mouser Part Number 604-APT1608VRCXF5MAV
LED15: AA3528VRVFS_A; AA3528VRVFSA; Manufacturer_Part_Number AA3528VRVFS/A; Mouser Part Number 604-AA3528VRVFS/A
R6: 4.7K; RES_CRCW_0402_VIS-L; Mouser ID 71-CRCW04024K70FKEDH
R7: 10K; STA_RMCF0402_STP; DigiKey ID RMCF0402FT10K0CT-ND
R14, R15, R21, R27: 1K; RES_SG73P_2A_KOA; Mouser URL null

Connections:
+3V3: C35.1, C36.1, C37.1, IC1.41 (VCC), LED1.2 (A_G), LED2.2 (A_G), LED3.2 (A_G), LED4.2 (A_G), LED5.2 (A_G), LED6.2 (A_G), LED7.2 (A_G), LED8.1 (A), LED9.2 (A_G), LED10.2 (A_G), LED11.2 (A_G), LED22.1 (A), LED25.1 (A), R21.1, R27.1; also elsewhere on the board
/I2C3_SCL: IC1.46 (SCL); also elsewhere on the board
/I2C3_SDA: IC1.45 (SDA); also elsewhere on the board
/IND_EN: IC1.39 (SDB), R7.2; also elsewhere on the board
/Indicator Lights/O1: IC1.47 (OUT1), LED12.1 (K)
/Indicator Lights/O3: IC1.1 (OUT3), LED8.2 (K)
/Indicator Lights/O4: IC1.2 (OUT4), LED3.1 (K_B)
/Indicator Lights/O5: IC1.3 (OUT5), LED3.4 (K_R)
/Indicator Lights/O6: IC1.5 (OUT6), LED3.3 (K_G)
/Indicator Lights/O7: IC1.6 (OUT7), LED25.2 (K)
/Indicator Lights/O8: IC1.7 (OUT8), LED22.2 (K)
/Indicator Lights/O9: IC1.8 (OUT9), LED6.3 (K_G)
/Indicator Lights/O10: IC1.9 (OUT10), LED6.4 (K_R)
/Indicator Lights/O11: IC1.10 (OUT11), LED6.1 (K_B)
/Indicator Lights/O12: IC1.11 (OUT12), LED4.3 (K_G)
/Indicator Lights/O13: IC1.12 (OUT13), LED4.4 (K_R)
/Indicator Lights/O14: IC1.13 (OUT14), LED4.1 (K_B)
/Indicator Lights/O15: IC1.14 (OUT15), LED7.4 (K_R)
/Indicator Lights/O16: IC1.15 (OUT16), LED7.3 (K_G)
/Indicator Lights/O17: IC1.16 (OUT17), LED7.1 (K_B)
/Indicator Lights/O18: IC1.17 (OUT18), LED2.3 (K_G)
/Indicator Lights/O19: IC1.20 (OUT19), LED2.4 (K_R)
/Indicator Lights/O20: IC1.21 (OUT20), LED2.1 (K_B)
/Indicator Lights/O21: IC1.22 (OUT21), LED11.4 (K_R)
/Indicator Lights/O22: IC1.23 (OUT22), LED11.3 (K_G)
/Indicator Lights/O23: IC1.24 (OUT23), LED11.1 (K_B)
/Indicator Lights/O24: IC1.25 (OUT24), LED10.1 (K_B)
/Indicator Lights/O25: IC1.26 (OUT25), LED10.4 (K_R)
/Indicator Lights/O26: IC1.27 (OUT26), LED10.3 (K_G)
/Indicator Lights/O27: IC1.28 (OUT27), LED5.1 (K_B)
/Indicator Lights/O28: IC1.29 (OUT28), LED5.4 (K_R)
/Indicator Lights/O29: IC1.30 (OUT29), LED5.3 (K_G)
/Indicator Lights/O30: IC1.31 (OUT30), LED1.3 (K_G)
/Indicator Lights/O31: IC1.32 (OUT31), LED1.4 (K_R)
/Indicator Lights/O32: IC1.34 (OUT32), LED1.1 (K_B)
/Indicator Lights/O33: IC1.35 (OUT33), LED9.3 (K_G)
/Indicator Lights/O34: IC1.36 (OUT34), LED9.4 (K_R)
/Indicator Lights/O35: IC1.37 (OUT35), LED9.1 (K_B)
/SD_~LED: IC1.38 (OUT36); also elsewhere on the board
GND: C35.2, C36.2, C37.2, IC1.4 (GND_1), IC1.18 (GND_2), IC1.19 (GND_3), IC1.33 (GND_4), IC1.40 (AD), IC1.42 (GND_5), IC1.43 (GND_6), IC1.49 (EP), R6.2, R7.1; also elsewhere on the board
unnamed: IC1.44 (R_EXT), R6.1
unnamed: J4.1, R14.2
unnamed: J4.4, R15.1
unnamed: LED12.2 (A), R21.2
unnamed: LED15.2 (A), R14.1
unnamed: J4.2, LED15.1 (K)
unnamed: LED16.1 (A), R15.2
unnamed: J4.3, LED16.2 (K)

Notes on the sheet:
X86 FRONT PANEL LIGHTS (DIRECT CONNECTION, NON-CONTROLLER)
BACKLIGHTS
BACKLIGHTS (WHITE)
SESSION INDICATORS
CONNECTIVITY INDICATORS

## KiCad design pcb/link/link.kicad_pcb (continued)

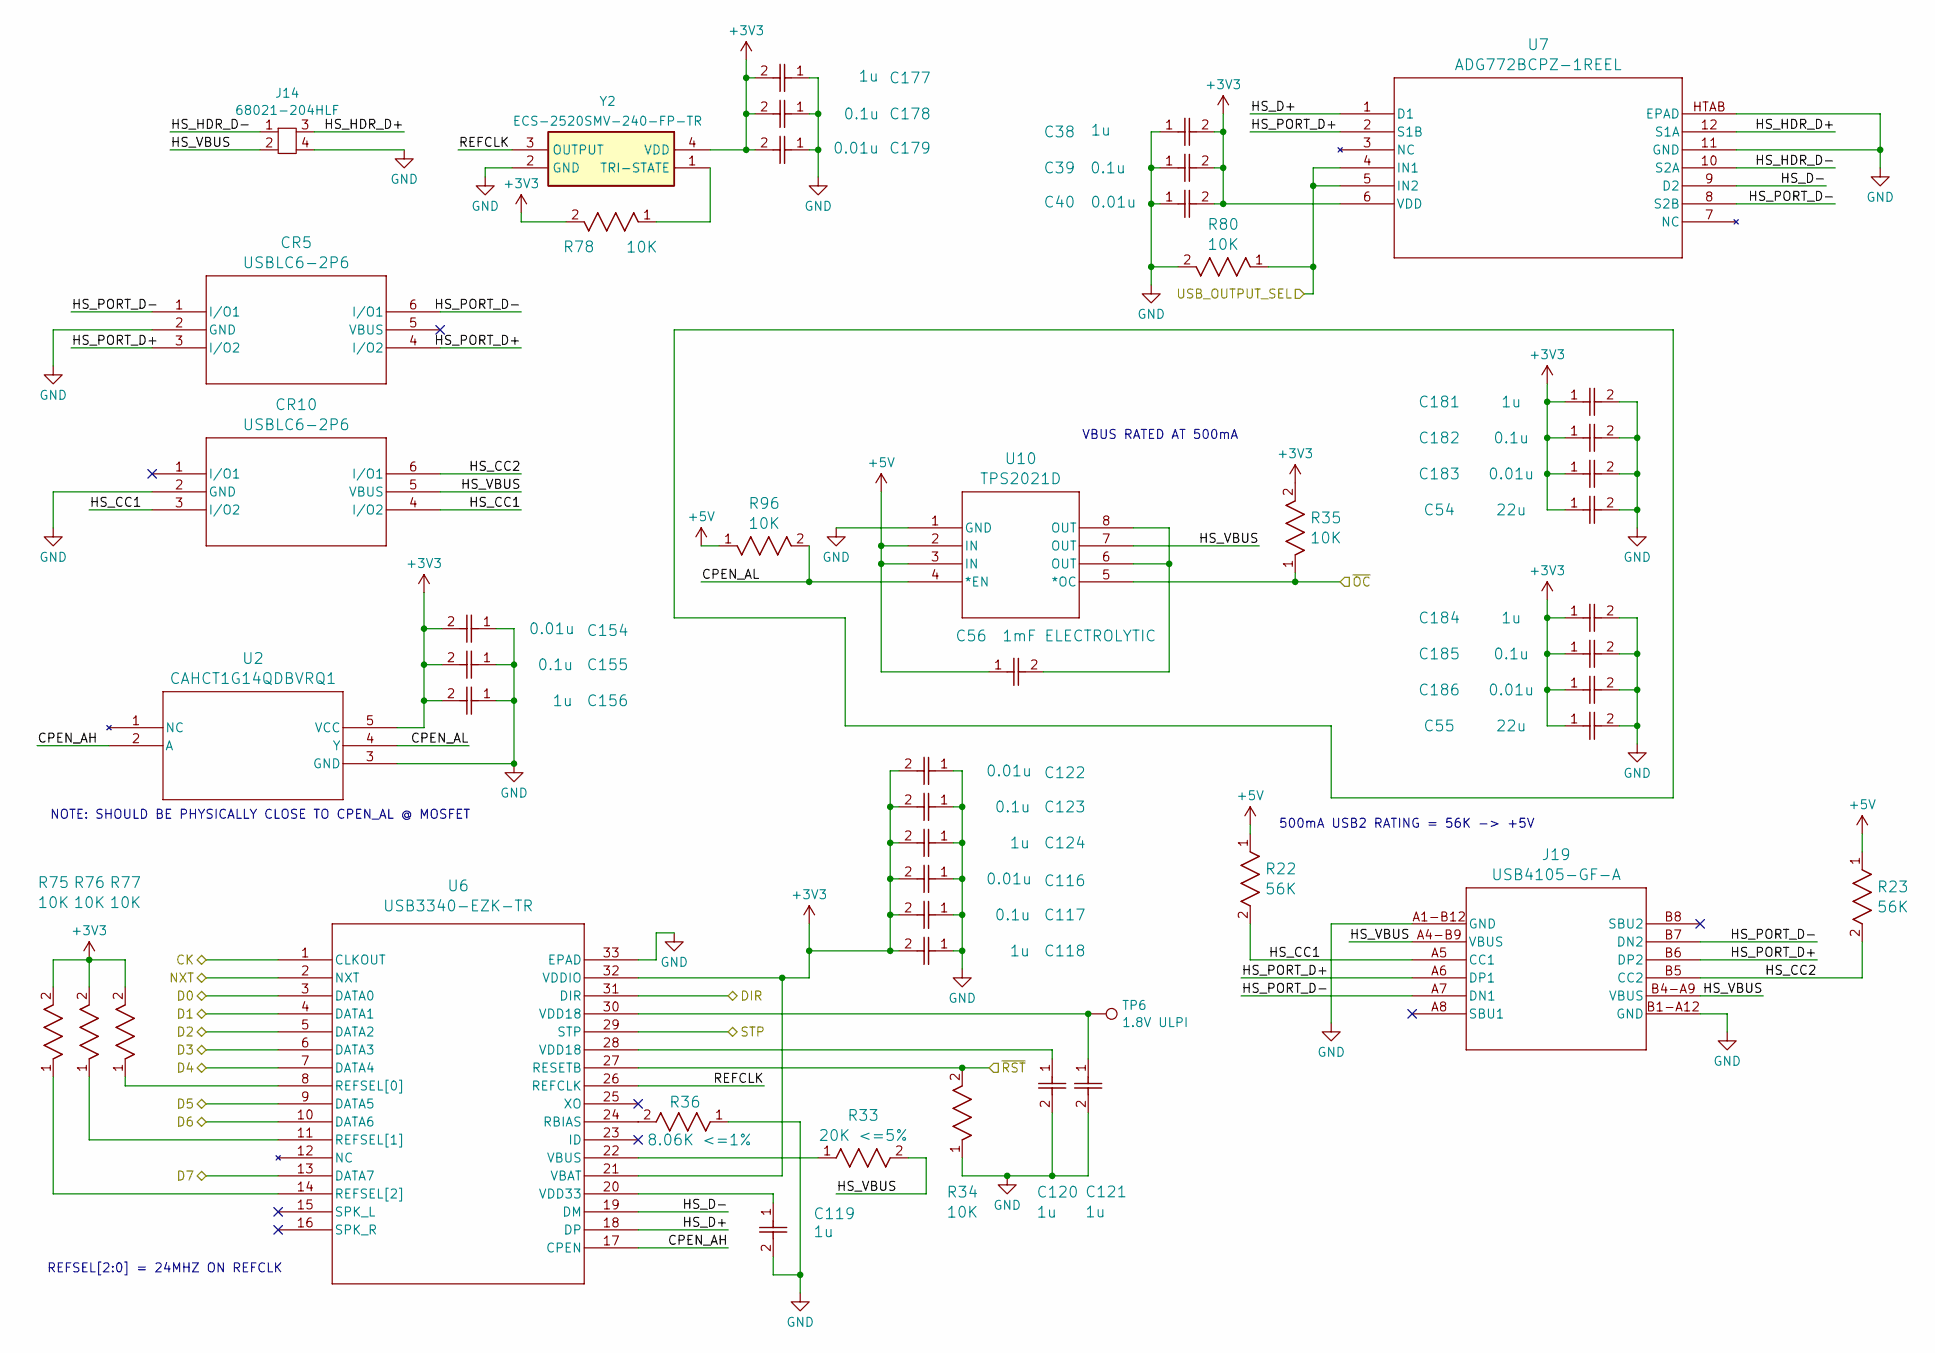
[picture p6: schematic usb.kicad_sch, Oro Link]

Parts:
C38, C118, C119, C120, C121, C124, C156, C177, C181, C184: 1u; cap_UMK105 CG080CV-F_TAY; DigiKey ID 587-3766-1-ND
C39, C117, C123, C155, C178, C182, C185: 0.1u; CAP_MSAS1L-3_TAY; DigiKey ID 587-MSAST1L3YB5104KFNA01CT-ND
C40, C116, C122, C154, C179, C183, C186: 0.01u; CAP_0402_N_WAL; Mouser ID 791-0402B103J160CT
C54, C55: 22u; CAP_CM05_K_KAV; Mouser URL null
C56: 1mF ELECTROLYTIC; CAP_99614E3_VIS; Mouser ID 594-MAL215099614E3
CR5, CR10: USBLC6-2P6; SOT-666_STM; Mouser ID 511-USBLC6-2P6
J14: 68021-204HLF; 2x2 4p 2.54 pitch; Mouser ID Number 649-68021-204HLF
J19: USB4105-GF-A; USB4105_GCT; DigiKey ID 2073-USB4105-GF-ACT-ND
R22, R23: 56K; RC0603N_PAN; DigiKey ID P56KGCT-ND
R33: 20K <=5%; MCS0402_VIS; Mouser ID 594-MCS04020C2002FE0
R34, R35, R75, R76, R77, R78, R80, R96: 10K; STA_RMCF0402_STP; DigiKey ID RMCF0402FT10K0CT-ND
R36: 8.06K <=1%; RES0402_CPF_TYCO_TYC; Mouser ID 667-ERA-2AEB8061X
TP6: 1.8V ULPI; TestPoint_Pad_1.0x1.0mm
U2: CAHCT1G14QDBVRQ1; SOT-23-5_DBV_TEX; DigiKey ID 296-CAHCT1G14QDBVRQ1CT-ND
U6: USB3340-EZK-TR; QFN32_5X5MC_MCH; Mouser ID 886-USB3340-EZK-TR
U7: ADG772BCPZ-1REEL; CP_12_1_ADI; DigiKey ID 505-ADG772BCPZ-1REELCT-ND
U10: TPS2021D; D8; Mouser ID 595-TPS2021D
Y2: ECS-2520SMV-240-FP-TR; ECS2520SMV240FPTR; Manufacturer_Part_Number ECS-2520SMV-240-FP-TR; Mouser Part Number 520-2520SMV-240-FP-T

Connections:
+3V3: C38.2, C39.2, C40.2, C54.1, C55.1, C116.2, C117.2, C118.2, C122.2, C123.2, C124.2, C154.2, C155.2, C156.2, C177.2, C178.2, C179.2, C181.1, C182.1, C183.1, C184.1, C185.1, C186.1, R35.2, R75.2, R76.2, R77.2, R78.2, U2.5 (VCC), U6.21 (VBAT), U6.32 (VDDIO), U7.6 (VDD), Y2.4 (VDD); also elsewhere on the board
+5V: C56.1, R22.1, R23.1, R96.1, U10.2 (IN), U10.3 (IN); also elsewhere on the board
/ULPI_CK: U6.1 (CLKOUT); also elsewhere on the board
/ULPI_D0: U6.3 (DATA0); also elsewhere on the board
/ULPI_D1: U6.4 (DATA1); also elsewhere on the board
/ULPI_D2: U6.5 (DATA2); also elsewhere on the board
/ULPI_D3: U6.6 (DATA3); also elsewhere on the board
/ULPI_D4: U6.7 (DATA4); also elsewhere on the board
/ULPI_D5: U6.9 (DATA5); also elsewhere on the board
/ULPI_D6: U6.10 (DATA6); also elsewhere on the board
/ULPI_D7: U6.13 (DATA7); also elsewhere on the board
/ULPI_DIR: U6.31 (DIR); also elsewhere on the board
/ULPI_NXT: U6.2 (NXT); also elsewhere on the board
/ULPI_STP: U6.29 (STP); also elsewhere on the board
/USB/CPEN_AH: U2.2 (A), U6.17 (CPEN)
/USB/CPEN_AL: R96.2, U2.4 (Y), U10.4 (*EN)
/USB/HS_CC1: CR10.3 (I/O2), CR10.4 (I/O2), J19.A5 (CC1), R22.2
/USB/HS_CC2: CR10.6 (I/O1), J19.B5 (CC2), R23.2
/USB/HS_D+: U6.18 (DP), U7.1 (D1)
/USB/HS_D-: U6.19 (DM), U7.9 (D2)
/USB/HS_HDR_D+: J14.3, U7.12 (S1A)
/USB/HS_HDR_D-: J14.1, U7.10 (S2A)
/USB/HS_PORT_D+: CR5.3 (I/O2), CR5.4 (I/O2), J19.A6 (DP1), J19.B6 (DP2), U7.2 (S1B)
/USB/HS_PORT_D-: CR5.1 (I/O1), CR5.6 (I/O1), J19.A7 (DN1), J19.B7 (DN2), U7.8 (S2B)
/USB/REFCLK: U6.26 (REFCLK), Y2.3 (OUTPUT)
/USB_HDR_SEL: R80.1, U7.4 (IN1), U7.5 (IN2); also elsewhere on the board
/USB_ULPI_~OC: R35.1, U10.5 (*OC); also elsewhere on the board
/USB_ULPI_~RST: R34.2, U6.27 (RESETB); also elsewhere on the board
GND: C38.1, C39.1, C40.1, C54.2, C55.2, C116.1, C117.1, C118.1, C119.2, C120.2, C121.2, C122.1, C123.1, C124.1, C154.1, C155.1, C156.1, C177.1, C178.1, C179.1, C181.2, C182.2, C183.2, C184.2, C185.2, C186.2, CR5.2 (GND), CR10.2 (GND), J14.4, J19.A1-B12 (GND), J19.B1-A12 (GND), R34.1, R36.1, R80.2, U2.3 (GND), U6.33 (EPAD), U7.11 (GND), U7.HTAB (EPAD), U10.1 (GND), Y2.2 (GND); also elsewhere on the board
unnamed: C120.1, U6.28 (VDD18)
unnamed: C121.1, TP6.1, U6.30 (VDD18)
unnamed: R36.2, U6.24 (RBIAS)
unnamed: R77.1, U6.8 (REFSEL[0])
unnamed: R76.1, U6.11 (REFSEL[1])
unnamed: R75.1, U6.14 (REFSEL[2])
unnamed: R33.1, U6.22 (VBUS)
unnamed: C119.1, U6.20 (VDD33)
unnamed: R78.1, Y2.1 (TRI-STATE)

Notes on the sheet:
500mA USB2 RATING = 56K -> +5V
NOTE: SHOULD BE PHYSICALLY CLOSE TO CPEN_AL @ MOSFET
REFSEL[2:0] = 24MHZ ON REFCLK
VBUS RATED AT 500mA

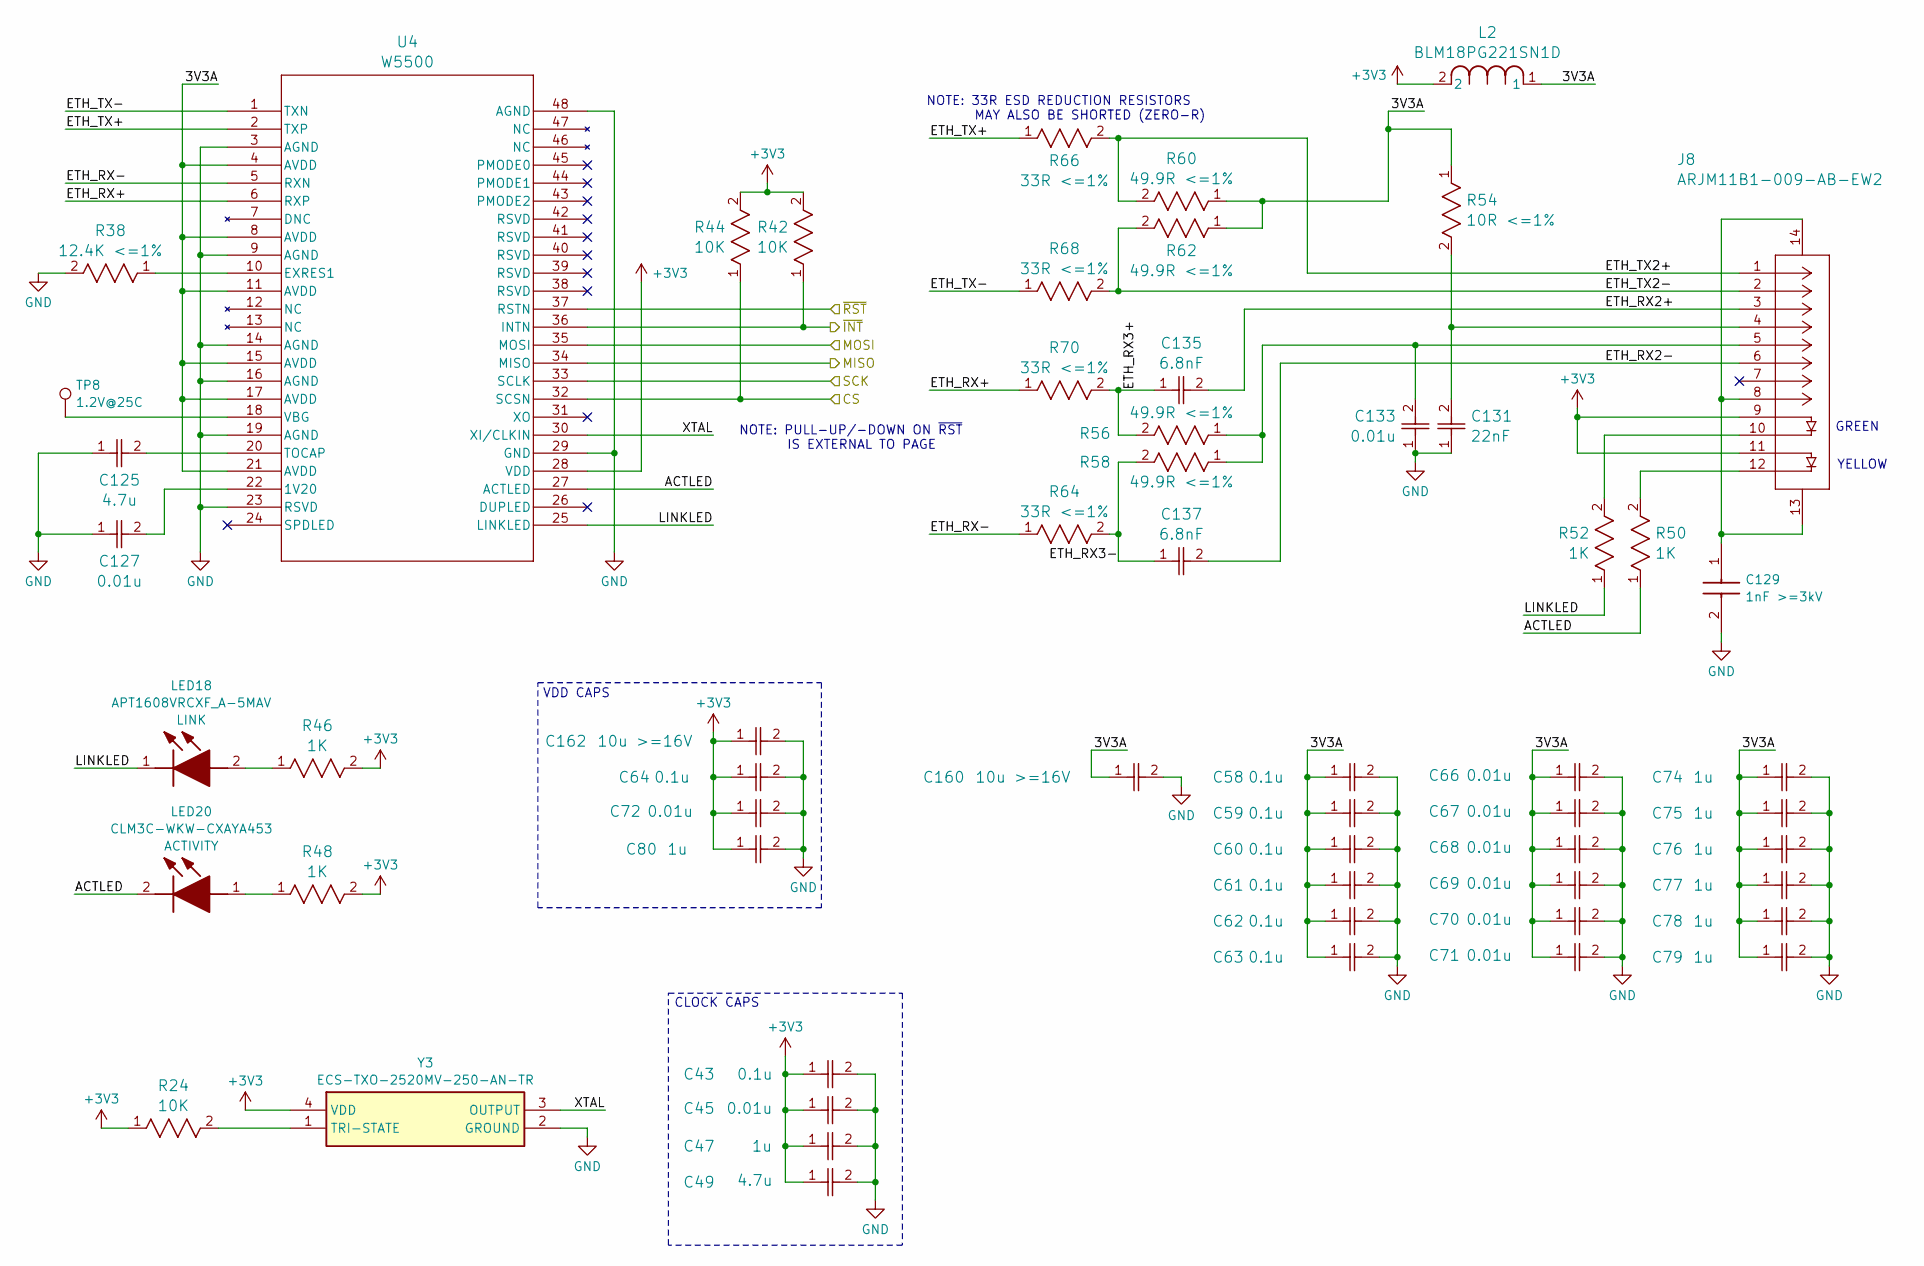
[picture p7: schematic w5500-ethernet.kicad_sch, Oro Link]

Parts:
C43, C58, C59, C60, C61, C62, C63, C64: 0.1u; CAP_MSAS1L-3_TAY; DigiKey ID 587-MSAST1L3YB5104KFNA01CT-ND
C45, C66, C67, C68, C69, C70, C71, C72, C127, C133: 0.01u; CAP_0402_N_WAL; Mouser ID 791-0402B103J160CT
C47, C74, C75, C76, C77, C78, C79, C80: 1u; cap_UMK105 CG080CV-F_TAY; DigiKey ID 587-3766-1-ND
C49, C125: 4.7u; GRM15x; Manufacturer_Part_Number GRM155C61E475ME15J; DigiKey ID 1276-1480-6-ND
C129: 1nF >=3kV; CAPC4620X220N; Manufacturer_Part_Number 885342210004; Mouser Part Number 710-885342210004
C131: 22nF; CAP_CC0402_YAG; Mouser URL null
C135, C137: 6.8nF; CAPC17595_87N_KEM; Mouser URL null
C160, C162: 10u >=16V; CAP_GRM18_1p8X1p1X1p1_MUR; Mouser ID 81-GRM188R61E106MA3D
J8: ARJM11B1-009-AB-EW2; CONN12_ARJM11B1-009-AB-EW2_ABR; Mouser ID 815-RJM11B1009ABEW2
L2: BLM18PG221SN1D; IND_BLM18_0603_MUR; DigiKey ID 490-5221-1-ND
LED18: APT1608VRCXF_A-5MAV; APT1608VRCXFA5MAV; Manufacturer_Part_Number APT1608VRCXF/A-5MAV; Mouser Part Number 604-APT1608VRCXF5MAV
LED20: CLM3C-WKW-CXAYA453; CLM3CWKWCXAYA453; Manufacturer_Part_Number CLM3C-WKW-CXAYA453; Mouser Part Number 941-CLM3CWKWCXAYA453
R24, R42, R44: 10K; STA_RMCF0402_STP; DigiKey ID RMCF0402FT10K0CT-ND
R38: 12.4K <=1%; RES_CRCW_0402; Mouser ID 71-CRCW0402-12.4K-E3
R46, R48, R50, R52: 1K; RES_SG73P_2A_KOA; Mouser URL null
R54: 10R <=1%; RC0402N_PAN; Mouser ID 667-ERA-2AKD100X
R56, R58, R60, R62: 49.9R <=1%; RC0402N_YAG; Mouser URL null
R64, R66, R68, R70: 33R <=1%; RES_0510_SUS; DigiKey ID RR05R33DCT-ND
TP8: 1.2V@25C; TestPoint_Pad_D1.0mm
U4: W5500; 48LQFP_W5500_WIZ; Mouser ID 950-W5500
Y3: ECS-TXO-2520MV-250-AN-TR; ECSTXO2520MV250ANTR; Manufacturer_Part_Number ECS-TXO-2520MV-250-AN-TR; Mouser Part Number 520-TXO2520MV250ANTR

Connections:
+3V3: C43.1, C45.1, C47.1, C49.1, C64.1, C72.1, C80.1, C162.1, J8.9, J8.11, L2.2, R24.1, R42.2, R44.2, R46.2, R48.2, U4.28 (VDD), Y3.4 (VDD); also elsewhere on the board
/SPI3_MISO: U4.34 (MISO); also elsewhere on the board
/SPI3_MOSI: U4.35 (MOSI); also elsewhere on the board
/SPI3_SCK: U4.33 (SCLK); also elsewhere on the board
/SYSETH_CS: R44.1, U4.32 (SCSN); also elsewhere on the board
/SYSETH_~INT: R42.1, U4.36 (INTN); also elsewhere on the board
/SYSETH_~RST: U4.37 (RSTN); also elsewhere on the board
/System Ethernet/3V3A: C58.1, C59.1, C60.1, C61.1, C62.1, C63.1, C66.1, C67.1, C68.1, C69.1, C70.1, C71.1, C74.1, C75.1, C76.1, C77.1, C78.1, C79.1, C160.1, L2.1, R54.1, R60.1, R62.1, U4.4 (AVDD), U4.8 (AVDD), U4.11 (AVDD), U4.15 (AVDD), U4.17 (AVDD), U4.21 (AVDD)
/System Ethernet/ACTLED: LED20.2 (K), R50.1, U4.27 (ACTLED)
/System Ethernet/ETH_RX2+: C135.2, J8.3
/System Ethernet/ETH_RX2-: C137.2, J8.6
/System Ethernet/ETH_RX3+: C135.1, R56.2, R70.2
/System Ethernet/ETH_RX3-: C137.1, R58.2, R64.2
/System Ethernet/ETH_RX+: R70.1, U4.6 (RXP)
/System Ethernet/ETH_RX-: R64.1, U4.5 (RXN)
/System Ethernet/ETH_TX2+: J8.1, R60.2, R66.2
/System Ethernet/ETH_TX2-: J8.2, R62.2, R68.2
/System Ethernet/ETH_TX+: R66.1, U4.2 (TXP)
/System Ethernet/ETH_TX-: R68.1, U4.1 (TXN)
/System Ethernet/LINKLED: LED18.1 (K), R52.1, U4.25 (LINKLED)
/System Ethernet/XTAL: U4.30 (XI/CLKIN), Y3.3 (OUTPUT)
GND: C43.2, C45.2, C47.2, C49.2, C58.2, C59.2, C60.2, C61.2, C62.2, C63.2, C64.2, C66.2, C67.2, C68.2, C69.2, C70.2, C71.2, C72.2, C74.2, C75.2, C76.2, C77.2, C78.2, C79.2, C80.2, C125.1, C127.1, C129.2, C131.1, C133.1, C160.2, C162.2, R38.2, U4.3 (AGND), U4.9 (AGND), U4.14 (AGND), U4.16 (AGND), U4.19 (AGND), U4.23 (RSVD), U4.29 (GND), U4.48 (AGND), Y3.2 (GROUND); also elsewhere on the board
unnamed: C129.1, J8.8, J8.13, J8.14
unnamed: C131.2, J8.4, R54.2
unnamed: C133.2, J8.5, R56.1, R58.1
unnamed: J8.10, R52.2
unnamed: J8.12, R50.2
unnamed: LED18.2 (A), R46.1
unnamed: LED20.1 (A), R48.1
unnamed: C127.2, U4.22 (1V20)
unnamed: R38.1, U4.10 (EXRES1)
unnamed: C125.2, U4.20 (TOCAP)
unnamed: TP8.1, U4.18 (VBG)
unnamed: R24.2, Y3.1 (TRI-STATE)

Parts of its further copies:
C44, C82, C83, C84, C85, C86, C87, C88: 0.1u; CAP_MSAS1L-3_TAY; DigiKey ID 587-MSAST1L3YB5104KFNA01CT-ND
C46, C90, C91, C92, C93, C94, C95, C96, C128, C134: 0.01u; CAP_0402_N_WAL; Mouser ID 791-0402B103J160CT
C48, C98, C99, C100, C101, C102, C103, C104: 1u; cap_UMK105 CG080CV-F_TAY; DigiKey ID 587-3766-1-ND
C50, C126: 4.7u; GRM15x; Manufacturer_Part_Number GRM155C61E475ME15J; DigiKey ID 1276-1480-6-ND
C130: 1nF >=3kV; CAPC4620X220N; Manufacturer_Part_Number 885342210004; Mouser Part Number 710-885342210004
C132: 22nF; CAP_CC0402_YAG; Mouser URL null
C136, C138: 6.8nF; CAPC17595_87N_KEM; Mouser URL null
C161, C163: 10u >=16V; CAP_GRM18_1p8X1p1X1p1_MUR; Mouser ID 81-GRM188R61E106MA3D
J9: ARJM11B1-009-AB-EW2; CONN12_ARJM11B1-009-AB-EW2_ABR; Mouser ID 815-RJM11B1009ABEW2
L3: BLM18PG221SN1D; IND_BLM18_0603_MUR; DigiKey ID 490-5221-1-ND
LED19: APT1608VRCXF_A-5MAV; APT1608VRCXFA5MAV; Manufacturer_Part_Number APT1608VRCXF/A-5MAV; Mouser Part Number 604-APT1608VRCXF5MAV
LED21: CLM3C-WKW-CXAYA453; CLM3CWKWCXAYA453; Manufacturer_Part_Number CLM3C-WKW-CXAYA453; Mouser Part Number 941-CLM3CWKWCXAYA453
R25, R43, R45: 10K; STA_RMCF0402_STP; DigiKey ID RMCF0402FT10K0CT-ND
R39: 12.4K <=1%; RES_CRCW_0402; Mouser ID 71-CRCW0402-12.4K-E3
R47, R49, R51, R53: 1K; RES_SG73P_2A_KOA; Mouser URL null
R55: 10R <=1%; RC0402N_PAN; Mouser ID 667-ERA-2AKD100X
R57, R59, R61, R63: 49.9R <=1%; RC0402N_YAG; Mouser URL null
R65, R67, R69, R71: 33R <=1%; RES_0510_SUS; DigiKey ID RR05R33DCT-ND
TP9: 1.2V@25C; TestPoint_Pad_D1.0mm
U5: W5500; 48LQFP_W5500_WIZ; Mouser ID 950-W5500
Y4: ECS-TXO-2520MV-250-AN-TR; ECSTXO2520MV250ANTR; Manufacturer_Part_Number ECS-TXO-2520MV-250-AN-TR; Mouser Part Number 520-TXO2520MV250ANTR

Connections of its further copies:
+3V3: C44.1, C46.1, C48.1, C50.1, C88.1, C96.1, C104.1, C163.1, J9.9, J9.11, L3.2, R25.1, R43.2, R45.2, R47.2, R49.2, U5.28 (VDD), Y4.4 (VDD); also elsewhere on the board
/EXTETH_CS: R45.1, U5.32 (SCSN); also elsewhere on the board
/EXTETH_~INT: R43.1, U5.36 (INTN); also elsewhere on the board
/EXTETH_~RST: U5.37 (RSTN); also elsewhere on the board
/External Ethernet/3V3A: C82.1, C83.1, C84.1, C85.1, C86.1, C87.1, C90.1, C91.1, C92.1, C93.1, C94.1, C95.1, C98.1, C99.1, C100.1, C101.1, C102.1, C103.1, C161.1, L3.1, R55.1, R61.1, R63.1, U5.4 (AVDD), U5.8 (AVDD), U5.11 (AVDD), U5.15 (AVDD), U5.17 (AVDD), U5.21 (AVDD)
/External Ethernet/ACTLED: LED21.2 (K), R51.1, U5.27 (ACTLED)
/External Ethernet/ETH_RX2+: C136.2, J9.3
/External Ethernet/ETH_RX2-: C138.2, J9.6
/External Ethernet/ETH_RX3+: C136.1, R57.2, R71.2
/External Ethernet/ETH_RX3-: C138.1, R59.2, R65.2
/External Ethernet/ETH_RX+: R71.1, U5.6 (RXP)
/External Ethernet/ETH_RX-: R65.1, U5.5 (RXN)
/External Ethernet/ETH_TX2+: J9.1, R61.2, R67.2
/External Ethernet/ETH_TX2-: J9.2, R63.2, R69.2
/External Ethernet/ETH_TX+: R67.1, U5.2 (TXP)
/External Ethernet/ETH_TX-: R69.1, U5.1 (TXN)
/External Ethernet/LINKLED: LED19.1 (K), R53.1, U5.25 (LINKLED)
/External Ethernet/XTAL: U5.30 (XI/CLKIN), Y4.3 (OUTPUT)
/SPI4_MISO: U5.34 (MISO); also elsewhere on the board
/SPI4_MOSI: U5.35 (MOSI); also elsewhere on the board
/SPI4_SCK: U5.33 (SCLK); also elsewhere on the board
GND: C44.2, C46.2, C48.2, C50.2, C82.2, C83.2, C84.2, C85.2, C86.2, C87.2, C88.2, C90.2, C91.2, C92.2, C93.2, C94.2, C95.2, C96.2, C98.2, C99.2, C100.2, C101.2, C102.2, C103.2, C104.2, C126.1, C128.1, C130.2, C132.1, C134.1, C161.2, C163.2, R39.2, U5.3 (AGND), U5.9 (AGND), U5.14 (AGND), U5.16 (AGND), U5.19 (AGND), U5.23 (RSVD), U5.29 (GND), U5.48 (AGND), Y4.2 (GROUND); also elsewhere on the board
unnamed: C130.1, J9.8, J9.13, J9.14
unnamed: C132.2, J9.4, R55.2
unnamed: C134.2, J9.5, R57.1, R59.1
unnamed: J9.10, R53.2
unnamed: J9.12, R51.2
unnamed: LED19.2 (A), R47.1
unnamed: LED21.1 (A), R49.1
unnamed: C128.2, U5.22 (1V20)
unnamed: R39.1, U5.10 (EXRES1)
unnamed: C126.2, U5.20 (TOCAP)
unnamed: TP9.1, U5.18 (VBG)
unnamed: R25.2, Y4.1 (TRI-STATE)

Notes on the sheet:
YELLOW
VDD CAPS
NOTE: 33R ESD REDUCTION RESISTORS MAY ALSO BE SHORTED (ZERO-R)
NOTE: PULL-UP/-DOWN ON ~{RST} IS EXTERNAL TO PAGE
GREEN
CLOCK CAPS

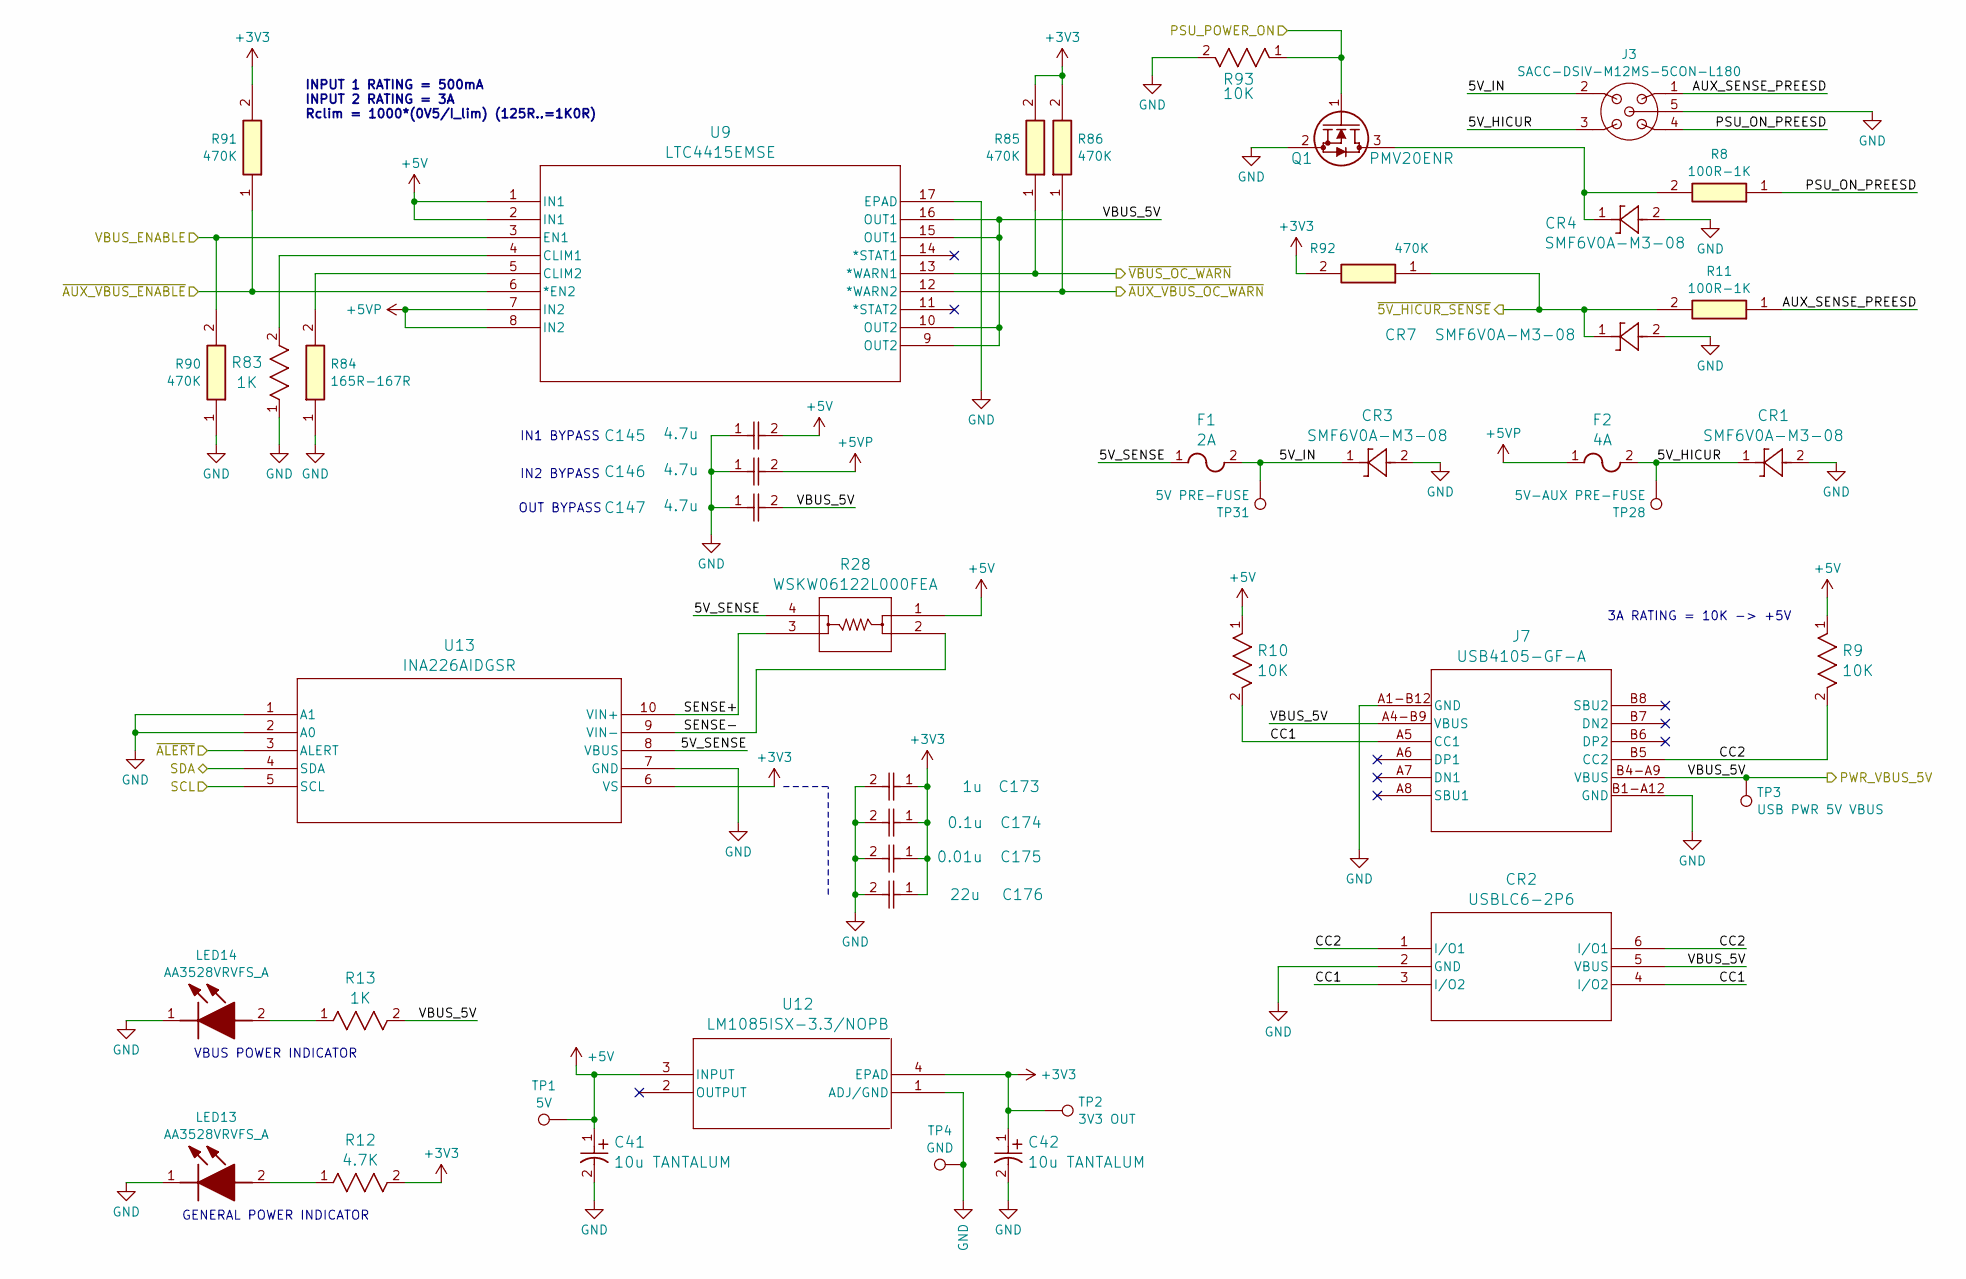
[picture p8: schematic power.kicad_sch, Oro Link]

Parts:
C41, C42: 10u TANTALUM; CAPMP3.7X2.8_2.1N_KEM; Mouser ID 80-T491B106M020
C145, C146, C147: 4.7u; GRM15x; Manufacturer_Part_Number GRM155C61E475ME15J; DigiKey ID 1276-1480-6-ND
C173: 1u; cap_UMK105 CG080CV-F_TAY; DigiKey ID 587-3766-1-ND
C174: 0.1u; CAP_MSAS1L-3_TAY; DigiKey ID 587-MSAST1L3YB5104KFNA01CT-ND
C175: 0.01u; CAP_0402_N_WAL; Mouser ID 791-0402B103J160CT
C176: 22u; CAP_CL10_SAM; DigiKey ID 1276-7076-1-ND
CR1, CR3, CR4, CR7: SMF6V0A-M3-08; ZDO_SMF_DO-219AB_VIS; Mouser ID 78-SMF6V0A-M3-08
CR2: USBLC6-2P6; SOT-666_STM; Mouser ID 511-USBLC6-2P6
F1: 2A; 0697_BEL; Mouser ID 530-0697H2000-02
F2: 4A; 0697_BEL; Mouser ID 530-0697H4000-01
J3: SACC-DSIV-M12MS-5CON-L180; Mouser ID 651-1694211
J7: USB4105-GF-A; USB4105_GCT; DigiKey ID 2073-USB4105-GF-ACT-ND
LED13, LED14: AA3528VRVFS_A; AA3528VRVFSA; Manufacturer_Part_Number AA3528VRVFS/A; Mouser Part Number 604-AA3528VRVFS/A
Q1: PMV20ENR; QNMOS1G2S3D_TO-236AB_SOT23_NEX; DigiKey ID 1727-2301-1-ND
R8, R11: 100R-1K; RESC1005X40N; Manufacturer_Part_Number CR0402-FX-1650GLF; Mouser Part Number 652-CR0402-FX1650GLF
R9, R10, R93: 10K; STA_RMCF0402_STP; DigiKey ID RMCF0402FT10K0CT-ND
R12: 4.7K; RES_CRCW_0402_VIS-L; Mouser ID 71-CRCW04024K70FKEDH
R13, R83: 1K; RES_SG73P_2A_KOA; Mouser URL null
R28: WSKW06122L000FEA; WSKW0612_VIS; Mouser ID 71-WSKW06122L000FEA
R84: 165R-167R; RESC1005X40N; Manufacturer_Part_Number CR0402-FX-1650GLF; Mouser Part Number 652-CR0402-FX1650GLF
R85, R86, R90, R91, R92: 470K; CRCW0402470KFKED; Manufacturer_Part_Number CRCW0402470KFKED; Mouser Part Number 71-CRCW0402470KFKED
TP1: 5V; TestPoint_Pad_1.0x1.0mm
TP2: 3V3 OUT; TestPoint_Pad_1.0x1.0mm
TP3: USB PWR 5V VBUS; TestPoint_Pad_1.0x1.0mm
TP4: GND; TestPoint_Pad_1.0x1.0mm
TP28: 5V-AUX PRE-FUSE; TestPoint_Pad_1.0x1.0mm
TP31: 5V PRE-FUSE; TestPoint_Pad_1.0x1.0mm
U9: LTC4415EMSE; MSOP-16_MSE_LIT; DigiKey ID LTC4415EMSE#TRPBFCT-ND
U12: LM1085ISX-3.3/NOPB; KTT3; DigiKey ID LM1085ISX-3.3/NOPBCT-ND
U13: INA226AIDGSR; DGS10; Mouser ID 595-INA226AIDGSR

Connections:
+3V3: C42.1, C173.1, C174.1, C175.1, C176.1, R12.2, R85.2, R86.2, R91.2, R92.2, TP2.1, U12.4 (EPAD), U13.6 (VS); also elsewhere on the board
+5V: C41.1, C145.2, R9.1, R10.1, R28.1, TP1.1, U9.1 (IN1), U9.2 (IN1), U12.3 (INPUT); also elsewhere on the board
+5VP: C146.2, F2.1, U9.7 (IN2), U9.8 (IN2)
/I2C3_SCL: U13.5 (SCL); also elsewhere on the board
/I2C3_SDA: U13.4 (SDA); also elsewhere on the board
/PSU_POWER_ON: Q1.1 (G), R93.1; also elsewhere on the board
/PWR_VBUS_5V: C147.2, CR2.5 (VBUS), J7.A4-B9 (VBUS), J7.B4-A9 (VBUS), R13.2, TP3.1, U9.9 (OUT2), U9.10 (OUT2), U9.15 (OUT1), U9.16 (OUT1); also elsewhere on the board
/Power/5V_HICUR: CR1.1, F2.2, J3.3, TP28.1
/Power/5V_IN: CR3.1, F1.2, J3.2, TP31.1
/Power/5V_SENSE: F1.1, R28.4, U13.8 (VBUS)
/Power/AUX_SENSE_PREESD: J3.1, R11.1
/Power/CC1: CR2.3 (I/O2), CR2.4 (I/O2), J7.A5 (CC1), R10.2
/Power/CC2: CR2.1 (I/O1), CR2.6 (I/O1), J7.B5 (CC2), R9.2
/Power/PSU_ON_PREESD: J3.4, R8.1
/Power/SENSE+: R28.3, U13.10 (VIN+)
/Power/SENSE-: R28.2, U13.9 (VIN-)
/VBUS_EN: R90.2, U9.3 (EN1); also elsewhere on the board
/~AUX_VBUS_EN: R91.1, U9.6 (*EN2); also elsewhere on the board
/~AUX_VBUS_OC: R86.1, U9.12 (*WARN2); also elsewhere on the board
/~AUX_VBUS_SENSE: CR7.1, R11.2, R92.1; also elsewhere on the board
/~POWER_ALERT: U13.3 (ALERT); also elsewhere on the board
/~VBUS_PWR_OC: R85.1, U9.13 (*WARN1); also elsewhere on the board
GND: C41.2, C42.2, C145.1, C146.1, C147.1, C173.2, C174.2, C175.2, C176.2, CR1.2, CR2.2 (GND), CR3.2, CR4.2, CR7.2, J3.5, J7.A1-B12 (GND), J7.B1-A12 (GND), LED13.1 (K), LED14.1 (K), Q1.2 (S), R83.1, R84.1, R90.1, R93.2, TP4.1, U9.17 (EPAD), U12.1 (ADJ/GND), U13.1 (A1), U13.2 (A0), U13.7 (GND); also elsewhere on the board
unnamed: LED13.2 (A), R12.1
unnamed: LED14.2 (A), R13.1
unnamed: CR4.1, Q1.3 (D), R8.2
unnamed: R83.2, U9.4 (CLIM1)
unnamed: R84.2, U9.5 (CLIM2)

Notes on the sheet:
3A RATING = 10K -> +5V
VBUS POWER INDICATOR
IN2 BYPASS
IN1 BYPASS
INPUT 1 RATING = 500mA INPUT 2 RATING = 3A Rclim = 1000*(0V5/I_lim) (125R..=1K0R)
GENERAL POWER INDICATOR
OUT BYPASS

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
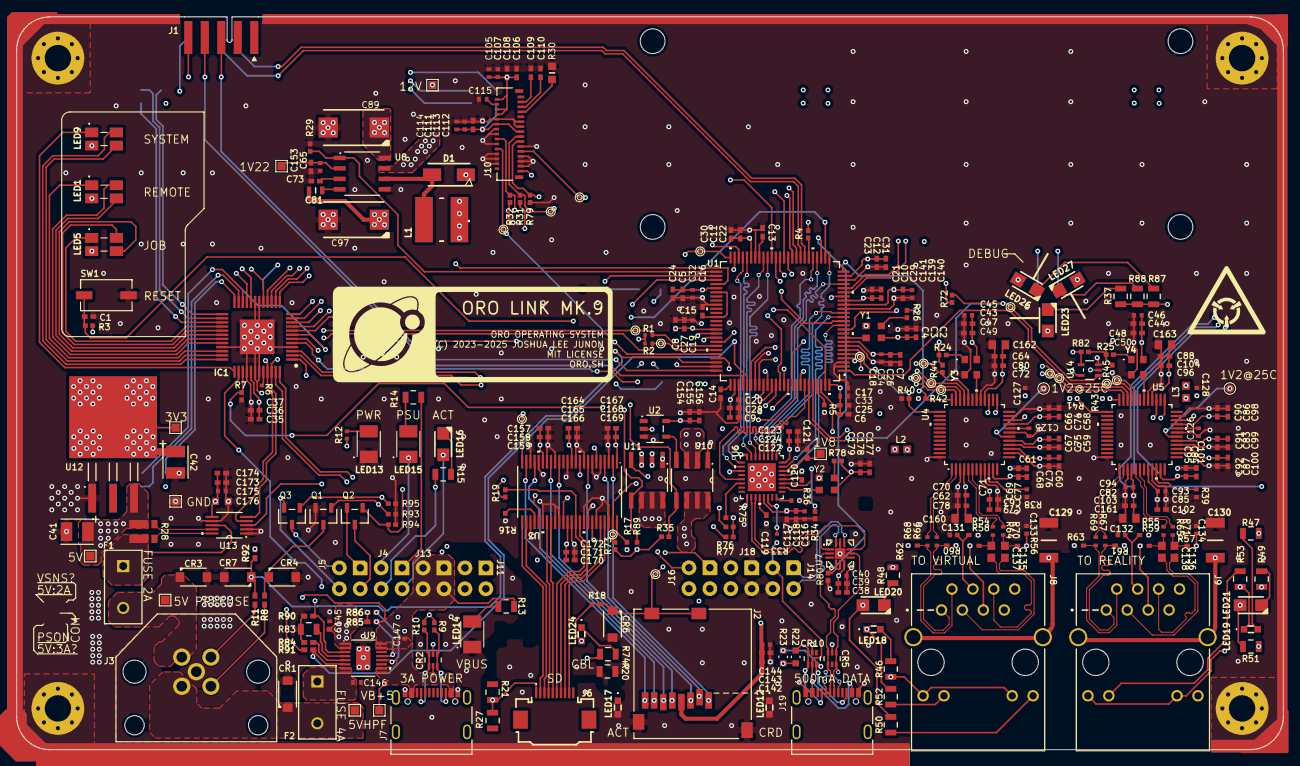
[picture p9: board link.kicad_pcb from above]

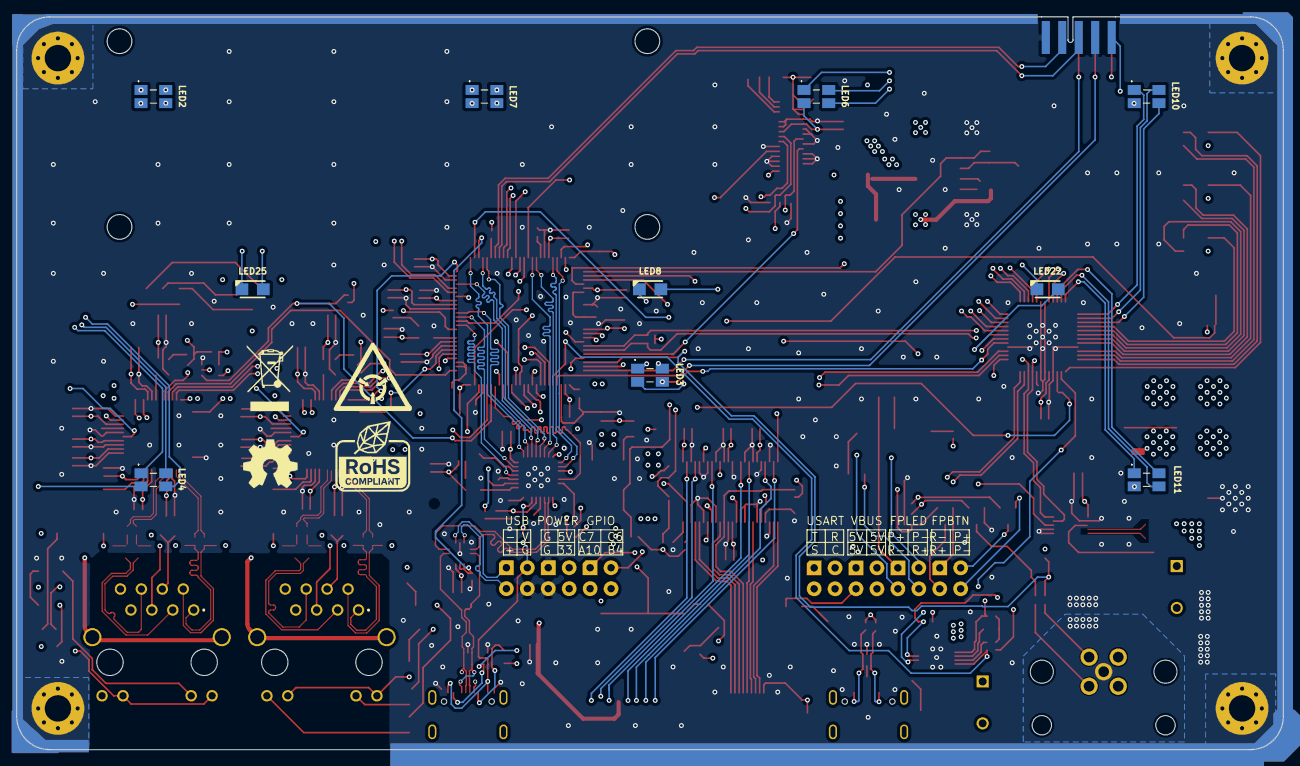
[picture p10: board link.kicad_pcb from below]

Board: 8 copper layers, 153.7 x 88.9 mm, 375 parts (17 on the bottom side), 251 nets.

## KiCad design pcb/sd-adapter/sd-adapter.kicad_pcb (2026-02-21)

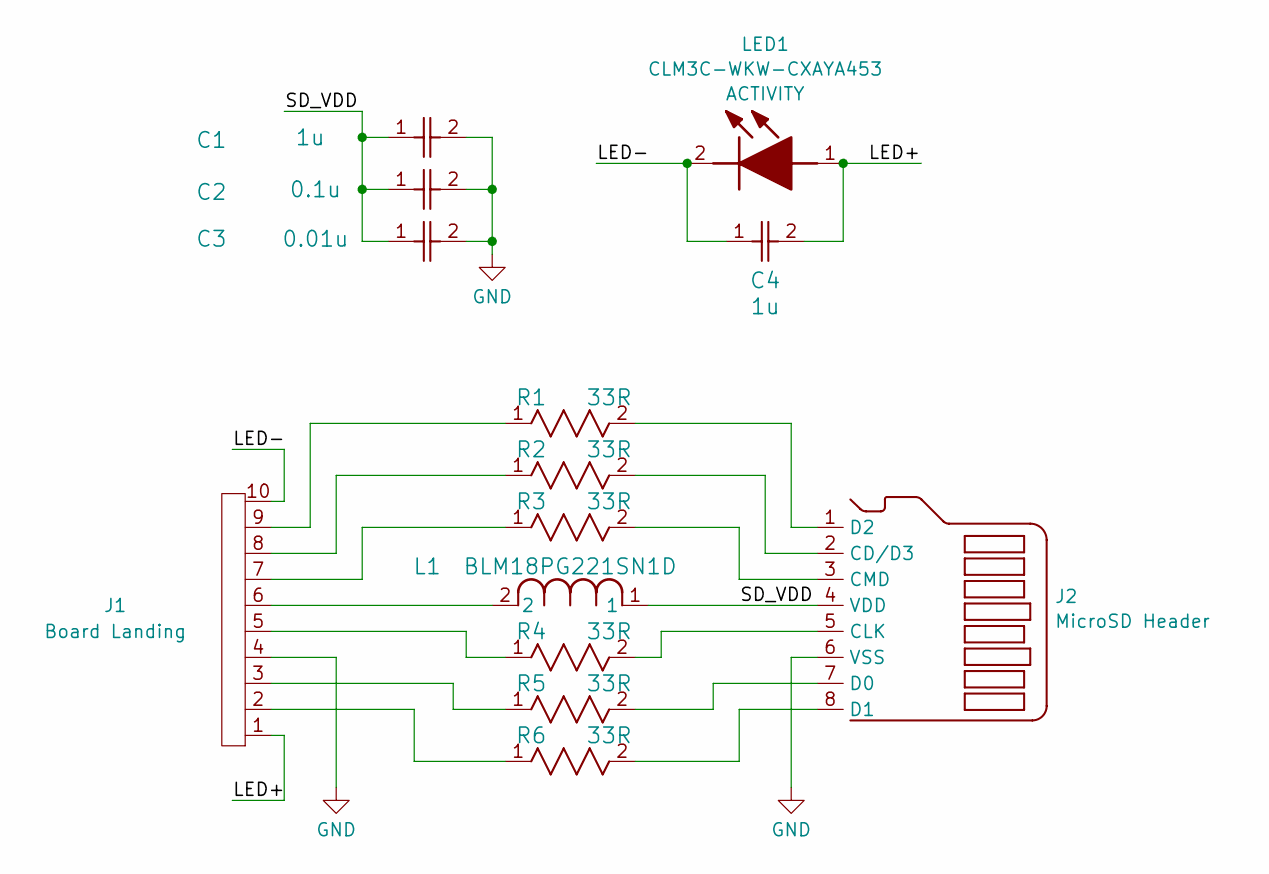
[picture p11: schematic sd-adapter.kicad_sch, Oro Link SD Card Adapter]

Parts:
C1, C4: 1u; cap_UMK105 CG080CV-F_TAY; DigiKey ID 587-3766-1-ND
C2: 0.1u; CAP_MSAS1L-3_TAY; DigiKey ID 587-MSAST1L3YB5104KFNA01CT-ND
C3: 0.01u; CAP_0402_N_WAL; Mouser ID 791-0402B103J160CT
J1: Board Landing; OroSDCardCouplingPadBoardSide
J2: MicroSD Header; SDCardOutlinePadsTop
L1: BLM18PG221SN1D; IND_BLM18_0603_MUR; DigiKey ID 490-5221-1-ND
LED1: CLM3C-WKW-CXAYA453; CLM3CWKWCXAYA453; Manufacturer_Part_Number CLM3C-WKW-CXAYA453; Mouser Part Number 941-CLM3CWKWCXAYA453
R1, R2, R3, R4, R5, R6: 33R; RES_0510_SUS; DigiKey ID RR05R33DCT-ND

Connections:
/LED+: C4.2, J1.1, LED1.1 (A); also elsewhere on the board
/LED-: C4.1, J1.10, LED1.2 (K); also elsewhere on the board
/SD_VDD: C1.1, C2.1, C3.1, J2.4 (VDD), L1.1
GND: C1.2, C2.2, C3.2, J1.4, J2.6 (VSS)
unnamed: J1.2, R6.1
unnamed: J1.3, R5.1
unnamed: J1.5, R4.1
unnamed: J1.6, L1.2
unnamed: J1.7, R3.1
unnamed: J1.8, R2.1
unnamed: J1.9, R1.1
unnamed: J2.2 (CD/D3), R2.2
unnamed: J2.5 (CLK), R4.2
unnamed: J2.3 (CMD), R3.2
unnamed: J2.7 (D0), R5.2
unnamed: J2.8 (D1), R6.2
unnamed: J2.1 (D2), R1.2

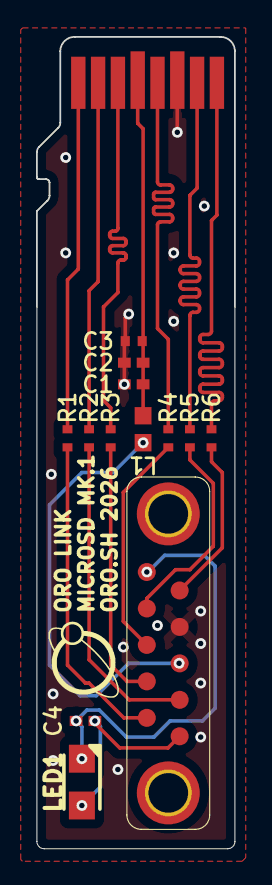
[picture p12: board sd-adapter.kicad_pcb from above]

Board: 2 copper layers, 11.0 x 45.1 mm, 15 parts (1 on the bottom side), 17 nets.

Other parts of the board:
LED2: CLM3C-WKW-CXAYA453; CLM3CWKWCXAYA453

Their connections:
/LED+: LED2.1 (A); also elsewhere on the board
/LED-: LED2.2 (K); also elsewhere on the board

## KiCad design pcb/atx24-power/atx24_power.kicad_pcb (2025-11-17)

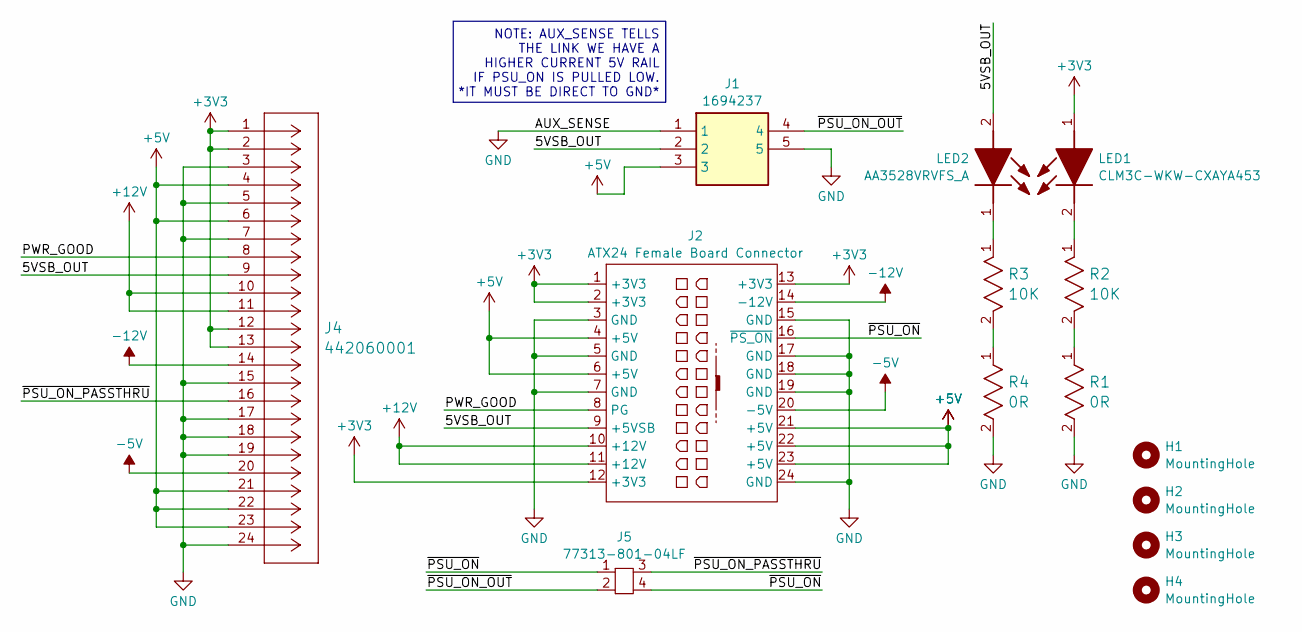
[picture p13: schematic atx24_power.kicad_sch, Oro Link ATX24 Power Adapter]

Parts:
H1, H2, H3, H4: MountingHole; MountingHole_3.2mm_M3
J1: 1694237; Manufacturer_Part_Number 1694237; Mouser Part Number 651-1694237
J2: ATX24 Female Board Connector; ATX24_Female_Board_Connector
J4: 442060001; CONN_SDA-44206-001_24_BP_MOL; Mouser ID 538-44206-0001
J5: 77313-801-04LF; 2x2 4p 2.54 pitch straight; Mouser ID Number 649-77313-801-04LF
LED1: CLM3C-WKW-CXAYA453; CLM3CWKWCXAYA453; Manufacturer_Part_Number CLM3C-WKW-CXAYA453; Mouser Part Number 941-CLM3CWKWCXAYA453
LED2: AA3528VRVFS_A; AA3528VRVFSA; Manufacturer_Part_Number AA3528VRVFS/A; Mouser Part Number 604-AA3528VRVFS/A
R1, R4: 0R; RES_RK73Z1E_KOA; DigiKey ID 2019-RK73Z1ETTPCT-ND
R2, R3: 10K; STA_RMCF0402_STP; DigiKey ID RMCF0402FT10K0CT-ND

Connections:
+3V3: J2.1 (+3V3), J2.2 (+3V3), J2.12 (+3V3), J2.13 (+3V3), J4.1, J4.2, J4.12, J4.13, LED1.1 (A)
+5V: J1.3, J2.4 (+5V), J2.6 (+5V), J2.21 (+5V), J2.22 (+5V), J2.23 (+5V), J4.4, J4.6, J4.21, J4.22, J4.23
+12V: J2.10 (+12V), J2.11 (+12V), J4.10, J4.11
-5V: J2.20 (-5V), J4.20
-12V: J2.14 (-12V), J4.14
/5VSB_OUT: J1.2, J2.9 (+5VSB), J4.9, LED2.2 (A)
/PWR_GOOD: J2.8 (PG), J4.8
/~PSU_ON_OUT: J1.4, J5.2
/~PSU_ON_PASSTHRU: J4.16, J5.3
/~PSU_ON: J2.16 (~PS_ON), J5.1, J5.4
GND: J1.1, J1.5, J2.3 (GND), J2.5 (GND), J2.7 (GND), J2.15 (GND), J2.17 (GND), J2.18 (GND), J2.19 (GND), J2.24 (GND), J4.3, J4.5, J4.7, J4.15, J4.17, J4.18, J4.19, J4.24, R1.2, R4.2
unnamed: LED1.2 (K), R2.1
unnamed: LED2.1 (K), R3.1
unnamed: R1.1, R2.2
unnamed: R3.2, R4.1

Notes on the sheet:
NOTE: AUX_SENSE TELLS THE LINK WE HAVE A HIGHER CURRENT 5V RAIL IF PSU_ON IS PULLED LOW. *IT MUST BE DIRECT TO GND*


Board: 2 copper layers, 88.5 x 39.5 mm, 14 parts (1 on the bottom side), 15 nets.

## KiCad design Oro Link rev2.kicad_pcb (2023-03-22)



Board: 4 copper layers, 148 parts (18 on the bottom side), 148 nets.

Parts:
C1, C5, C6, C7, C8, C9, C10, C11, C13, C29, C30, C32, C33, C34, C35, C36, C38, C39, C41, C42, C43, C44, C45, C51: 0.1u; CAPC0402X22N
C2, C20: 4.7u; CAPC2012X135N
C3, C4, C12: 2.2u; CAPC1608X90N
C14, C18, C19, C21, C52: 1u; CAPC1608X90N
C15, C16, C17, C28, C37: 10u; CAPC2012X135N
C22: 4,7u; CAPC2012X135N
C23: 0.01u; CAPC2012X75N
C24: 0.047u; C1608_Commercial_Tight
C25: 0.001u; C1608_Commercial_Tight
C26, C27: 33u; CAPPM7343X310N
C31, C40: 1nF 5kV; CAPC5664X270N
C46, C47, C48, C49, C50: 0.1u; CAPAE430X610N
D1: SS12; DIOM5227X250N
D2, D3, D4, D5, D6, D7, D8, D9, D14, D15: ESDS302DBVR; SOT95P280X145-5N
D10: RFU02VSM8STR; SODFL2514X80N
D11, D13: RCLAMP3552T.TNT; RCLAMP3552TTNT
D12: P6SMB15A-Q; DIOM5436X244N
D16: SMDA05C-8.TBT; SOIC127P600X175-14N
FB1: CD54NP-180MC; CD54NP180MC
FB2, FB3: BLM18BB600SZ1D; BLM18EG121SH1D
H1, H2, H3, H4, H5, H6: MountingHole_Pad; MountingHole_3.2mm_M3_Pad_Via
IC1: STM32F479VGT6; QFP50P1600X1600X160-100N
IC2: TPS73733DCQ; SOT127P706X180-6N
IC3: TPS6734IDR; SOIC127P600X175-8N
IC4, IC5: ENC28J60-I_SO; SOIC127P1030X265-28N
IC6: SN75C3232EPWR; SOP65P640X120-16N
IC7: IS31FL3218-GRLS2; SOIC127P1036X265-24N
J1: DF63-5P-3.96DS; DF635P396DS
J2, J9: 67996-110HLF; HDRV10W67P254_2X5_1270X483X858P
J3: 3-2328724-1; 323287241
J4, J5: SS-60300-103; SS60300103
J6: OroConn6p; OroConn6p_WithMounts
J7, J8: 10129378-902003BLF; HDRV2W67P0X254_1X2_508X241X1082P
LED1, LED2: AA3528VRVFS/A; AA3528VRVFSA
LED3: CLM3C-WKW-CXAYA453; CLM3CWKWCXAYA453
LED4, LED5, LED6: 150120M173000
Q1, Q2, Q3: PMV20ENR; SOT95P230X110-3N
R1, R2: 4.7k; RESC1005X40N
R3, R5, R8, R9, R10, R11, R12, R24, R37: 10k; RESC5025X65N
R4, R6, R7: 1k; RESC2012X60N
R13, R25: 2.32k, <=1%; ERJP06__0805_
R14, R15, R16, R17, R26, R27, R28, R29: RC1210FR-0749R9L; RESC0603X26N
R18, R19, R20, R21, R30, R31, R32, R33: 75R; RESC1005X40N
R22, R23, R34, R35: 470R; RESC2012X60N
R36: 3.3k; RESC1608X55N
S1: TL6400AF160QJ
S2: MSS225004
S3: 206-124; 206124
S4: 206-125; 206125
T1, T2: PT61017XPEL; SOIC127P930X570-16N
X1: 7P-26.000MBP-T
Y1, Y2: 25MHz; ASE24576MHZLCT

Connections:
+3V3: C2.1, C5.2, C6.2, C7.2, C8.2, C9.2, C10.2, C11.2, C12.1, C13.2, C14.2, C17.2, C21.2, C32.1, C35.1, C36.1, C41.1, C44.1, C45.1, C49.1, C51.1, C52.2, FB2.1, FB3.1, IC1.3 (VBAT), IC1.8 (VDD_1), IC1.17 (VREF+), IC1.18 (VDDA), IC1.24 (VDD_2), IC1.45 (VDD_3), IC1.55 (VDDDSI), IC1.56 (VCAPDSI), IC1.62 (VDD12DSI), IC1.65 (VDDUSB), IC1.77 (VDD_4), IC1.100 (VDD_5), IC2.2 (OUT), IC4.15 (VDDTX), IC4.19 (VDDRX), IC4.20 (VDDPLL), IC4.25 (VDDOSC), IC4.28 (VDD), IC5.15 (VDDTX), IC5.19 (VDDRX), IC5.20 (VDDPLL), IC5.25 (VDDOSC), IC5.28 (VDD), IC6.16 (VCC), IC7.3 (VCC), J3.12, J3.15, LED1.2, LED4.2 (A_G), LED5.2 (A_G), LED6.2 (A_G), R1.1, R2.1, R3.1, R9.2, R37.1, X1.6 (VCC), Y1.4 (VDD), Y2.4 (VDD)
+5V: C15.1, C26.1, D10.1, FB1.1, IC2.1 (IN), IC3.8 (VCC), J1.4, R5.1, R11.2, S2.1
/COM Bus Header/C1+: C46.1, IC6.1 (C1+)
/COM Bus Header/C1-: C46.2, IC6.3 (C1-)
/COM Bus Header/C2+: C47.1, IC6.4 (C2+)
/COM Bus Header/C2-: C47.2, IC6.5 (C2-)
/COM Bus Header/D_CTS: S3.9, S3.12, S4.C2, S4.C3
/COM Bus Header/D_RTS: S3.10, S3.11, S4.D2, S4.D3
/COM Bus Header/D_RX: S3.14, S3.15, S4.B2, S4.B3
/COM Bus Header/D_TX: S3.13, S3.16, S4.A2, S4.A3
/COM Bus Header/P2: D16.2 (I/O_1), J9.2, S4.B1
/COM Bus Header/P3: D16.13 (I/O_8), J9.3, S4.A1, S4.B4
/COM Bus Header/P4: D16.3 (I/O_2), J9.4, S4.D4
/COM Bus Header/P5: D16.12 (I/O_7), J9.5, S4.A4, S4.E1
/COM Bus Header/P6: D16.5 (I/O_3), J9.6, S4.C4
/COM Bus Header/P7: D16.10 (I/O_6), J9.7, S4.D1
/COM Bus Header/P8: D16.6 (I/O_4), J9.8, S4.C1
/COM Bus Header/P9: D16.9 (I/O_5), J9.9, S4.E4
/COM Bus Header/UART_CTS: IC1.87 (PD3), IC6.9 (ROUT2)
/COM Bus Header/UART_RTS: IC1.20 (PA1), IC6.10 (DIN2)
/COM Bus Header/UART_RX: IC1.22 (PA3), IC6.12 (ROUT1)
/COM Bus Header/UART_TX: IC1.21 (PA2), IC6.11 (DIN1)
/COM Bus Header/V+: C48.1, IC6.2 (V+)
/COM Bus Header/V-: C50.2, IC6.6 (V-)
/External Ethernet/CT_45: D8.4 (I/O1), D8.5 (I/O2), J5.4, J5.5, R32.1
/External Ethernet/CT_78: D9.4 (I/O1), D9.5 (I/O2), J5.7, J5.8, R33.1
/External Ethernet/GLED+: IC5.27 (LEDA), R34.2
/External Ethernet/RX+: D7.5 (I/O2), J5.3, T2.11 (RX+)
/External Ethernet/RX-: D7.4 (I/O1), J5.6, T2.9 (RX-)
/External Ethernet/SCK: IC1.41 (PB10), IC5.8 (SCK)
/External Ethernet/SDI: IC1.15 (PC3), IC5.7 (SI)
/External Ethernet/SDO: IC1.14 (PC2), IC5.6 (SO)
/External Ethernet/TPIN+: IC5.13 (TPIN+), R28.1, T2.6 (RD+)
/External Ethernet/TPIN-: IC5.12 (TPIN-), R29.1, T2.8 (RD-)
/External Ethernet/TPOUT+: IC5.17 (TPOUT+), R26.1, T2.1 (TD+)
/External Ethernet/TPOUT-: IC5.16 (TPOUT-), R27.1, T2.3 (TD-)
/External Ethernet/TX+: D6.4 (I/O1), J5.1, T2.16 (TX+)
/External Ethernet/TX-: D6.5 (I/O2), J5.2, T2.14 (TX-)
/External Ethernet/YLED+: IC5.26 (LEDB), R35.2
/External Ethernet/~INT: IC1.99 (PB9), IC5.4 (~INT)
/External Ethernet/~RST: IC1.4 (PC13), IC5.10 (~RESET)
/Front Panel Client/HDD+: J2.6, R7.1
/Front Panel Client/HDD-: J2.8, LED3.2
/Front Panel Client/PLED+: J2.1, R6.2
/Front Panel Client/PLED-: J2.3, LED2.1
/Front Panel Client/PWR+: J2.5, Q2.3
/Front Panel Client/PWR-: J2.7, Q2.2
/Front Panel Client/PWR_ON: IC1.50 (PD8), Q2.1
/Front Panel Client/RESET: IC1.49 (PB15), Q3.1
/Front Panel Client/RST+: J2.2, Q3.3
/Front Panel Client/RST-: J2.4, Q3.2
/Indicator Lights/O7: IC7.13 (O7), LED6.3 (K_G)
/Indicator Lights/O8: IC7.14 (O8), LED6.4 (K_R)
/Indicator Lights/O9: IC7.15 (O9), LED6.1 (K_B)
/Indicator Lights/O10: IC7.16 (O10), LED5.3 (K_G)
/Indicator Lights/O11: IC7.17 (O11), LED5.4 (K_R)
/Indicator Lights/O12: IC7.18 (O12), LED5.1 (K_B)
/Indicator Lights/O13: IC7.19 (O13), LED4.3 (K_G)
/Indicator Lights/O14: IC7.20 (O14), LED4.4 (K_R)
/Indicator Lights/O15: IC7.21 (O15), LED4.1 (K_B)
/Indicator Lights/SCL: IC1.95 (PB6), IC7.6 (SCL), R1.2
/Indicator Lights/SDA: IC1.96 (PB7), IC7.5 (SDA), R2.2
/Microcontroller/DBGUART_RX: D14.4 (I/O1), IC1.32 (PE7), J7.1
/Microcontroller/DBGUART_TX: D14.5 (I/O2), IC1.33 (PE8), J7.2
/Microcontroller/SYSETH_MISO: IC1.27 (PA6), IC4.6 (SO)
/Microcontroller/SYSETH_SCK: IC1.26 (PA5), IC4.8 (SCK)
/Microcontroller/SYSTEH_MOSI: IC1.28 (PA7), IC4.7 (SI)
/Microcontroller/SYSTEH_~INT: IC1.30 (PB1), IC4.4 (~INT)
/Microcontroller/SYSTEH_~RST: IC1.29 (PB0), IC4.10 (~RESET)
/Microcontroller/USB_D+: D15.5 (I/O2), IC1.74 (PA12), J8.2
/Microcontroller/USB_D-: D15.4 (I/O1), IC1.73 (PA11), J8.1
/Microcontroller/VCAP1: C3.1, IC1.43 (VCAP1)
/Microcontroller/VCAP2: C4.1, IC1.76 (VCAP2)
/OLED Socket/+12V: C20.1, C25.2, C27.1, D1.1, IC3.7 (FB), J3.2, J3.6, J3.8, J3.31
/OLED Socket/EXTCAP: C18.2, J3.3
/OLED Socket/EXTCAP2: C22.2, J3.4
/OLED Socket/EXTCAP3: C19.2, J3.5
/OLED Socket/SCK: IC1.81 (PC10), J3.22
/OLED Socket/SDI: IC1.90 (PD6), J3.23
/OLED Socket/~RST: IC1.89 (PD5), J3.18
/Power Supply/5VSB: J1.5, S2.2
/Power Supply/PSU_ON: J1.3, S2.4
/Power Supply/PW_OK: IC1.48 (PB14), J1.2
/Power Supply/PW_ON: IC1.47 (PB13), Q1.1
/SWD Pad/FLASH: D13.2, IC1.97 (BOOT0), J6.3, R3.2
/SWD Pad/SWCLK: D11.2, IC1.79 (PA14), J6.5
/SWD Pad/SWDIO: D11.1, IC1.75 (PA13), J6.6
/SWD Pad/SWO: D13.1, IC1.92 (PB3), J6.4
/SWD Pad/VCC: D10.2, D12.1, J6.1
/System Ethernet/CT_45: D4.4 (I/O1), D4.5 (I/O2), J4.4, J4.5, R20.1
/System Ethernet/CT_78: D5.4 (I/O1), D5.5 (I/O2), J4.7, J4.8, R21.1
/System Ethernet/GLED+: IC4.27 (LEDA), R22.2
/System Ethernet/RX+: D3.5 (I/O2), J4.3, T1.11 (RX+)
/System Ethernet/RX-: D3.4 (I/O1), J4.6, T1.9 (RX-)
/System Ethernet/TPIN+: IC4.13 (TPIN+), R16.1, T1.6 (RD+)
/System Ethernet/TPIN-: IC4.12 (TPIN-), R17.1, T1.8 (RD-)
/System Ethernet/TPOUT+: IC4.17 (TPOUT+), R14.1, T1.1 (TD+)
/System Ethernet/TPOUT-: IC4.16 (TPOUT-), R15.1, T1.3 (TD-)
/System Ethernet/TX+: D2.4 (I/O1), J4.1, T1.16 (TX+)
/System Ethernet/TX-: D2.5 (I/O2), J4.2, T1.14 (TX-)
/System Ethernet/YLED+: IC4.26 (LEDB), R23.2
GND: C1.2, C2.2, C3.2, C4.2, C5.1, C6.1, C7.1, C8.1, C9.1, C10.1, C11.1, C12.2, C13.1, C14.1, C15.2, C16.1, C17.1, C18.1, C19.1, C20.2, C21.1, C22.1, C23.1, C24.1, C26.2, C27.2, C28.1, C29.2, C30.2, C32.2, C35.2, C36.2, C37.1, C38.2, C39.2, C41.2, C44.2, C45.2, C48.2, C49.2, C50.1, C51.2, C52.1, H6.1, IC1.2 (VSS_1), IC1.7 (VSS_2), IC1.16 (VSSA), IC1.23 (VSS_3), IC1.44 (VSS_4), IC1.59 (VSSDSI), IC1.78 (VSS_5), IC2.3 (GND_1), IC2.6 (GND_2), IC3.5 (GND), IC4.2 (VSS), IC4.11 (VSSRX), IC4.18 (VSSTX), IC4.21 (VSSPLL), IC4.22 (VSSOSC), IC5.2 (VSS), IC5.11 (VSSRX), IC5.18 (VSSTX), IC5.21 (VSSPLL), IC5.22 (VSSOSC), IC6.15 (GND), IC7.4 (GND), J1.1, J3.10, J3.11, J4.10 (ANODE_YELLOW/CATHODE_GREEN_1), J4.11 (ANODE_GREEN/CATHODE_YELLOW_2), J5.10 (ANODE_YELLOW/CATHODE_GREEN_1), J5.11 (ANODE_GREEN/CATHODE_YELLOW_2), J6.2, Q1.2, R8.1, R10.1, R12.1, R13.2, R24.1, R25.2, R36.1, S1.1 (COM), S4.E2, S4.E3, X1.1 (GND/AFC), X1.3 (GND), Y1.2 (GND/CASE), Y2.2 (GND/CASE)
GNDPWR: C31.1, C40.1, D2.2 (GND), D3.2 (GND), D4.2 (GND), D5.2 (GND), D6.2 (GND), D7.2 (GND), D8.2 (GND), D9.2 (GND), D11.3, D12.2, D13.3, D14.2 (GND), D15.2 (GND), D16.1 (GND_1), D16.7 (GND_2), D16.8 (GND_3), D16.14 (GND_4), H1.1, H2.1, H3.1, H4.1, H5.1, J1.MH1, J1.MH2, J4.MH1, J4.MH2, J5.MH1, J5.MH2, S2.MH1, S2.MH2, S2.MH3, S2.MH4
unnamed: C29.1, R16.2, R17.2
unnamed: C31.2, R18.2, R19.2, R20.2, R21.2
unnamed: C38.1, R28.2, R29.2
unnamed: C40.2, R30.2, R31.2, R32.2, R33.2
unnamed: C1.1, IC1.11 (NRST), S1.2 (NO)
unnamed: IC1.37 (PE12), R4.1
unnamed: IC1.9 (PH0), X1.4 (CLK)
unnamed: IC2.5 (EN), R5.2
unnamed: C16.2, IC2.4 (NR/FB)
unnamed: C25.1, IC3.4 (COMP)
unnamed: IC3.1 (EN), R11.1
unnamed: D1.2, FB1.2, IC3.6 (OUT)
unnamed: C23.2, IC3.2 (REF)
unnamed: C24.2, IC3.3 (SS)
unnamed: IC4.23 (OSC1), Y1.3 (OUTPUT)
unnamed: IC4.14 (RBIAS), R13.1
unnamed: C28.2, IC4.1 (VCAP)
unnamed: IC4.9 (~CS), R12.2
unnamed: IC5.23 (OSC1), Y2.3 (OUTPUT)
unnamed: IC5.14 (RBIAS), R25.1
unnamed: C37.2, IC5.1 (VCAP)
unnamed: IC5.9 (~CS), R24.2
unnamed: IC6.14 (DOUT1), S3.1, S3.2
unnamed: IC6.7 (DOUT2), S3.7, S3.8
unnamed: IC6.13 (RIN1), S3.3, S3.4
unnamed: IC6.8 (RIN2), S3.5, S3.6
unnamed: IC7.2 (R_EXT), R36.2
unnamed: IC7.24 (~SDB), R37.2
unnamed: J3.13, R9.1
unnamed: J3.14, J3.16, J3.20, J3.24, J3.26, J3.28, R10.2
unnamed: J3.17, J3.19, J3.21, J3.25, J3.27, J3.29, R8.2
unnamed: J4.9 (ANODE_GREEN/CATHODE_YELLOW_1), R22.1
unnamed: J4.12 (ANODE_YELLOW/CATHODE_GREEN_2), R23.1
unnamed: J5.9 (ANODE_GREEN/CATHODE_YELLOW_1), R34.1
unnamed: J5.12 (ANODE_YELLOW/CATHODE_GREEN_2), R35.1
unnamed: LED1.1, R4.2
unnamed: LED2.2, R6.1
unnamed: LED3.1, R7.2
unnamed: Q1.3, S2.5
unnamed: C30.1, FB2.2, R14.2, R15.2, T1.2 (CT_1)
unnamed: R18.1, T1.10 (CT_3)
unnamed: R19.1, T1.15 (CT_4)
unnamed: C39.1, FB3.2, R26.2, R27.2, T2.2 (CT_1)
unnamed: R30.1, T2.10 (CT_3)
unnamed: R31.1, T2.15 (CT_4)

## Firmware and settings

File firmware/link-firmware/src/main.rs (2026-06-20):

#![no_std]
#![no_main]
#![feature(never_type)]
#![feature(adt_const_params)]
#![feature(unsafe_cell_access)]

pub(crate) mod atomic;
pub(crate) mod channel;
pub(crate) mod color;
pub(crate) mod crc32;
// pub(crate) mod flash;
pub(crate) mod font;
pub(crate) mod nvram;
pub(crate) mod rand;
pub(crate) mod redis;
pub(crate) mod service;
pub(crate) mod unique_id;
pub(crate) mod vars;
pub(crate) mod version;
pub(crate) mod wol;

use core::{cell::UnsafeCell, net::Ipv4Addr};

use defmt_rtt as _;
use embassy_embedded_hal::shared_bus::asynch::spi::SpiDevice;
use embassy_executor::Spawner;
use embassy_stm32::{
	Config, bind_interrupts, dma,
	exti::{self, ExtiInput},
	gpio::{Input, Level, Output, OutputOpenDrain, Pull, Speed},
	i2c, interrupt,
	mode::{Async, Blocking},
	peripherals, rcc, rng, spi,
	time::Hertz,
	usart, usb,
};
use embassy_sync::{blocking_mutex::raw::NoopRawMutex, mutex::Mutex, once_lock::OnceLock};
use embassy_time::{Delay, Duration, Timer};
use embedded_hal_bus::spi::ExclusiveDevice;
use panic_probe as _;
use static_cell::StaticCell;

use crate::nvram::{LastBootFailure, Volatile, VolatileLastBootFailure};

bind_interrupts!(struct Irqs {
	OTG_HS => usb::InterruptHandler<peripherals::USB_OTG_HS>;
	USART2 => usart::InterruptHandler<peripherals::USART2>;
	UART7 => usart::InterruptHandler<peripherals::UART7>;
	HASH_RNG => rng::InterruptHandler<peripherals::RNG>;
	DMA1_STREAM0 => dma::InterruptHandler<peripherals::DMA1_CH0>;
	DMA1_STREAM1 => dma::InterruptHandler<peripherals::DMA1_CH1>;
	DMA1_STREAM3 => dma::InterruptHandler<peripherals::DMA1_CH3>;
	DMA1_STREAM4 => dma::InterruptHandler<peripherals::DMA1_CH4>;
	DMA1_STREAM5 => dma::InterruptHandler<peripherals::DMA1_CH5>;
	DMA1_STREAM6 => dma::InterruptHandler<peripherals::DMA1_CH6>;
	DMA1_STREAM7 => dma::InterruptHandler<peripherals::DMA1_CH7>;
	DMA2_STREAM0 => dma::InterruptHandler<peripherals::DMA2_CH0>;
	DMA2_STREAM1 => dma::InterruptHandler<peripherals::DMA2_CH1>;
	EXTI15_10 => exti::InterruptHandler<interrupt::typelevel::EXTI15_10>;
	EXTI9_5 => exti::InterruptHandler<interrupt::typelevel::EXTI9_5>;
	EXTI4 => exti::InterruptHandler<interrupt::typelevel::EXTI4>;
	EXTI0 => exti::InterruptHandler<interrupt::typelevel::EXTI0>;
});

#[embassy_executor::main]
pub async fn main(spawner: Spawner) -> ! {
	// Initialize the chip's clock
	let mut config = Config::default();
	config.rcc.ls.rtc = rcc::RtcClockSource::Lsi;
	config.rcc.hse = Some(rcc::Hse {
		freq: Hertz::mhz(24),
		mode: rcc::HseMode::Oscillator,
	});
	config.rcc.pll_src = rcc::PllSource::Hse;
	config.rcc.ahb_pre = rcc::AHBPrescaler::Div1;
	config.rcc.sys = rcc::Sysclk::Pll1P;
	config.rcc.pll = Some(rcc::Pll {
		prediv: rcc::PllPreDiv::Div24,
		mul:    rcc::PllMul::Mul360,
		divp:   Some(rcc::PllPDiv::Div2),
		divq:   Some(rcc::PllQDiv::Div2),
		divr:   None,
	});
	config.rcc.pllsai = Some(rcc::Pll {
		prediv: rcc::PllPreDiv::Div24,
		mul:    rcc::PllMul::Mul192,
		divp:   None,
		divq:   Some(rcc::PllQDiv::Div4),
		divr:   None,
	});

	let mut clock_mux = rcc::mux::ClockMux::default();
	clock_mux.clk48sel = rcc::mux::Clk48sel::Pllsai1Q;
	config.rcc.mux = clock_mux;

	config.rcc.apb1_pre = rcc::APBPrescaler::Div4;
	config.rcc.apb2_pre = rcc::APBPrescaler::Div2;

	config.enable_debug_during_sleep = true;

	let p = embassy_stm32::init(config);

	defmt::info!("initializing oro link...");
	Timer::after(Duration::from_millis(100)).await;

	// MUST BE FIRST: initialize RNG
	// Nvram and a few other things require this. Must be before anything else.
	let rng_gen = rng::Rng::new(p.RNG, Irqs);
	self::rand::init_rng(rng_gen);

	// MUST BE SECOND: Initialize pflash subsystem
	// defmt::debug!("initializing flash");
	// flash::init_pflash(p.FLASH);

	// Check for reset sequence
	defmt::debug!("initializing nvram");
	let nv_ram = nvram::init();
	defmt::debug!("nvram contents: {:?}", nv_ram);

	if nv_ram.reboot.in_progress.read() {
		nv_ram
			.reboot
			.fast_count
			.write(nv_ram.reboot.fast_count.read() + 1);

		defmt::warn!(
			"detected reboot in progress from nvram; fast_reboot_count={}",
			nv_ram.reboot.fast_count.read()
		);
	}

	defmt::debug!(
		"current fast reboot count: {}",
		nv_ram.reboot.fast_count.read()
	);

	let last_boot_failure = nv_ram.failure.take_and_reset();
	match last_boot_failure {
		nvram::LastBootFailure::None => defmt::info!("last boot failure: {:?}", last_boot_failure),
		other => defmt::error!("last boot failure: {:?}", other),
	}
	crate::vars::STAT_LAST_BOOT_FAILURE
		.set(last_boot_failure.into())
		.await;

	// let pflash = match flash::read_pflash() {
	// 	Ok(pflash) => pflash,
	// 	Err(e) => {
	// 		defmt::warn!("failed to read pflash; reinitializing: {:?}", e);
	// 		// SAFETY: We're initializing it.
	// 		unsafe { flash::write_pflash(flash::Pflash::default()) }
	// 			.expect("failed to write/read-back default pflash")
	// 	}
	//};

	// let mut pflash = pflash.into_latest();
	// defmt::debug!("pflash contents: {:?}", pflash);

	if nv_ram.reboot.fast_count.read() >= 10 {
		nv_ram.reset();

		defmt::warn!(
			"detected {} fast reboots; starting Oro Link in initialization mode",
			nv_ram.reboot.fast_count
		);

		// pflash.initialized = false;

		// if let Err(err) = unsafe { flash::write_pflash(pflash) } {
		// 	defmt::error!(
		// 		"failed to reset pflash during fast reboot recovery; system is NOT reset: {:?}",
		// 		err
		// 	);
		//}

		defmt::warn!("Oro Link reset complete; rebooting system");

		// SAFETY: We're resetting the system.
		unsafe { self::reset() }
	}

	// let initialized = if pflash.initialized {
	// 	defmt::info!("system is initialized");
	// 	true
	//} else {
	// 	defmt::warn!("system is uninitialized; performing first-time setup");
	// 	nv_ram.reset();
	// 	false
	//};
	let initialized = true;

	crate::vars::STAT_INITIALIZED.set(initialized).await;
	crate::vars::STAT_VERSION_MAJOR
		.set(crate::version::VERSION_MAJOR as i64)
		.await;
	crate::vars::STAT_VERSION_MINOR
		.set(crate::version::VERSION_MINOR as i64)
		.await;
	crate::vars::STAT_VERSION_PATCH
		.set(crate::version::VERSION_PATCH as i64)
		.await;

	// This gets cleared on a successful boot later
	nv_ram.reboot.in_progress.write(true);

	// Begin initialization
	let debug_led1 = OutputOpenDrain::new(p.PD2, Level::High, Speed::Low);
	let debug_led2 = OutputOpenDrain::new(p.PB7, Level::High, Speed::Low);
	let debug_led3 = OutputOpenDrain::new(p.PC8, Level::High, Speed::Low);

	let ind_en = Output::new(p.PB8, Level::Low, Speed::Low);

	static I2C: StaticCell<Mutex<NoopRawMutex, i2c::I2c<'static, Blocking, i2c::mode::Master>>> =
		StaticCell::new();
	let i2c = I2C.init(Mutex::<NoopRawMutex, _>::new(i2c::I2c::new_blocking(
		p.I2C3,
		p.PA8,
		p.PC9,
		{
			let mut config = i2c::Config::default();
			config.scl_pullup = false;
			config.sda_pullup = false;
			config.timeout = Duration::from_millis(10);
			config.frequency = Hertz(400_000);
			config
		},
	)));

	let _usart = usart::Uart::new_with_rtscts(
		p.USART2,
		p.PD6,
		p.PA2,
		p.PA1,
		p.PD3,
		p.DMA1_CH6,
		p.DMA1_CH5,
		Irqs,
		{
			let mut config = usart::Config::default();
			config.baudrate = 115_200;
			config
		},
	)
	.unwrap();

	let usb_output_selector = Output::new(p.PA7, Level::High, Speed::Low);
	let ulpi_oc = ExtiInput::new(p.PB14, p.EXTI14, Pull::None, Irqs);
	let ulpi_rst = Output::new(p.PB15, Level::Low, Speed::Low);
	static EP_OUT_BUFFER: StaticCell<[u8; 256]> = StaticCell::new();
	let ep_out_buffer = EP_OUT_BUFFER.init([0; 256]);
	let ulpi = usb::Driver::new_hs_ulpi(
		p.USB_OTG_HS,
		Irqs,
		p.PA5,
		p.PC2,
		p.PC3,
		p.PC0,
		p.PA3,
		p.PB0,
		p.PB1,
		p.PB10,
		p.PB11,
		p.PB12,
		p.PB13,
		p.PB5,
		ep_out_buffer,
		{
			let mut config = usb::Config::default();
			config.vbus_detection = true;
			config.xcvrdly = true; // We're using a Microchip USB3340 PHY
			config
		},
	);

	static SPI3: StaticCell<Mutex<NoopRawMutex, spi::Spi<'static, Async, spi::mode::Master>>> =
		StaticCell::new();
	let spi3 = SPI3.init(Mutex::new(spi::Spi::new(
		p.SPI3,
		p.PC10,
		p.PC12,
		p.PC11,
		p.DMA1_CH7,
		p.DMA1_CH0,
		Irqs,
		{
			let mut config = spi::Config::default();
			config.frequency = Hertz(22_500_000);
			config.bit_order = spi::BitOrder::MsbFirst;
			config.mode = spi::MODE_0;
			config.miso_pull = Pull::Up;
			config
		},
	)));

	let sd_oc = ExtiInput::new(p.PA6, p.EXTI6, Pull::None, Irqs);
	let sd_sense = ExtiInput::new(p.PC13, p.EXTI13, Pull::None, Irqs);
	let _sd_sense_cable = ExtiInput::new(p.PD8, p.EXTI8, Pull::None, Irqs);
	// TODO(qix-): Switch back to open drain after pullup is added
	// let sd_en = OutputOpenDrain::new(p.PC14, Level::High, Speed::Low);
	let sd_en = OutputOpenDrain::new_pull(p.PC14, Level::High, Speed::Low, Pull::Up);
	let sd_cs = OutputOpenDrain::new_pull(p.PD5, Level::High, Speed::VeryHigh, Pull::Up);
	let sd_host_sut_sel = Output::new(p.PD14, Level::Low, Speed::Low);
	let sd_spi: &'static _ = spi3;

	let syseth_int = ExtiInput::new(p.PA4, p.EXTI4, Pull::None, Irqs);
	let mut syseth_rst = Output::new(p.PC15, Level::Low, Speed::VeryHigh);
	let syseth_cs = OutputOpenDrain::new(p.PD7, Level::High, Speed::VeryHigh);
	let syseth = SpiDevice::new(spi3, syseth_cs);
	let syseth_seed = self::rand::next_u64();
	reset_wiznet_chip(&mut syseth_rst).await;

	static SYSETH_STATE: StaticCell<embassy_net_wiznet::State<2, 2>> = StaticCell::new();
	let syseth_state = SYSETH_STATE.init(embassy_net_wiznet::State::<2, 2>::new());
	let (syseth_driver, syseth_wiznet_runner) = embassy_net_wiznet::new(
		syseth_mac_address(),
		syseth_state,
		syseth,
		syseth_int,
		syseth_rst,
	)
	.await
	.unwrap();

	static SYSETH_STACK: StaticCell<embassy_net::StackResources<16>> = StaticCell::new();
	let syseth_stack_resources = SYSETH_STACK.init(embassy_net::StackResources::<16>::new());
	let (_syseth_stack, syseth_net_runner) = embassy_net::new(
		syseth_driver,
		embassy_net::Config::ipv4_static({
			let mut cfg = embassy_net::StaticConfigV4 {
				address:     embassy_net::Ipv4Cidr::new(Ipv4Addr::from_octets([10, 0, 0, 1]), 8),
				dns_servers: Default::default(),
				gateway:     None,
			};
			cfg.dns_servers
				.push(Ipv4Addr::from_octets([10, 0, 0, 1]))
				.unwrap();
			cfg
		}),
		syseth_stack_resources,
		syseth_seed,
	);

	let (_uart_tx, uart_rx) =
		usart::Uart::new(p.UART7, p.PE7, p.PE8, p.DMA1_CH1, p.DMA1_CH3, Irqs, {
			let mut config = usart::Config::default();
			config.baudrate = 3_000_000;
			config.stop_bits = usart::StopBits::STOP1;
			config.parity = usart::Parity::ParityNone;
			config
		})
		.unwrap()
		.split();

	static UART_RX_BUFFER: StaticCell<[u8; 4096]> = StaticCell::new();
	let uart_rx_buffer = UART_RX_BUFFER.init([0u8; 4096]);
	let _uart_rx = uart_rx.into_ring_buffered(uart_rx_buffer);

	let exteth_int = ExtiInput::new(p.PA0, p.EXTI0, Pull::None, Irqs);
	let mut exteth_int_polarity = OutputOpenDrain::new(p.PB6, Level::Low, Speed::Low);
	exteth_int_polarity.set_low(); // Enable ethernet interrupt polarity (active low)
	let mut exteth_rst = OutputOpenDrain::new(p.PD0, Level::High, Speed::VeryHigh);
	let exteth_cs = OutputOpenDrain::new(p.PE11, Level::High, Speed::VeryHigh);
	let exteth = spi::Spi::new(
		p.SPI4,
		p.PE2,
		p.PE14,
		p.PE13,
		p.DMA2_CH1,
		p.DMA2_CH0,
		Irqs,
		{
			let mut config = spi::Config::default();
			config.frequency = Hertz(20_000_000);
			config
		},
	);
	let exteth_seed = self::rand::next_u64();
	let exteth = ExclusiveDevice::new(exteth, exteth_cs, Delay).unwrap();
	reset_wiznet_chip(&mut exteth_rst).await;

	static EXTETH_STATE: StaticCell<embassy_net_wiznet::State<2, 2>> = StaticCell::new();
	let exteth_state = EXTETH_STATE.init(embassy_net_wiznet::State::<2, 2>::new());
	let (exteth_driver, exteth_wiznet_runner) = embassy_net_wiznet::new(
		exteth_mac_address(),
		exteth_state,
		exteth,
		exteth_int,
		exteth_rst,
	)
	.await
	.unwrap();

	static EXTETH_STACK: StaticCell<embassy_net::StackResources<16>> = StaticCell::new();
	let exteth_stack_resources = EXTETH_STACK.init(embassy_net::StackResources::<16>::new());
	let (exteth_stack, exteth_net_runner) = embassy_net::new(
		exteth_driver,
		embassy_net::Config::dhcpv4(Default::default()),
		exteth_stack_resources,
		exteth_seed,
	);

	let oled_rst = Output::new(p.PD1, Level::High, Speed::Low);
	let oled_cs = OutputOpenDrain::new(p.PB9, Level::High, Speed::VeryHigh);
	let oled_dc = Output::new(p.PD4, Level::Low, Speed::VeryHigh);
	let oled_en = Output::new(p.PD9, Level::Low, Speed::Low);
	let oled = spi::Spi::new_txonly(p.SPI2, p.PA9, p.PC1, p.DMA1_CH4, Irqs, {
		let mut oledconf = spi::Config::default();
		oledconf.mode = spi::MODE_0;
		oledconf.bit_order = spi::BitOrder::MsbFirst;
		oledconf.frequency = Hertz(4_000_000);
		oledconf
	});

	let _gpio2 = Output::new(p.PC7, Level::Low, Speed::Low);
	let _gpio3 = Output::new(p.PA10, Level::Low, Speed::Low);
	let _gpio4 = Output::new(p.PC6, Level::Low, Speed::Low);
	let _gpio5 = Output::new(p.PB4, Level::Low, Speed::Low);

	let vbus_oc = ExtiInput::new(p.PD15, p.EXTI15, Pull::None, Irqs);
	let vbus_en = Output::new(p.PE15, Level::Low, Speed::Low);
	let aux_vbus_sense_pin = Input::new(p.PA11, Pull::None);
	// Have we sensed the aux vbus line?
	let aux_vbus_sense = aux_vbus_sense_pin.is_low();
	crate::vars::STAT_AUX_VBUS_SENSE.set(aux_vbus_sense).await;
	let aux_vbus_oc = ExtiInput::new(p.PA12, p.EXTI12, Pull::None, Irqs);
	let aux_vbus_en = OutputOpenDrain::new(p.PA15, Level::High, Speed::Low);
	// TODO: Set `Pull::None` once external pull-up has been added
	// TODO: https://github.com/oro-os/link/issues/112
	let board_power_alert = ExtiInput::new(p.PE9, p.EXTI9, Pull::Up, Irqs);
	let psu_on = Output::new(p.PD10, Level::Low, Speed::Low);
	let _sut_pwr_switch = Output::new(p.PE12, Level::Low, Speed::Low);
	let _sut_rst_switch = Output::new(p.PE10, Level::Low, Speed::Low);

	defmt::info!("initialization complete; starting services...");

	static FAILURE_REF: StaticCell<UnsafeCell<&'static mut Volatile<LastBootFailure>>> =
		StaticCell::new();
	let failure = FAILURE_REF.init(UnsafeCell::new(&mut nv_ram.failure));

	service_config! {
		dev_blinken_light {
			debug_led1,
			debug_led2,
			debug_led3,
		},
		dev_exteth {
			wiznet_runner: exteth_wiznet_runner,
			net_runner: exteth_net_runner,
		},
		dev_leds {
			spawner,
			i2c,
			enable_chip: ind_en,
		},
		dev_oled {
			spi: oled,
			cs: oled_cs,
			dc: oled_dc,
			rst: oled_rst,
			vreg_en: oled_en,
		},
		dev_power_monitor {
			i2c,
		},
		dev_sdcard {
			sd: sd_spi,
			sd_cs,
			sd_en,
			sd_sense,
			sd_host_sut_sel,
		},
		dev_syseth {
			wiznet_runner: syseth_wiznet_runner,
			net_runner: syseth_net_runner,
		},
		dev_usb {
			driver: ulpi,
			ulpi_rst,
		},
		svc_main {
			aux_vbus_sense,
			last_boot_failure,
			usb_output_selector
		},
		failsafe_board_oc {
			board_power_alert,
			failure
		},
		failsafe_aux_vbus_oc {
			aux_vbus_oc,
			failure
		},
		failsafe_ulpi_oc {
			ulpi_oc,
			failure
		},
		failsafe_sd_oc {
			sd_oc,
			failure
		},
		svc_vbus_power {
			aux_vbus_sense,
			aux_vbus_en,
			vbus_en,
			vbus_oc,
			failure
		},
		svc_psu {
			psu_on
		},
		//svc_qup {
		//	stack: exteth_stack
		//},
		svc_mdns {
			stack: exteth_stack
		},
		svc_redis {
			stack: exteth_stack
		},
	}
	.spawn_all(spawner);

	defmt::info!("all services have been spawned");

	Timer::after(Duration::from_secs(5)).await;
	defmt::debug!("marking boot as successful");
	nv_ram.reboot.reset();

	loop {
		Timer::after_secs(3600).await;
	}
}

fn exteth_mac_address() -> [u8; 6] {
	let hash = self::unique_id::unique_id_sha256();

	let mut macaddr = [0u8; 6];
	macaddr[0] = b'.';
	macaddr[1] = b'o';
	macaddr[2] = b'O';
	macaddr[3] = hash[29];
	macaddr[4] = hash[30];
	macaddr[5] = hash[31];

	macaddr
}

pub fn unique_id() -> &'static str {
	static ID: OnceLock<[u8; 6 * 2 + 5]> = OnceLock::new();
	let id = ID.get_or_init(|| {
		let mac = exteth_mac_address();
		let mut id = [b'-'; { 6 * 2 + 5 }];
		for (i, b) in mac.iter().enumerate() {
			let b = *b;
			id[i * 3] = ((b >> 4) & 0xF).hex_digit();
			id[i * 3 + 1] = (b & 0xF).hex_digit();
		}
		id
	});

	// SAFETY: We can assert it's correct.
	unsafe { core::str::from_utf8_unchecked(id) }
}

fn syseth_mac_address() -> [u8; 6] {
	let mut macaddr = [0u8; 6];
	macaddr[0] = b'.';
	macaddr[1] = b'o';
	macaddr[2] = b'O';
	macaddr[3] = 0;
	macaddr[4] = 0;
	macaddr[5] = 0;

	macaddr
}

async fn reset_wiznet_chip<P: embedded_hal::digital::OutputPin>(pin: &mut P) {
	Timer::after_millis(100).await;
	let _ = pin.set_low();
	Timer::after_millis(100).await;
	let _ = pin.set_high();
	Timer::after_millis(100).await;
}

/// # Safety
/// This will immediately reset the system. Use with caution.
pub unsafe fn reset() -> ! {
	defmt::warn!("performing system reset!");
	cortex_m::peripheral::SCB::sys_reset();
	#[expect(unreachable_code)]
	{
		panic!("system reset failed");
	}
}

trait HexDigit {
	fn hex_digit(self) -> u8;
}

impl HexDigit for u8 {
	fn hex_digit(self) -> u8 {
		match self {
			0..=9 => b'0' + self,
			10..=15 => b'A' + (self - 10),
			_ => b'_',
		}
	}
}

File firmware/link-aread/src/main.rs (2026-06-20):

#![feature(never_type)]

use anyhow::{Context, Result};
use clap::Parser;

#[derive(Debug, Parser)]
struct Args {
	/// The path to the area controller's public key.
	#[arg(long = "pub")]
	pubkey:        String,
	/// The path to the area controller's private key.
	#[arg(long = "priv")]
	privkey:       String,
	/// The path to the daemon's public key.
	#[arg(long = "daemon")]
	daemon_pubkey: String,
}

async fn pmain() -> Result<()> {
	log::info!("Hello, world!");
	run_mdns_service().await?;
}

#[tokio::main]
async fn main() {
	env_logger::builder()
		.filter_level(log::LevelFilter::Debug)
		.parse_default_env()
		.init();

	if let Err(e) = pmain().await {
		log::error!("fatal error: {e}");
		std::process::exit(1);
	}

	log::warn!("oro link area controller is exiting gracefully");
}

async fn run_mdns_service() -> Result<!> {
	let mdns = mdns_sd::ServiceDaemon::new().context("failed to create mDNS service daemon")?;

	let receiver = mdns
		.monitor()
		.context("failed to create mDNS service monitor")?;

	let service = mdns_sd::ServiceInfo::new::<&str, &[(&str, &str)]>(
		"_oro-link-aread._tcp.local.",
		"DBG_INSTANCE",
		"192.168.50.198.local.",
		"192.168.50.198",
		7778,
		&([])[..],
	)
	.context("failed to create mDNS service info")?;

	mdns.register(service)
		.context("failed to register mDNS service")?;

	loop {
		let event = receiver
			.recv_async()
			.await
			.context("failed to receive mDNS event")?;
		log::debug!("mDNS event: {event:?}");
	}
}

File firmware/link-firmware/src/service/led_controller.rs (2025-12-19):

use embassy_executor::Spawner;
use embassy_stm32::{
	gpio::Output,
	i2c::{I2c, mode::Master},
	mode::Blocking,
};
use embassy_sync::{blocking_mutex::raw::NoopRawMutex, mutex::Mutex};
use embassy_time::{Duration, Timer};
use static_cell::StaticCell;

use crate::{
	channel::{Channel as RawChannel, ChannelExt, Receiver, Sender},
	color::Rgb,
};

const ADDR: u8 = 0b01111000 >> 1;
const MAX_CURRENT: MaxCurrent = MaxCurrent::ImaxDiv4;
const SHIFT_CHANNEL: usize = 0; // Channel 0 is a "special" channel that sets the brightness shift for all channels.
const IDLE_SHIFT: u8 = 4; // Divide by 16.
const IDLE_MIN: u8 = 2; // Minimum brightness in idle mode (for non-zero brightness).

pub type Channel = RawChannel<Message, 4>;

type RgbReceiver = Receiver<Rgb, 2>;
type LightSender = Sender<(usize, u8), 16>;
type OnOffReceiver = Receiver<bool, 2>;
type GreyReceiver = Receiver<u8, 2>;

#[derive(defmt::Format)]
#[allow(unused)]
pub enum Message {
	/// Turns off all lights
	AllOff,
	/// Performs a self-test sequence; no
	/// commands will be processed until
	/// the self-test is complete.
	SelfTest,
	/// Sets the controller to idle mode,
	/// dimming all lights.
	SetIdle(bool),
	/// Sets the backlight color.
	///
	/// Specifying `None` turns off the backlight.
	SetBacklight(Rgb),
	/// Sets the system indicator color.
	///
	/// Specifying `None` turns off the system indicator.
	SetSystemIndicator(Rgb),
	/// Sets the remote indicator color.
	///
	/// Specifying `None` turns off the remote indicator.
	SetRemoteIndicator(Rgb),
	/// Sets the job indicator color.
	///
	/// Specifying `None` turns off the job indicator.
	SetJobIndicator(Rgb),
	/// Sets the SD ribbon cable (SUT) sense indicator on or off.
	SetSdCableIndicator(bool),
	/// Sets the SD card activity indicator on or off.
	SetSdCardIndicator(bool),
	/// Sets the SD card sense indicator on or off.
	SetSdSenseIndicator(bool),
}

#[embassy_executor::task]
pub async fn led_controller(
	spawner: Spawner,
	recv: <Channel as ChannelExt>::Receiver,
	i2c: &'static Mutex<NoopRawMutex, I2c<'static, Blocking, Master>>,
	mut enable_chip: Output<'static>,
) -> ! {
	enable_chip.set_high();
	Timer::after(Duration::from_millis(100)).await;

	let mut led = IS31FL3236A::new(i2c);
	led.reset().await;
	Timer::after(Duration::from_millis(1)).await;
	led.set_is_shutdown(false).await;
	led.enable_all_channels().await;
	Timer::after(Duration::from_millis(1)).await;
	led.set_frequency(OutputFrequency::Khz3).await;

	for channel in 1..=36 {
		led.set_ch_state(
			channel,
			ChannelState::new().with_max_current(MAX_CURRENT).with_on(),
		);
		led.set_pwm(channel, 0);
	}
	led.present_state().await;
	led.present_pwm().await;

	static LIGHT_CHANNEL: static_cell::StaticCell<RawChannel<(usize, u8), 16>> =
		static_cell::StaticCell::new();
	let light_ch = LIGHT_CHANNEL.init(RawChannel::new());

	macro_rules! setup_lights {
		($(let $name:ident = $ty:tt($($tt:tt)+));+ $(;)?) => {
			$(
				let $name = setup_lights!(@task $ty($($tt)+));
			)+
		};
		(@task Rgb($ch_r:expr, $ch_g:expr, $ch_b:expr)) => {
			{
				static CHANNEL: StaticCell<RawChannel<Rgb, 2>> = StaticCell::new();
				let ch = CHANNEL.init(RawChannel::new());
				let rx = ch.receiver();
				spawner.spawn(rgb_light_task(rx, light_ch.sender(), $ch_r, $ch_g, $ch_b)).unwrap();
				ch.sender()
			}
		};
		(@task OnOff($ch_bool:expr)) => {
			{
				static CHANNEL: StaticCell<RawChannel<bool, 2>> = StaticCell::new();
				let ch = CHANNEL.init(RawChannel::new());
				let rx = ch.receiver();
				spawner.spawn(on_off_light_task(rx, light_ch.sender(), $ch_bool)).unwrap();
				ch.sender()
			}
		};
		(@task MultiRgb($([$r:expr, $g:expr, $b:expr]),* $(,)?)) => {
			{
				static CH_R: &'static [usize] = &[$($r),*];
				static CH_G: &'static [usize] = &[$($g),*];
				static CH_B: &'static [usize] = &[$($b),*];
				static CHANNEL: StaticCell<RawChannel<Rgb, 2>> = StaticCell::new();
				let ch = CHANNEL.init(RawChannel::new());
				let rx = ch.receiver();
				spawner.spawn(multi_rgb_light_task(rx, light_ch.sender(), CH_R, CH_G, CH_B)).unwrap();
				ch.sender()
			}
		};
		(@task MultiGrey($($ch_grey:expr),* $(,)?)) => {
			{
				static CH_GREY: &'static [usize] = &[$($ch_grey),*];
				static CHANNEL: StaticCell<RawChannel<u8, 2>> = StaticCell::new();
				let ch = CHANNEL.init(RawChannel::new());
				let rx = ch.receiver();
				spawner.spawn(multi_grey_light_task(rx, light_ch.sender(), CH_GREY)).unwrap();
				ch.sender()
			}
		};
	}

	setup_lights! {
		// SD card lights
		// These are subject to change - see
		// https://github.com/oro-os/link/issues/109
		let sd_cable_sense_led = OnOff(36);
		let sd_card_activity_led = OnOff(2);
		let sd_card_sense_led = OnOff(1);

		// Status lights
		let remote_link_led = Rgb(31, 30, 32);
		let job_indicator_led = Rgb(28, 29, 27);
		let system_indicator_led = Rgb(34, 33, 35);

		// Backlight
		let backlight_rgb_led = MultiRgb(
			[19, 18, 20],
			[10, 9, 11],
			[5, 6, 4],
			[15, 16, 17],
			[13, 12, 14],
			[25, 26, 24],
			[21, 22, 23],
		);

		let backlight_white_led = MultiGrey(7, 8, 3);
	}

	spawner
		.spawn(presenter_task(light_ch.receiver(), led))
		.unwrap();

	loop {
		let msg = recv.receive().await;
		match msg {
			Message::AllOff => {
				for channel in 1..=36 {
					light_ch.send((channel, 0)).await;
				}
			}
			Message::SelfTest => {
				for _ in 0..3 {
					for channel in 1..=36 {
						light_ch.send((channel, 255)).await;
					}
					Timer::after(Duration::from_millis(500)).await;
					for channel in 1..=36 {
						light_ch.send((channel, 0)).await;
					}
					Timer::after(Duration::from_millis(500)).await;
				}
			}
			Message::SetIdle(is_idle) => {
				light_ch
					.send((SHIFT_CHANNEL, if is_idle { IDLE_SHIFT } else { 0 }))
					.await;
			}
			Message::SetJobIndicator(rgb) => {
				job_indicator_led.send(rgb).await;
			}
			Message::SetRemoteIndicator(rgb) => {
				remote_link_led.send(rgb).await;
			}
			Message::SetSystemIndicator(rgb) => {
				system_indicator_led.send(rgb).await;
			}
			Message::SetBacklight(rgb) => {
				backlight_rgb_led.send(rgb.without_white_component()).await;
				backlight_white_led.send(rgb.white_component()).await;
			}
			Message::SetSdCableIndicator(on) => {
				sd_cable_sense_led.send(on).await;
			}
			Message::SetSdCardIndicator(on) => {
				sd_card_activity_led.send(on).await;
			}
			Message::SetSdSenseIndicator(on) => {
				sd_card_sense_led.send(on).await;
			}
		}
	}
}
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

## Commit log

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2023-03-07 correct alignment of 5v to 3v3 converter
    [power-supply.kicad_sch]
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2023-03-22 fix a few traces
2023-04-05 fix a few more traces
2023-04-05 fix up silkscreen and add a few more GND stitches
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2023-04-30 replace switch with 25146NAH
    [power-supply.kicad_sch]
2023-04-30 switch OLED to 4-wire serial and add CS line to OLED/ethernet chips
    [OroLink.kicad_sch, ethernet.kicad_sch, microcontroller.kicad_sch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]
2023-04-30 remove RS232 DIPs and ESD, and remove redundant header pins
    [OroLink.kicad_sch, com-bus-header.kicad_sch, ethernet.kicad_sch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]
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2023-04-30 fix OLED note: 3-LINE SPI -> 4-WIRE SPI
    [oled-socket.kicad_sch]
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2023-04-30 fix resistor part numbers for ethernet lines
    [OroLink.kicad_sch, ethernet.kicad_sch, oled-socket.kicad_sch]
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2023-04-30 use vertical power connector instead of right angle
    [com-bus-header.kicad_sch, ethernet.kicad_sch, indicator-lights.kicad_sch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]
2023-04-30 increase Rext size for indicator lights to dampen their max brightness
    [indicator-lights.kicad_sch]
2023-04-30 add debug througholes for wiring up debug lines
    [front-panel-client.kicad_sch, indicator-lights.kicad_sch, microcontroller.kicad_sch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]
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2023-05-03 initial routing of entire board without debug THT's
    [OroLink.kicad_pcb, OroLink.kicad_sch, com-bus-header.kicad_sch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]
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2023-05-03 correct impedance control value in board characteristics block
    [OroLink.kicad_pcb]
2023-05-06 fix i2c pull-up resistor footprint mismatch
    [OroLink.kicad_pcb, microcontroller.kicad_sch]
2023-05-06 remove extraneous trace from GND debug pin to GND power port pin
    [OroLink.kicad_pcb]
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2023-05-06 fix keepout zones on Oro 6p connector and update footprint on PCB
    [OroLink.kicad_pcb]
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2023-05-06 change OLED voltage converter to compatible (in-stock) part
    [oled-socket.kicad_sch]
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2023-05-13 fix programmer PCB inspector faults
    [OroLinkProgrammer.kicad_pcb]
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2023-05-13 swap switch position and bring high resistor down into more suitable position
    [OroLinkProgrammer.kicad_pcb]
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2023-05-13 add second brace to board and reduce ground fill
    [OroLinkProgrammer.kicad_pcb]
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2023-05-19 switch MCU debug LED to direct drive (closes #7)
    [microcontroller.kicad_sch]
2023-05-19 remove ESD ICs from ethernet port (closes #23)
    [ethernet.kicad_sch]
2023-05-19 tie NRST to ground on programmer (closes #4)
    [OroLinkProgrammer.kicad_sch]
2023-05-21 combine mounting holes and create lipped pin slots (closes #27)
    [Outline.FCStd]
2023-05-21 change boot configuration lines and switches; replace 555 with 3v3 vers.
    ref #3
    closes #5
    [OroLinkProgrammer.kicad_sch]
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2023-05-21 add 1nf 3kv caps to GNDPWR mounting holes (closes #29)
    [OroLink.kicad_sch]
2023-05-21 switch to self-contained magnetics ethernet jack (closes #28)
    [OroLink.kicad_sch, ethernet.kicad_sch, microcontroller.kicad_sch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]
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2023-05-21 add pullup/down resistors and fix oro 6p lines with boot1/0
    closes #24
    closes #21
    closes #15
    closes #12
    closes #6
    closes #3
    [OroLink.kicad_sch, com-bus-header.kicad_sch, ethernet.kicad_sch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]
2023-05-21 put pulldowns on unused OLED data lines and add a 510k to pin 13
    [ethernet.kicad_sch, indicator-lights.kicad_sch, oled-socket.kicad_sch]
2023-05-30 replace 0.1u caps with larger package (closes #2)
    [com-bus-header.kicad_sch, microcontroller.kicad_sch]
2023-05-30 add debug pins to signal lines (closes #16)
    [com-bus-header.kicad_sch, ethernet.kicad_sch, indicator-lights.kicad_sch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]
2023-05-30 replace 49.9R resistors with larger package (closes #20)
    [ethernet.kicad_sch]
2023-05-30 switch 10k and 4.7k resistors to smaller packages (closes #32)
    [ethernet.kicad_sch, front-panel-client.kicad_sch, indicator-lights.kicad_sch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]
2023-05-30 switch to smaller package for 1nF 3kV caps (closes #33)
    [OroLink.kicad_sch]
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2023-05-31 fix power switch footprint (closes #13)
    [OroLink.kicad_pcb]
2023-05-31 make shottky diode footprint a bit more obvious (closes #17)
    [oled-socket.kicad_sch]
2023-05-31 replace remaining 0.1u caps with larger packages (ref #2)
    [ethernet.kicad_sch, indicator-lights.kicad_sch]
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2023-06-02 don't use global earth power symbol for ethernet earths
    [OroLink.kicad_pcb, ethernet.kicad_sch]
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2023-06-02 silkscreen, via, and comment polishing
    This isn't the change for the following issues, which were all addressed
    over the last few commits, collectively. Sorry for the messiness.
    Closes #30
    Closes #26
    Closes #25
    Closes #9
    [OroLink.kicad_pcb, com-bus-header.kicad_sch, ethernet.kicad_sch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]
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2023-06-02 add positioning markers to programmer pieces (closes #31)
    [OroLinkProgrammer.kicad_pcb]
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2023-06-03 fix mouser ID on MSAST1L3YB5104KFNA01 caps
    [com-bus-header.kicad_sch, ethernet.kicad_sch, indicator-lights.kicad_sch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]
2023-06-03 fix remaining missing mouser ID BOM entries
    [ethernet.kicad_sch, indicator-lights.kicad_sch]
2023-06-03 fix mouser and mfr ID for programmer test probes
    [OroLinkProgrammer.kicad_sch]
2023-06-03 add ground stitch near debug SWO pins on programmer
    [OroLinkProgrammer.kicad_pcb]
2023-06-03 fix revision and date on programmer backside
    [OroLinkProgrammer.kicad_pcb]
2023-06-09 add VGA 12v adapter + VGA mount board
    [VGADisplayCard.kicad_pcb, VGADisplayCard.kicad_sch]
2023-06-09 update for gerber generation of vga pcie board
    [VGADisplayCard.kicad_pcb]
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2023-07-01 reverse BOOT0/BOOT1 pull-up/-down resistor configuration (fixes #41)
    [microcontroller.kicad_sch]
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2023-07-01 fix no-connection markers for indicator lights
    [indicator-lights.kicad_sch]
2023-07-01 eliminate power switch in lieu of direct power + sys s.b. mosfet (closes #38)
    [OroLink.kicad_sch, microcontroller.kicad_sch, power-supply.kicad_sch]
2023-07-02 eliminate programmer SWD pad in lieu of edge connector / minie (closes #40, closes #42)
    [OroLink.kicad_sch, OroLinkProgrammer.kicad_pcb, OroLinkProgrammer.kicad_sch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]
2023-07-02 vga mount polish and 2.54mm mount (closes #37)
    [VGADisplayCard.kicad_pcb, VGADisplayCard.kicad_sch]
2023-07-02 switch out linear regular for one with larger max current (closes #43)
    [com-bus-header.kicad_sch, ethernet.kicad_sch, front-panel-client.kicad_sch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]
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2023-07-14 flip pins on OLED socket (fixes #47)
    [OroLink.kicad_pcb, oled-socket.kicad_sch]
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2023-07-14 add missing PSU standby enable line
    [OroLink.kicad_pcb, power-supply.kicad_sch]
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2023-07-21 replace firmware with rust hello world firmware
    [main.rs]
2023-07-21 fix page numbers on x86 pcb schematic
    [OroLink.kicad_sch]
2023-07-23 fix up firmware boilerplate
    [main.rs]
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2023-07-28 remove MOSFETs on indicator lights and OLED (ref #48)
    [indicator-lights.kicad_sch, oled-socket.kicad_sch]
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2023-08-02 clean up colors and fix blue
    [main.rs]
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2023-08-04 [no-ci] fix MAC vendor prefix
    [main.rs]
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2023-08-04 increase timeout for power/reset default pulse times to 100ms
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2023-08-08 add minimum resistor value for current limiting resistor
    [indicator-lights.kicad_sch]
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2023-10-16 fix packet transmission sniffing
    [main.rs]
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2023-10-20 fix daemon builds on non-linux machines
    [main.rs]
2023-10-20 add initial broker channel and command
    [main.rs]
2023-10-22 fix link packet transmission
    [main.rs]
2023-10-22 fix link packet reception
    [main.rs]
2023-10-23 fix some clippy lints and remove some unused code
    [main.rs]
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2023-10-23 pass packets directly to broker instead of translating in daemon
    [main.rs]
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2023-10-26 add broker: prefix for link reset warning
    [main.rs]
2023-10-26 detect when daemon loses connection and reset
    [main.rs]
2023-10-26 handle shuttling TFTP errors back to the SUT
    [main.rs]
2023-10-26 fix logging features in daemon
    [main.rs]
2023-11-12 correctly parameterize PXE DHCP boot sizes and move to passthrough TFTP packet forwarding to daemon
    [main.rs]
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2023-11-21 ignore spurious stdout/stderr errors if child has exited
    [main.rs]
2023-11-21 fix improper child status checking
    [main.rs]
2023-11-22 don't crash on unexpected tftp ACKs
    [main.rs]
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2023-11-23 add initial rpi-base board project and commons lib
    [LQFP100_STM.step, LinkRpiBase.kicad_pcb, LinkRpiBase.kicad_sch]
2024-06-02 upgrade embassy (and fix OLED, somehow)
    [main.rs]
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2024-06-08 omit ethernet enable mosfets in lieu of reset mosfet
    [OroLink.kicad_pcb, OroLink.kicad_sch, ethernet.kicad_sch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]
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2024-06-08 make top right mounting hole grounded (closes #51)
    [OroLink.kicad_pcb, OroLink.kicad_sch]
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2025-05-18 disable power-only USB vbus by default (workaround for #54)
    [main.rs]
2025-05-29 fix LDO pins (ref #54)
    [power.kicad_sch]
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2025-05-29 replace 82R resistors on ethernet circuits with 49R9 (ref #60)
    [w5500-ethernet.kicad_sch]
2025-05-29 correct magjack wiring (ref #61)
    [w5500-ethernet.kicad_sch]
2025-05-29 fix ULPI PHY wiring (ref #62)
    [usb.kicad_sch]
2025-05-29 fix OLED port wiring (ref #63)
    [oled.kicad_sch]
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2025-05-29 pull pins 1 and 3 down to ground too (ref #84)
    [power.kicad_sch]
2025-05-30 re-format OLED (ref #63), pull down DC (ref #70) and remove RST TP (closes #93)
    [oled.kicad_sch]
2025-05-30 remove additional 12V VIN bypass caps (closes #94)
    [oled.kicad_sch]
2025-05-30 fix OLED SS capacitor value (closes #71)
    [oled.kicad_sch]
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2025-05-30 add power monitor alert interrupt line (ref #82)
    [link.kicad_sch, power.kicad_sch]
2025-05-30 add pullup on USART CTS/TX lines (ref #67)
    [link.kicad_sch]
2025-05-30 pull up external ethernet ~{RST} line (ref #74)
    [link.kicad_sch, w5500-ethernet.kicad_sch]
2025-05-30 separate VBUS/PSU control lines (ref #89) and pull up VBUS enable (ref #68)
    [link.kicad_sch, power.kicad_sch]
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2025-05-30 convert an RGB backlight into 3 white channels (ref #83)
    [indicator-lights.kicad_sch]
2025-05-30 replace WOL AND gate with XOR gate (ref #65)
    [link.kicad_sch]
2025-05-30 replace ethernet clocks with more robust unit (ref #72)
    [w5500-ethernet.kicad_sch]
2025-05-30 replace USB-C receptacle (ref #73)
    [power.kicad_sch, usb.kicad_sch]
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2025-06-02 put sdcard vcc on switch instead of source from gpio (ref #97)
    [link.kicad_sch, microsd.kicad_sch]
2025-06-02 replace microsd slot (ref #95) and triangulate debug leds
    [microsd.kicad_sch]
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2025-06-02 add missing LED labels (fixes #81)
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2025-06-05 put PSU ON on a MOSFET (ref #99) and fix USB THT pads
    [link.kicad_sch, power.kicad_sch]
2025-06-06 remove rs232 charge pump (ref #102), add pwr/reset circuits (fixes #100)
    [link.kicad_sch, uart-rs232.kicad_sch, w5500-ethernet.kicad_sch]
2025-06-06 update GPIO numbering (fixes #101)
    [link.kicad_sch]
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2025-06-07 switch to 8 layer board, subtract mask from edges (fixes #77)
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2025-06-12 add more edge plating mount slots for manu (fixes #98, fixes #79)
2025-06-13 fix solder mask on bottom right detail
2025-06-13 fix 12v LDO capacitor ref-deg silkscreen
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2025-12-19 move new PCB files out of `pcb_new` into `pcb` and remove old `pcb`
    [48LQFP_W5500_WIZ.step, 67996-402HLF.stp, LQFP100_STM.step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]
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2025-12-20 implement NVRAM and fast-reboot detection
    [main.rs]
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2026-04-08 fix power state stats
    [dev_oled.rs, main.rs, svc_oled_pwr.rs]
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2026-04-12 add vbus power driver and OC failsafes
    [main.rs]
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2026-04-12 add ulpi oc failsafe
    [main.rs]
2026-04-12 add SD OC failsafe
    [main.rs]

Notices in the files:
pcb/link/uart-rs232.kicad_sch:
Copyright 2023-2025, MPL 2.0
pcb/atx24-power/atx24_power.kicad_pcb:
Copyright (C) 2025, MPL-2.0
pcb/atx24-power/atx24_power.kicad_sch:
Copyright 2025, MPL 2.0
